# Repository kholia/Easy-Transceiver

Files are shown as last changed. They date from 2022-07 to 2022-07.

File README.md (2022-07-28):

### Easy-Transceiver

The whole design is modular, parametric (cost and others), field repairable,
and super extensible. It is almost trivial to add support for more `FSK digital
modes`.

The `Easy-Transceiver` hardware works with the native `Hybrid FT8 Radio`
Android app, and also with WSJT-X (running on RPi).

The `Easy-Transceiver` system can be built for around 3000 INR (~40 USD) or
less. We are working on reducing the cost to 2300 INR ;)

Author 1: LU2HES - https://github.com/agustinmartino

Author 2: Dhiru Kholia (VU3CER) - https://www.qrz.com/db/VU3CER/

TX chain:

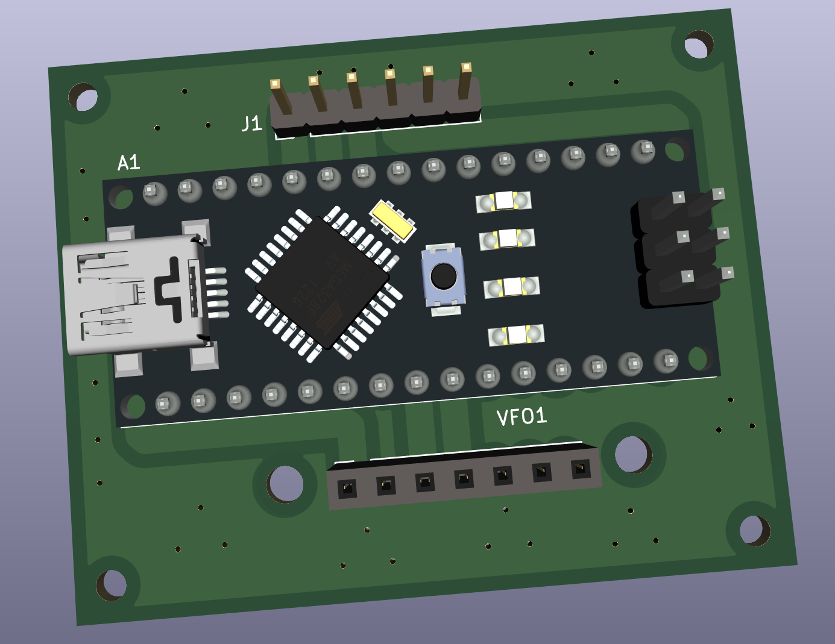
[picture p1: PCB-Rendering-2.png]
PCB-Rendering


RX chain (Easy-uSDX - optionally headless):

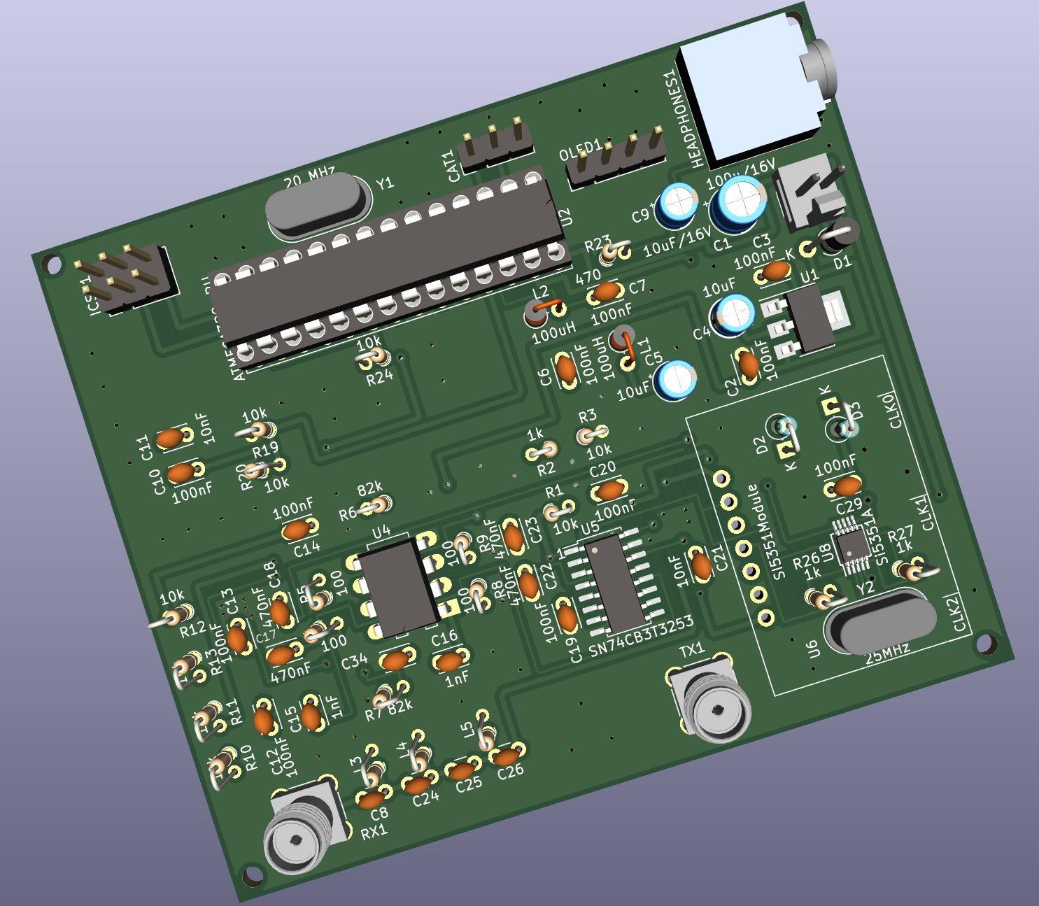
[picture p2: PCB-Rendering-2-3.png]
PCB-Rendering


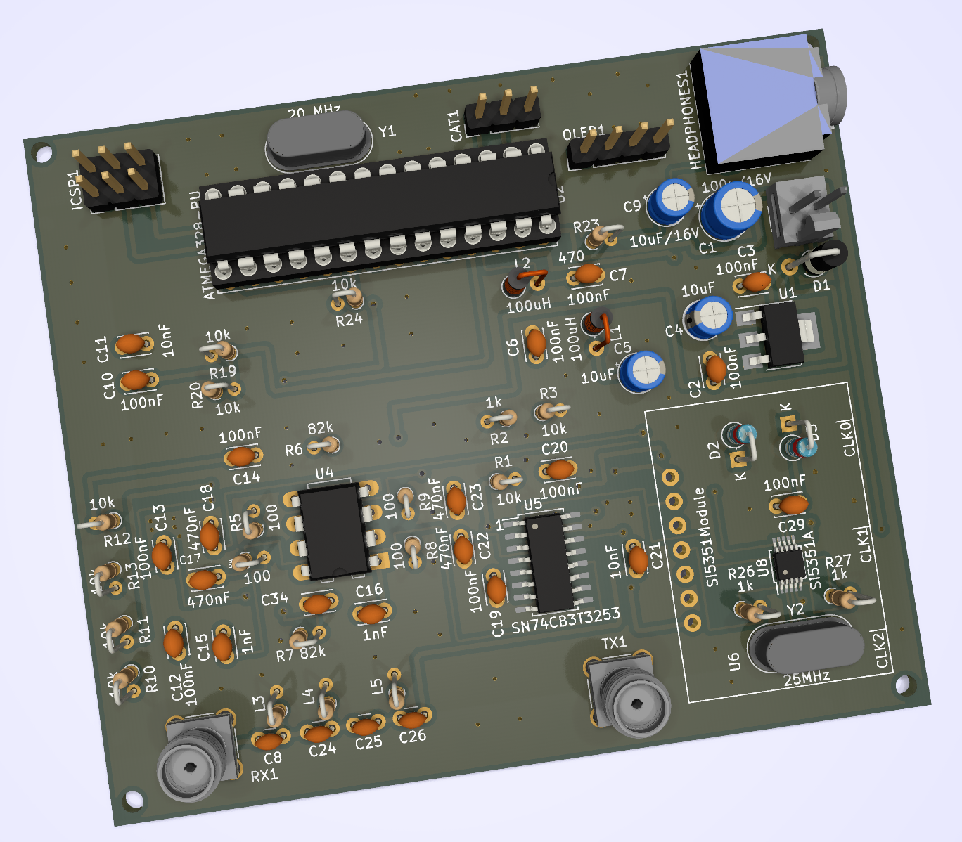
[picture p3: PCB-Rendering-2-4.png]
PCB-Rendering


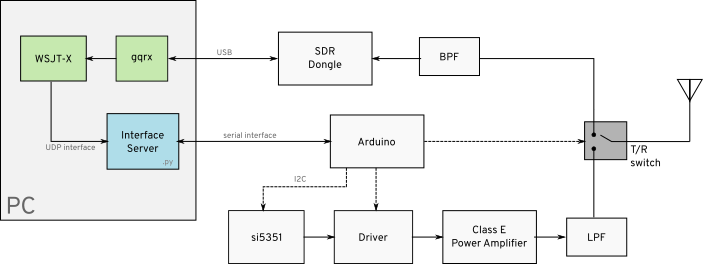
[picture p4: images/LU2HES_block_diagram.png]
Big Picture


QSO(s):

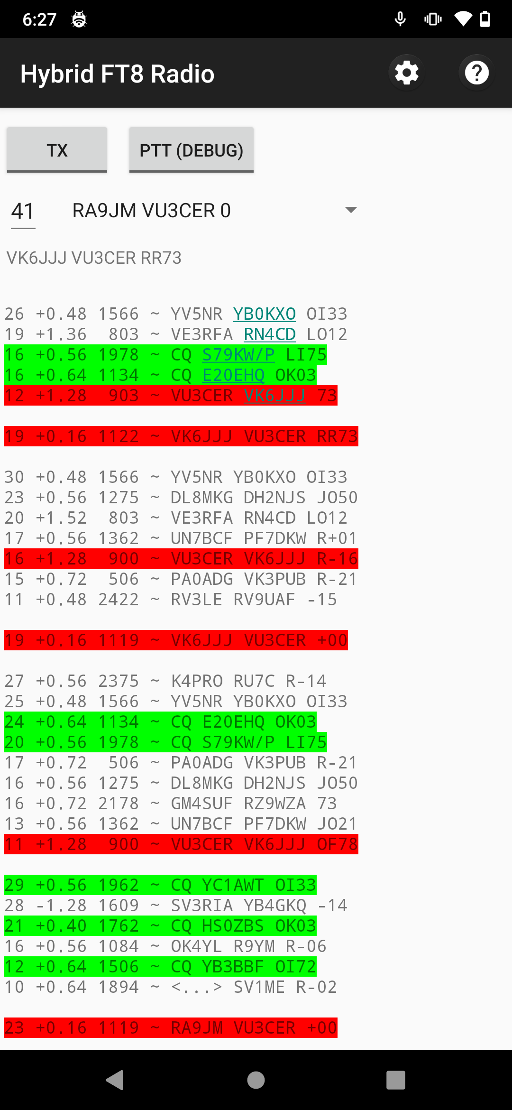
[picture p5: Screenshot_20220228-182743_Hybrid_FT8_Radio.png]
Android QSO

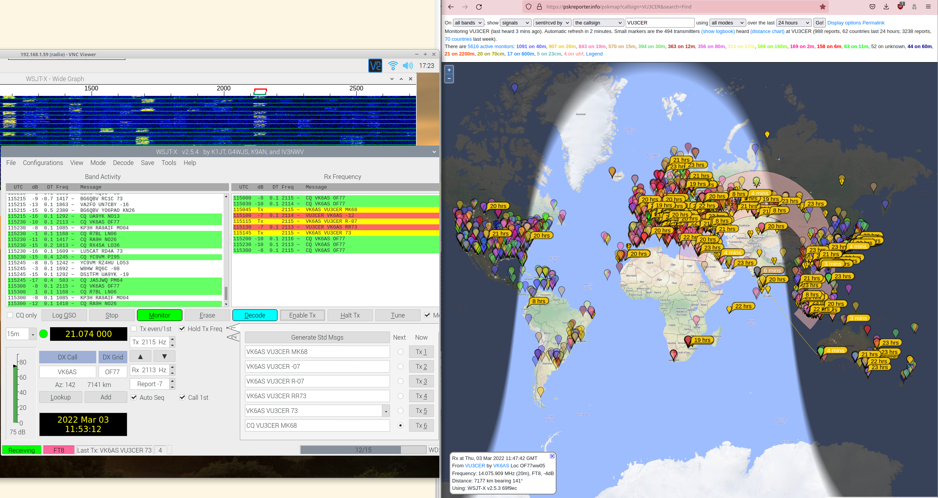
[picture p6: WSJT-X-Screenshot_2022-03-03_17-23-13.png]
WSJT-X on RPi QSO


QSOs over 15000 kms were made using this HW with PA150 (with around 37W ERP).

Argentina QSO

#### Notes

This will need a HF RF PA in most cases to be usable on the air.

UPDATE (January 2022): Check out our [cost-effective, and robust HF PA system](https://github.com/kholia/HF-PA-v5/).

#### Setup

- Use Python 3.10.x for maximum compatibility.

- Setup dependencies.

  `pip install -r requirements.txt`

#### T/R Switch

Check out our [cost-effective, and simple T/R switch design](https://github.com/kholia/Simple-TR-Switch/).

#### BCI Filter

Are you hearing broadcast AM signals in the background of the uSDX receiver? If
yes, a simple `BCI filter` can solve this problem easily enough.

Checkout the [RX BCI Filter](./HPF-BCI-Filter-RX) included in this repository.

#### BOM

- High Quality Female to Female Jumper Wire - 2500mA (Project Point)

- Female and male berg strip

- Arduino Nano v3 board - 450 INR - We will eliminate this requirement soon

- SN74CB3T3253DR (SOIC-16, Semikart) - ~200 INR

- Bunch of 100nF MLCC - 25 INR ('Emerging Technologies' Store -> ET)

- Bunch of 10nF MLCC - 10 INR

- Bunch of 1nF MLCC - 20 INR

- 4 x 470nF MLCC - 10 INR

- 1 x 1N5819 - 2 INR

- 1 x 1N4007 - 2 INR

- 1 x 7805 Linear Regulator - 15 INR

- 2 x 100uH inductor - 12 INR

- Si5351 Module - 470 INR (no delicate soldering required!)

  - Cheaper to get MS5351M from LCSC (in bulk for more experiments) - <= 100 INR

- Bunch of 10k resistors (MFR, ET / Project Point) - 25 INR

- Bunch of 1k resistors - 10 INR

- 1 x 1k 0.5W resistor - 5 INR

- 1 x 470 0.25W resistor - 5 INR

- 2 x 82k 0.25 resistor (MFR) - 5 INR

- 4 x 100 Ohm resistor (MFR) - 5 INR

- 1 x 3.5mm Stereo Socket ('PJ-307', https://www.electroncomponents.com/Stereo-Socket-3.5mm-connector-pcb) - 12 INR

- BCI Filter BOM - 2 x 2.2nF ceramic capacitor, 2 x 820pF (can be resistor shaped!), 3 * 2.2uH inductor axial

- 2 x SMA connectors (https://www.ktron.in/, SMA Straight - Female - Vertical Mount) - 50 INR

- ATmega328P (DIP-28) - 225 INR

- 20 MHz crystal - 10 INR

- LM4562NA - 220 INR (Semikart) OR NE5532AP (130 INR from Semikart, 30 INR locally from https://rarecomponents.com)

  The `NE5532` is widely faked - even https://www.electronicscomp.com/ sells a cheap knockoff!

  TIP: Get `TI make NE5532` from https://rarecomponents.com/.

- Misc: Copper clad board (glass epoxy one), Relimate male connectors + female
  cable, Male berg strip, Female-to-female dupont cables

  Get from https://www.electronicscomp.com/ and https://projectpoint.in/ shops.

- Total: Around 1500 to 1600 INR

#### BOM Sources

- https://robu.in/ (https://www.ktron.in/ has better pricing at times)

- https://www.electronicscomp.com/ (2.2uH Inductor)

- https://projectpoint.in/ (222 MLCC, 820pF MLCC)

- https://www.electroncomponents.com/2.2uh-inductor-inductance-coil (2.2uH Inductor)

#### Tips

Useful commands:

```
pacmd load-module module-null-sink sink_name=Virtual0
pacmd update-sink-proplist Virtual0 device.description=Virtual0
pacmd update-source-proplist Virtual0.monitor device.description=Virtual0
```

Use Gqrx and WSJT-X with a SDR device for initial frequency adjustment /
calibration. This is essential for WSPR functionality. FT8 is more
robust/tolerant of frequency deviations due to a much larger RX window.

#### References + Credits

- https://github.com/WB2CBA for the uSDX PCB

- https://github.com/kgoba/ft8_lib

- https://github.com/etherkit/JTEncode

- https://learn.adafruit.com/adafruit-si5351-clock-generator-breakout/wiring-and-test

- https://github.com/agustinmartino/wsjt_transceiver

- https://github.com/agustinmartino/wsjtx_transceiver_interface

- https://www.qrp-labs.com/synth/ms5351m.html

- https://github.com/kholia/Easy-Digital-Beacons-v1

- https://github.com/kholia/HF-Balcony-Antenna-System (fun!)

- https://github.com/kholia/SMPS-Noise-Filter

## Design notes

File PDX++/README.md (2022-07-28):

#### PDX++

A port of https://github.com/WB2CBA/ADX/ to Raspberry Pi Pico.

Bands covered: 80-meter to 10-meter.

The live FT8 audio can also be decoded on PC / RPi / Android phone.

Note: The PCB part is WIP (work-in-progress) at the moment.

####  Features

- Easy inbuilt and self-sufficient Si5351 calibration

- Native FT8 decoding on the Pico (via AA1GD)

- Native spotting (reporting to PSKReporter.info)

- Inbuilt BCI (broadcast interference) filter

#### BOM Sources

International users can buy from Mouser and DigiKey.

Here are some local BOM sources I use:

- https://inkocean.in/ - CD2003 (Chinese clone which is known to work fine)

- https://www.electronicscomp.com/ (SMD resistors + SMD caps + THT inductors)

  - All SMD caps and resistors are 1206 sized

- https://www.ktron.in/ (SMA connectors)

- https://www.comkey.in/ - Branded SMD stuff

- https://rarecomponents.com/store/1002 - NXP 1N4148

- https://projectpoint.in/ - CDIL 7805, PJ307 Stereo Socket

- https://www.evelta.com/l7805-positive-voltage-regulator-1-5a-5v/ (alternate)

- https://robu.in/product/si5351a-i2c-8-khz-160-mhz-clock-generator-breakout-board-module/

- https://robu.in/product/raspberry-pi-pico/

- https://etstore.in/ - OEN MICRO RELAY 46-05-2C

#### Credits

- https://github.com/WB2CBA/ADX/

- https://www.qrz.com/DB/VU2BGS

- https://github.com/aa1gd/pico_ft8_xcvr (AA1GD)

- https://github.com/lu7did/ADX

#### References

- https://github.com/kholia/pico_ft8_xcvr (firmware)

- https://f5npv.wordpress.com/homebrew-ft8qrp-afp-fsk-trx/

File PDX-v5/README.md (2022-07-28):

#### PDX

A port of https://github.com/WB2CBA/ADX/ to Raspberry Pi Pico.

PDX-v3 is like v2 but is adapted for manufacturing @ JLCPCB.

PDX-v4 is like v3 with minor bugfixes.

PDX-v5 is like v4 with ADC-voltage-limiting circuit.

Bands covered: 80-meter to 15-meter.

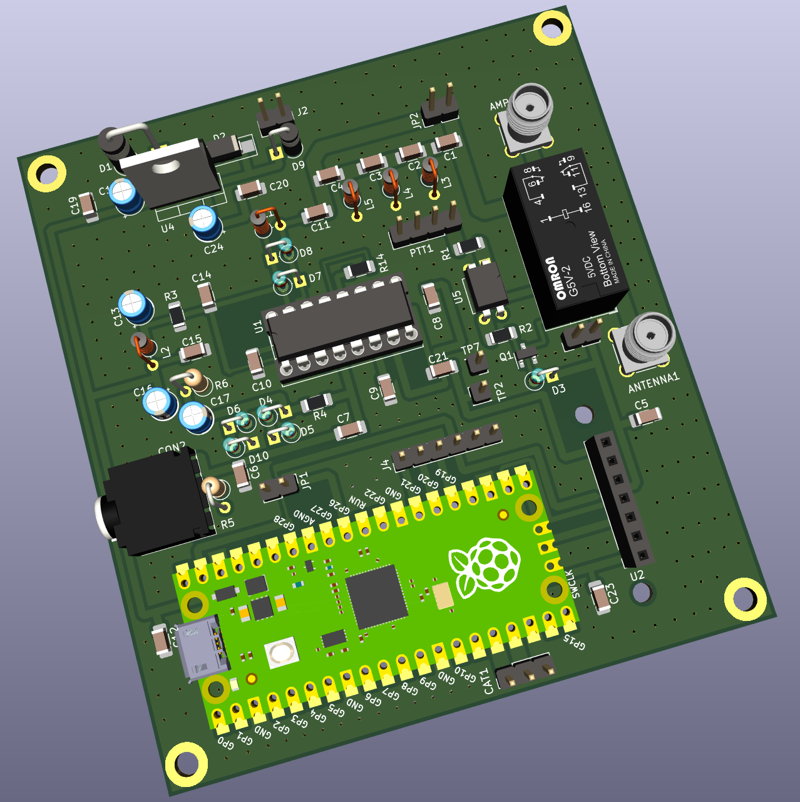
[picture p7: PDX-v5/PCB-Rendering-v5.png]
PCB Rendering


FT8 is natively decoded on the Pico using the code from the following
repository:

https://github.com/kholia/pico_ft8_xcvr

The `PDX RX Block` when combined with the following project becomes a complete
5W (to 10W!) digital FT8 transceiver.

- https://github.com/kholia/HF-PA-v6/tree/master/HF-PA-Combined

  Solid 3W+ on 15m, 6W+ on 20m, 10W+ on 40m band. All @ 13.8v only!

  Set high gate bias (even 4.2v!) for IRF510 for clean linear output.

The live FT8 audio can also be decoded on PC / RPi / Android phone.

#### BOM Sources

International users can buy from Mouser and DigiKey.

Here are some local BOM sources I use:

- https://inkocean.in/ - CD2003 (Chinese clone which is known to work fine)

- https://www.electronicscomp.com/ (SMD resistors + SMD caps + THT inductors)

  - All SMD caps and resistors are 1206 sized

- https://www.ktron.in/ (SMA connectors)

- https://www.comkey.in/ - Branded SMD stuff

- https://rarecomponents.com/store/1002 - NXP 1N4148

- https://projectpoint.in/ - CDIL 7805, PJ307 Stereo Socket

- https://www.evelta.com/l7805-positive-voltage-regulator-1-5a-5v/ (alternate)

- https://robu.in/product/si5351a-i2c-8-khz-160-mhz-clock-generator-breakout-board-module/

- https://robu.in/product/raspberry-pi-pico/

- https://etstore.in/ - OEN MICRO RELAY 46-05-2C

#### Credits

- https://github.com/WB2CBA/ADX/

- https://www.qrz.com/DB/VU2BGS

#### References

- https://f5npv.wordpress.com/homebrew-ft8qrp-afp-fsk-trx/

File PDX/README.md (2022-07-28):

#### PDX

[UPDATE] Check out [PDX-v2](https://github.com/kholia/Easy-Transceiver/tree/master/PDX-v2)
instead ;)

A port of https://github.com/WB2CBA/ADX/ to Raspberry Pi Pico.

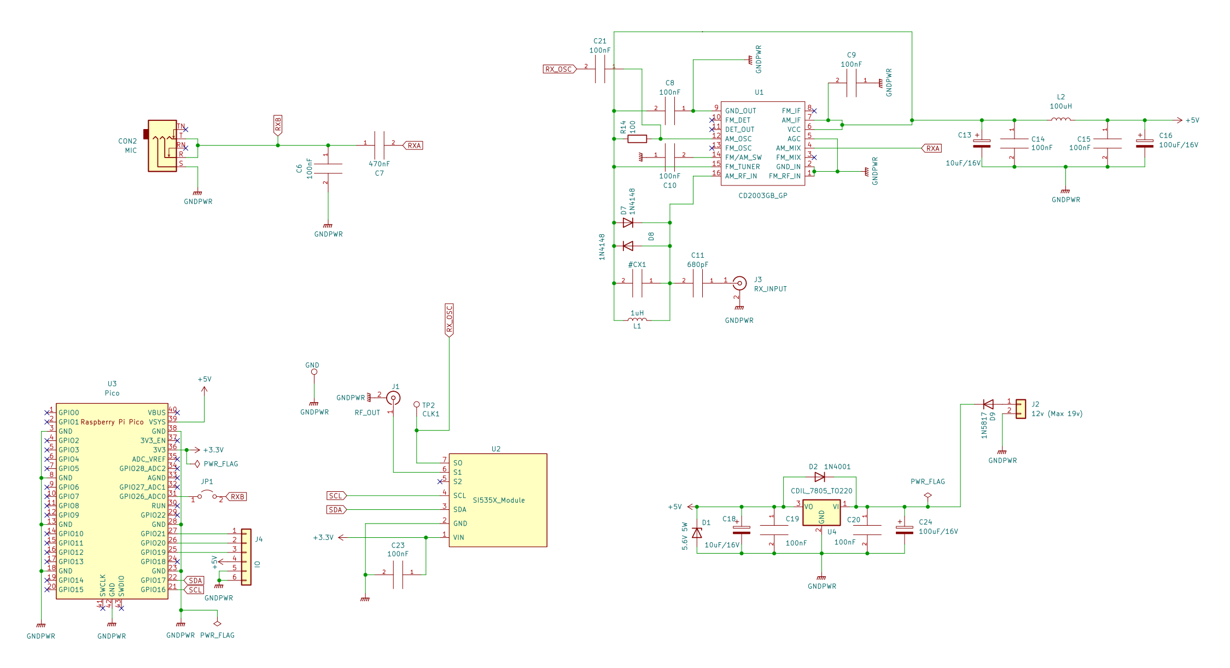
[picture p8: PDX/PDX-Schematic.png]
Schematic


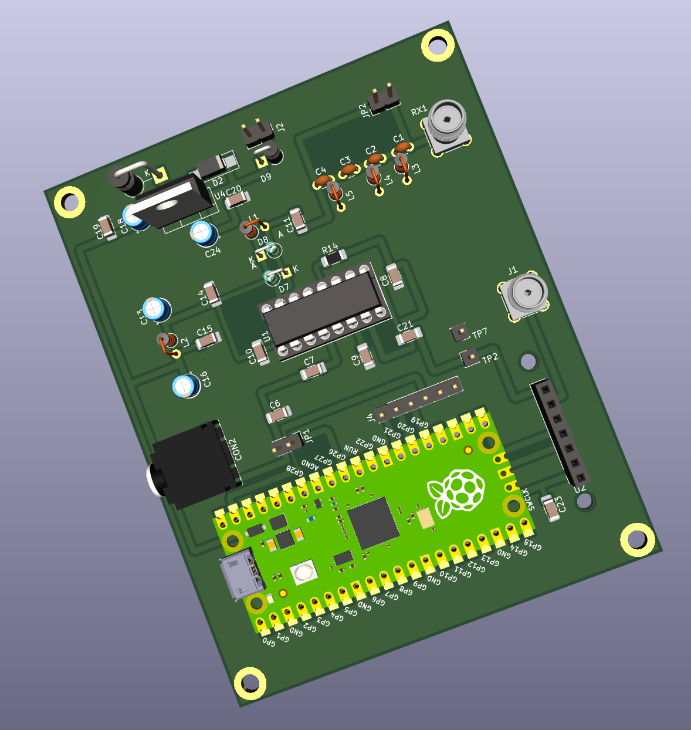
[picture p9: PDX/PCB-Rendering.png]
PCB Rendering


FT8 is natively decoded on the Pico using the code from the following
repository:

https://github.com/kholia/pico_ft8_xcvr

The `PDX RX Block` when combined with the following projects becomes a complete
digital FT8 transceiver.

- https://github.com/kholia/Simple-TR-Switch

- https://github.com/kholia/HF-PA-v6

The live FT8 audio can also be decoded on PC / RPi / Android phone.

#### Notes

PIN39 VSYS (used to power system, can be in range 1.8V-5.5V).

#### BOM Sources

International users can buy from Mouser and DigiKey.

Here are some local BOM sources I use:

- https://inkocean.in/ - CD2003 (Chinese clone which is known to work fine)

- https://www.electronicscomp.com/ (SMD resistors + SMD caps + THT inductors)

- https://www.ktron.in/ (SMA connectors)

- https://www.comkey.in/ - Branded SMD stuff

- https://rarecomponents.com/store/1002 - NXP 1N4148

- https://projectpoint.in/ - CDIL 7805, PJ307 Stereo Socket

- https://www.evelta.com/l7805-positive-voltage-regulator-1-5a-5v/ (alternate)

- https://robu.in/product/si5351a-i2c-8-khz-160-mhz-clock-generator-breakout-board-module/

- https://robu.in/product/raspberry-pi-pico/

#### Credits

- https://github.com/WB2CBA/ADX/

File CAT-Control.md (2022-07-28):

#### CAT control for Easy-uSDX

```
;ID;

;FD;

;FA00014074000;

;UK84;

;UK44;
```

#### CAT control for TX-chain

Check the code in the Android app, or check [this file](./Easy-Transceiver/Easy-Transceiver.ino). It
is pretty simple.

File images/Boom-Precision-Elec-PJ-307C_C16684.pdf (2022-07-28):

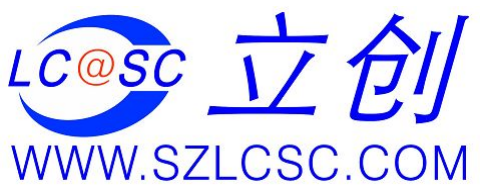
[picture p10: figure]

# 耳机接口

### 主要技术指标

产品 | 耳机接口 音频连接器 5 脚插座
产品型号 | PJ305C / 3.5MM
使用温度范围 | -30~+70℃
额定负荷 | DC 30V 0.5A
绝缘电阻 | >=100MΩ
接触电阻 | =<0.03Ω
耐压 | AC500V(50Hz)/min
颜色 | 黑色
插拔力 | 3~20N
寿命 | 10000 次

### 封装尺寸图

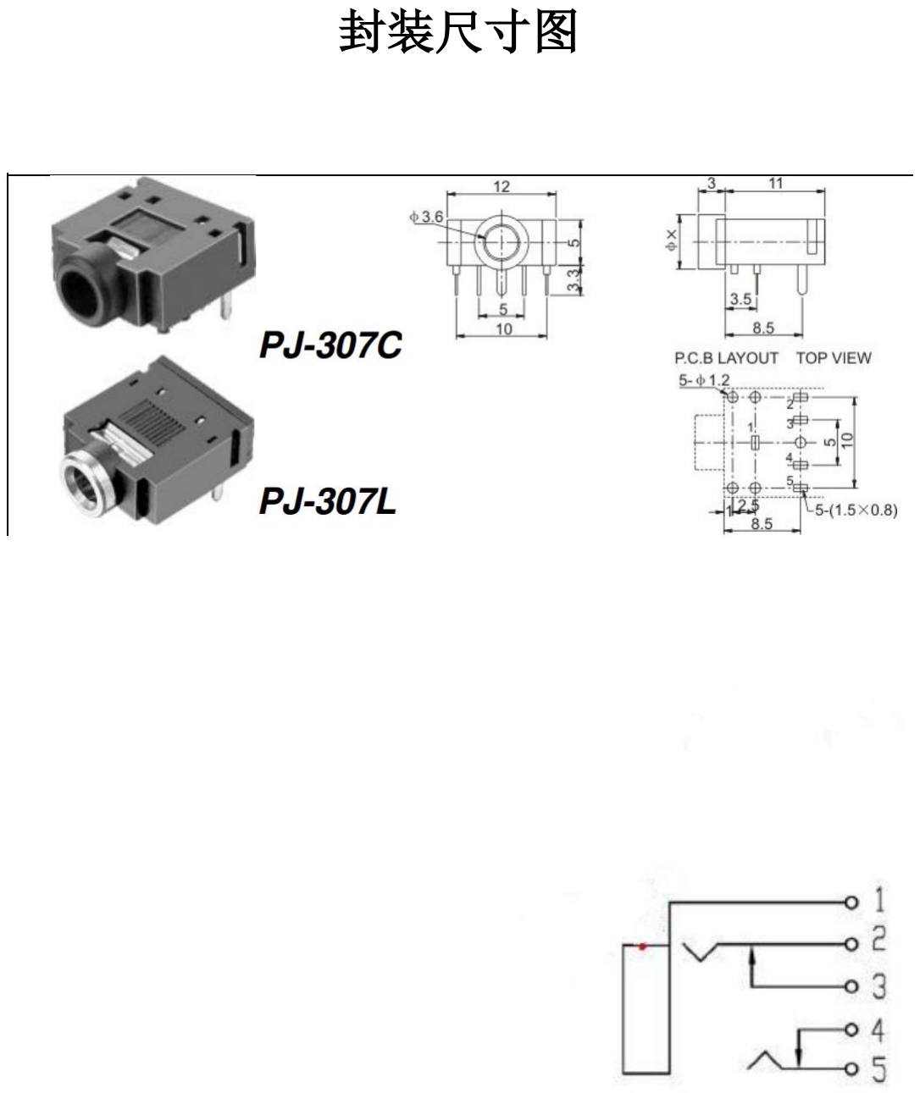
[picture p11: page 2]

### 产品图片

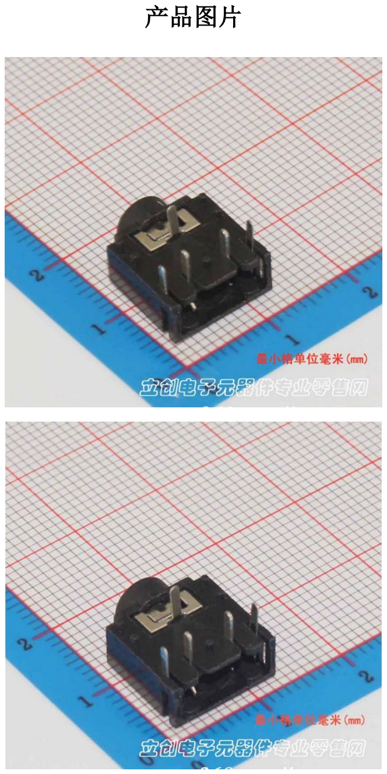
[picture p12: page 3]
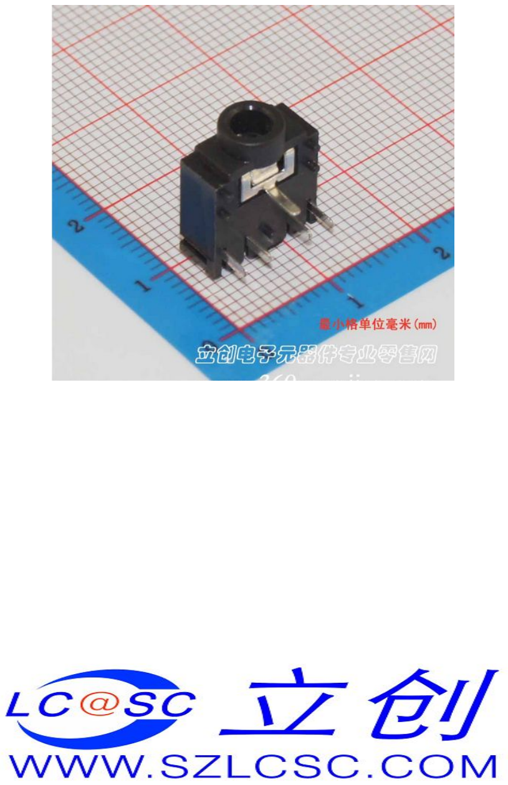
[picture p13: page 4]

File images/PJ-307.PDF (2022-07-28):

-307L

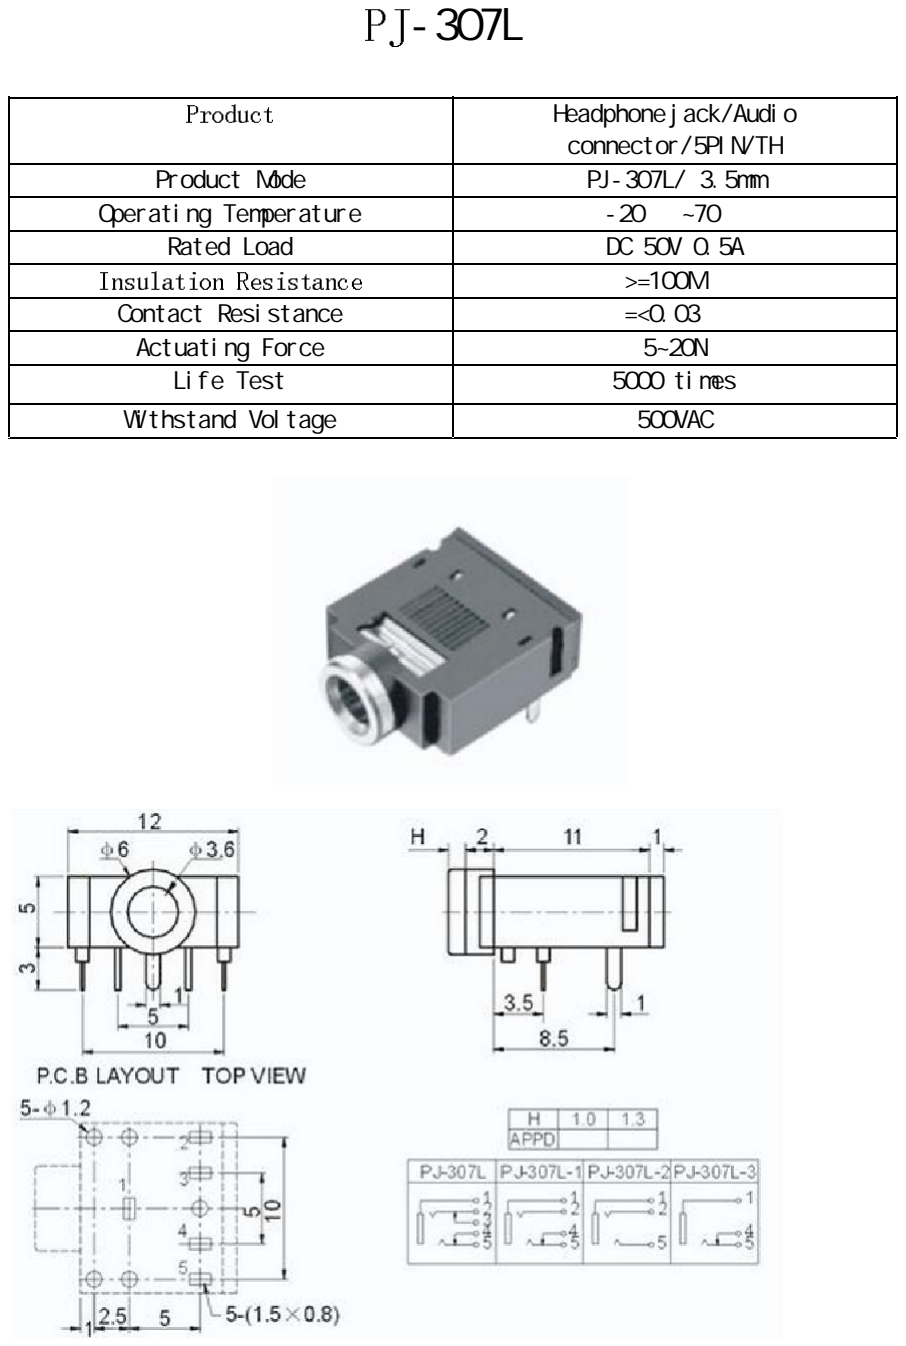
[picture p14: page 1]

Headphone jack/Audio
connector/5PIN/TH
Product Mode | PJ-307L/ 3.5mm
Operating Temperature | -20 ~70
Rated Load | DC 50V 0.5A
| >=100M
Contact Resistance | =<0.03
Actuating Force | 5~20N
Life Test | 5000 times
Withstand Voltage | 500VAC

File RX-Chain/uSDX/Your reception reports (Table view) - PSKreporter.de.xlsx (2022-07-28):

ID | Date | UTC | Age | Callsign | SNR (db) | Mode | Band | QRG (MHz) | Country | DXCC | Locator | QRB (km)
58 | 2022-02-17 | 02:42:59 | 51min | HC3RJ | -3 | FT8 | 20m | 14.0753 | Ecuador | HC | FI06AR | 16728
14 | 2022-02-17 | 03:25:44 | 8min | HC5F | - | FT8 | 20m | 14.0759 | Ecuador | HC | FI07LM | 16594
107 | 2022-02-16 | 22:31:45 | 5h:02m | HC1M | -8 | FT8 | 20m | 14.0753 | Ecuador | HC | FI09SR | 16402
120 | 2022-02-16 | 21:45:59 | 5h:48m | HC1DAZ | 1 | FT8 | 20m | 14.0759 | Ecuador | HC | FI09SV | 16391
66 | 2022-02-17 | 02:31:44 | 1h:02m | LU1VDF | -5 | FT8 | 20m | 14.0758 | Argentina | LU | FE48FW | 15910
79 | 2022-02-17 | 02:11:15 | 1h:23m | LU7KAT | -3 | FT8 | 20m | 14.0749 | Argentina | LU | FG72EP | 15798
104 | 2022-02-16 | 22:42:44 | 4h:51m | HK4VIC | -3 | FT8 | 20m | 14.0754 | Colombia | HK | FJ16XD | 15750
71 | 2022-02-17 | 02:20:15 | 1h:14m | HK4EIC | 6 | FT8 | 20m | 14.0751 | Colombia | HK | FJ26GF | 15694
95 | 2022-02-17 | 00:39:00 | 2h:55m | HK3C | -1 | FT8 | 20m | 14.0752 | Colombia | HK | FJ24WQ | 15686
122 | 2022-02-16 | 21:43:44 | 5h:50m | LU1HB | 1 | FT8 | 20m | 14.0761 | Argentina | LU | FF78LG | 15681
96 | 2022-02-17 | 00:17:29 | 3h:16m | HK3J | 4 | FT8 | 20m | 14.0755 | Colombia | HK | FJ24XR | 15676
102 | 2022-02-16 | 22:52:14 | 4h:42m | HK4EGW | -2 | FT8 | 20m | 14.0754 | Colombia | HK | FJ26LM | 15638
59 | 2022-02-17 | 02:38:29 | 55min | HK1O | -3 | FT8 | 20m | 14.0748 | Colombia | HK | FK21NA | 15291
139 | 2022-02-16 | 21:05:14 | 6h:29m | LU6DU | -3 | FT8 | 20m | 14.0752 | Argentina | LU | FF96LM | 15280
112 | 2022-02-16 | 22:13:29 | 5h:20m | LW6EEU | 4 | FT8 | 20m | 14.0761 | Argentina | LU | FF81XC | 15241
133 | 2022-02-16 | 21:20:59 | 6h:13m | LU6DPP | -1 | FT8 | 20m | 14.0761 | Argentina | LU | FF96VP27 | 15205
121 | 2022-02-16 | 21:45:59 | 5h:48m | LU3ETY | -3 | FT8 | 20m | 14.0754 | Argentina | LU | GF05LM | 15080
137 | 2022-02-16 | 21:14:14 | 6h:20m | LU5CAT | -4 | FT8 | 20m | 14.0763 | Argentina | LU | GF05SL | 15027
138 | 2022-02-16 | 21:09:44 | 6h:24m | LU9DNA | -1 | FT8 | 20m | 14.0758 | Argentina | LU | GF05SL | 15027
3 | 2022-02-17 | 03:32:29 | 1min | LU1DL | 9 | FT8 | 20m | 14.0748 | Argentina | LU | GF05SH | 15024
155 | 2022-02-16 | 19:48:15 | 7h:46m | LU6ETB | 2 | FT8 | 20m | 14.0748 | Argentina | LU | GF05UG59DJ | 15008
152 | 2022-02-16 | 20:01:45 | 7h:32m | LW7EDH | -6 | FT8 | 20m | 14.075 | Argentina | LU | GF11BR | 14904
158 | 2022-02-16 | 19:39:14 | 7h:55m | LU3CM | - | FT8 | 20m | 14.0753 | Argentina | LU | GF12NU47 | 14840
99 | 2022-02-16 | 23:09:59 | 4h:24m | YV5DRN | - | FT8 | 20m | 14.0749 | Venezuela | YV | FK60EG57 | 14739
114 | 2022-02-16 | 22:08:59 | 5h:25m | PJ4BZL | 4 | FT8 | 20m | 14.0748 | Bonaire | PJ4 | FK52UC | 14671
108 | 2022-02-16 | 22:29:29 | 5h:04m | YV5OIE | 4 | FT8 | 20m | 14.0754 | Venezuela | YV | FK60NL | 14660
105 | 2022-02-16 | 22:36:30 | 4h:57m | YV7WGA | 5 | FT8 | 20m | 14.076 | Venezuela | YV | FK80AX | 14368
65 | 2022-02-17 | 02:33:59 | 1h:00m | HI3Y | 5 | FT8 | 20m | 14.0748 | Dominican Republic | HI | FK49PL57AM | 14311
110 | 2022-02-16 | 22:25:00 | 5h:09m | HI3MM | -8 | FT8 | 20m | 14.0758 | Dominican Republic | HI | FK49PL | 14311
170 | 2022-02-16 | 19:09:59 | 8h:24m | PY2TC | -7 | FT8 | 20m | 14.0765 | Brazil | PY | GG59AN | 14176
132 | 2022-02-16 | 21:23:14 | 6h:11m | PP5ZP | -7 | FT8 | 20m | 14.0755 | Brazil | PY | GG53LC08 | 14157
113 | 2022-02-16 | 22:11:14 | 5h:23m | NP4LA | -3 | FT8 | 20m | 14.0755 | Puerto Rico | KP4 | FK68KC | 14143
127 | 2022-02-16 | 21:27:59 | 6h:06m | PP5AB | - | FT8 | 20m | 14.0754 | Brazil | PY | GG53PF | 14123
50 | 2022-02-17 | 02:56:29 | 37min | KP4HF | -8 | FT8 | 20m | 14.0762 | Puerto Rico | KP4 | FK68LM | 14106
61 | 2022-02-17 | 02:38:29 | 55min | KP4CAR | 6 | FT8 | 20m | 14.0757 | Puerto Rico | KP4 | FK68LM | 14106
103 | 2022-02-16 | 22:52:14 | 4h:42m | WP4KHE | - | FT8 | 20m | 14.0755 | Puerto Rico | KP4 | FK68LM | 14106
126 | 2022-02-16 | 21:32:29 | 6h:01m | KP4YRS | -4 | FT8 | 20m | 14.0755 | Puerto Rico | KP4 | FK68LM | 14106
191 | 2022-02-16 | 18:31:44 | 9h:02m | WP4G | -1 | FT8 | 20m | 14.0762 | Puerto Rico | KP4 | FK68WK25 | 14039
712 | 2022-02-16 | 12:15:44 | 15h:18m | KP3H | -5 | FT8 | 20m | 14.0753 | Puerto Rico | KP4 | FK78BE63 | 14037
101 | 2022-02-16 | 22:55:29 | 4h:38m | NP4JF | -9 | FT8 | 20m | 14.0758 | Puerto Rico | KP4 | FK68TX | 14019
40 | 2022-02-17 | 03:07:44 | 26min | KP2BH | -2 | FT8 | 20m | 14.0751 | US Virgin Islands | KP2 | FK77NQ55KV | 13993
53 | 2022-02-17 | 02:51:59 | 42min | KP2B | 3 | FT8 | 20m | 14.0749 | US Virgin Islands | KP2 | FK77OS | 13980
125 | 2022-02-16 | 21:36:59 | 5h:57m | PY2SAO | -4 | FT8 | 20m | 14.0745 | Brazil | PY | GG66PR | 13885
77 | 2022-02-17 | 02:15:59 | 1h:18m | PY2XL | -1 | FT8 | 20m | 14.076 | Brazil | PY | GG66QH | 13882
157 | 2022-02-16 | 19:39:14 | 7h:55m | PY2EBD | 2 | FT8 | 20m | 14.0745 | Brazil | PY | GG67PI | 13876
116 | 2022-02-16 | 21:54:59 | 5h:39m | PY2VA | 3 | FT8 | 20m | 14.0752 | Brazil | PY | GG66RJ21PM | 13873
128 | 2022-02-16 | 21:27:59 | 6h:06m | PT2CSM | 4 | FT8 | 20m | 14.0755 | Brazil | PY | GH64BF | 13869
111 | 2022-02-16 | 22:13:29 | 5h:20m | PY1EME | -3 | FT8 | 20m | 14.0758 | Brazil | PY | GG76QT | 13673
171 | 2022-02-16 | 19:09:59 | 8h:24m | PY4SM | -4 | FT8 | 20m | 14.0751 | Brazil | PY | GH80AA | 13549
32 | 2022-02-17 | 03:16:44 | 17min | KD6WW | -8 | FT8 | 20m | 14.0767 | United States | K | CM98JD13KS | 13533
154 | 2022-02-16 | 19:52:45 | 7h:41m | PY1SX | -7 | FT8 | 20m | 14.0749 | Brazil | PY | GG87MN | 13491
148 | 2022-02-16 | 20:19:59 | 7h:14m | PY4AIF | -3 | FT8 | 20m | 14.075 | Brazil | PY | GH80RM | 13393
11 | 2022-02-17 | 03:27:59 | 6min | AH6U | - | FT8 | 20m | 14.0749 | Hawaii | KH6 | BL10TT99 | 13016
60 | 2022-02-17 | 02:38:29 | 55min | W6OAT | 1 | FT8 | 20m | 14.0748 | United States | K | CN87RS60 | 12476
882 | 2022-02-16 | 06:02:15 | 21h:32m | ZL4YL | -3 | FT8 | 20m | 14.0767 | New Zealand | ZL | RF80LF | 12416
76 | 2022-02-17 | 02:15:59 | 1h:18m | PY7ZZ | 3 | FT8 | 20m | 14.0752 | Brazil | PY | HI21NX88UC | 12282
780 | 2022-02-16 | 11:05:59 | 16h:28m | 3D2MP | - | FT8 | 20m | 14.0758 | Fiji | 3D2 | RH91FV | 12125
943 | 2022-02-16 | 04:14:29 | 23h:19m | ZL1IF | -10 | FT8 | 20m | 14.076 | New Zealand | ZL | RF74DG | 12120
12 | 2022-02-17 | 03:27:59 | 6min | ZL3AAD | 2 | FT8 | 20m | 14.0751 | New Zealand | ZL | RE68LV | 12100
153 | 2022-02-16 | 19:55:00 | 7h:39m | ZL2BX | 4 | FT8 | 20m | 14.0748 | New Zealand | ZL | RE68KR | 12096
679 | 2022-02-16 | 12:56:14 | 14h:38m | VK7LW | -8 | FT8 | 20m | 14.0765 | Australia | VK | QE37QD | 10131
146 | 2022-02-16 | 20:24:15 | 7h:10m | VK7XX | 5 | FT8 | 20m | 14.0752 | Australia | VK | QE38NQ | 10041
746 | 2022-02-16 | 11:41:59 | 15h:52m | VK2PW | 3 | FT8 | 20m | 14.0764 | Australia | VK | QF56NE | 10030
740 | 2022-02-16 | 11:44:14 | 15h:50m | VK2PAA | 1 | FT8 | 20m | 14.0772 | Australia | VK | QF55IW | 10005
140 | 2022-02-16 | 21:02:59 | 6h:31m | VK4KC | -1 | FT8 | 20m | 14.0748 | Australia | VK | QG62LU97 | 9916
607 | 2022-02-16 | 14:12:45 | 13h:21m | VK4NBX | 1 | FT8 | 20m | 14.0766 | Australia | VK | QG63LM | 9889
100 | 2022-02-16 | 23:02:29 | 4h:31m | EA8MU | 8 | FT8 | 20m | 14.0755 | Canary Islands | EA8 | IL18 | 9850
130 | 2022-02-16 | 21:23:14 | 6h:11m | VK3VDX | -5 | FT8 | 20m | 14.0764 | Australia | VK | QF21LP | 9732
143 | 2022-02-16 | 20:31:29 | 7h:02m | VK3ZH | - | FT8 | 20m | 14.0755 | Australia | VK | QF22OE | 9725
612 | 2022-02-16 | 14:10:30 | 13h:23m | VK3PUB | -1 | FT8 | 20m | 14.0752 | Australia | VK | QF22LD | 9707
733 | 2022-02-16 | 11:48:44 | 15h:45m | VK3TX | -10 | FT8 | 20m | 14.0769 | Australia | VK | QF22JC | 9696
151 | 2022-02-16 | 20:01:45 | 7h:32m | VK4WBX | -6 | FT8 | 20m | 14.0748 | Australia | VK | QG63 | 9456
118 | 2022-02-16 | 21:50:29 | 5h:43m | EA8OM | -6 | FT8 | 20m | 14.0749 | Canary Islands | EA8 | IL18LM | 9141
147 | 2022-02-16 | 20:22:00 | 7h:12m | EA8DKV | 12 | FT8 | 20m | 14.0757 | Canary Islands | EA8 | IL18QJ | 9106
160 | 2022-02-16 | 19:36:59 | 7h:57m | EA8CVR | 9 | FT8 | 20m | 14.0757 | Canary Islands | EA8 | IL18TJ51 | 9083
129 | 2022-02-16 | 21:27:59 | 6h:06m | EA8DIB | 1 | FT8 | 20m | 14.0766 | Canary Islands | EA8 | IL18UK | 9074
136 | 2022-02-16 | 21:14:14 | 6h:20m | EA8TN | -4 | FT8 | 20m | 14.0751 | Canary Islands | EA8 | IL18UK | 9074
149 | 2022-02-16 | 20:13:14 | 7h:21m | EA8CZF | - | FT8 | 20m | 14.0759 | Canary Islands | EA8 | IL18UK | 9074
124 | 2022-02-16 | 21:39:14 | 5h:55m | VK5SFA | 8 | FT8 | 20m | 14.0768 | Australia | VK | PF95IC32 | 9058
717 | 2022-02-16 | 12:06:44 | 15h:27m | VK5VAM | -6 | FT8 | 20m | 14.076 | Australia | VK | PF95HD | 9049
109 | 2022-02-16 | 22:27:15 | 5h:07m | EA8AOC | -1 | FT8 | 20m | 14.0759 | Canary Islands | EA8 | IL27FR | 9025
131 | 2022-02-16 | 21:23:14 | 6h:11m | VK5PO | 1 | FT8 | 20m | 14.0759 | Australia | VK | PF95GN15 | 9019
144 | 2022-02-16 | 20:29:14 | 7h:05m | EA8ACW | 4 | FT8 | 20m | 14.0762 | Canary Islands | EA8 | IL28GC | 9006
142 | 2022-02-16 | 20:38:14 | 6h:56m | EA8JB | 3 | FT8 | 20m | 14.0749 | Canary Islands | EA8 | IL28GD | 9004
135 | 2022-02-16 | 21:16:29 | 6h:17m | EA8IE | -2 | FT8 | 20m | 14.0745 | Canary Islands | EA8 | IL28HC | 8998
164 | 2022-02-16 | 19:18:59 | 8h:15m | EC8AXS | 7 | FT8 | 20m | 14.0755 | Canary Islands | EA8 | IL38FW | 8800
165 | 2022-02-16 | 19:18:59 | 8h:15m | CS2F | -8 | FT8 | 20m | 14.0754 | Portugal | CT | IN50 | 8726
173 | 2022-02-16 | 19:07:44 | 8h:26m | CT1BSD | -10 | FT8 | 20m | 14.0767 | Portugal | CT | IM58KQ39 | 8157
561 | 2022-02-16 | 14:56:59 | 12h:37m | RA9CQO | -10 | FT8 | 20m | 14.0767 | Russia-AS | UA9 | RQ56 | 8068
381 | 2022-02-16 | 16:57:59 | 10h:36m | EA1TF | 1 | FT8 | 20m | 14.0762 | Spain | EA | IN53LM | 8058
246 | 2022-02-16 | 17:53:29 | 9h:40m | EA1DSK | 5 | FT8 | 20m | 14.0763 | Spain | EA | IN52RV | 8029
181 | 2022-02-16 | 18:45:14 | 8h:49m | EA7JUJ | -3 | FT8 | 20m | 14.0748 | Spain | EA | IM66VM | 7947
183 | 2022-02-16 | 18:33:59 | 9h:00m | EB7BVL | 3 | FT8 | 20m | 14.0766 | Spain | EA | IM67UH | 7939
255 | 2022-02-16 | 17:51:14 | 9h:43m | EA7KC | -6 | FT8 | 20m | 14.0761 | Spain | EA | IM66WQ44 | 7936
156 | 2022-02-16 | 19:46:00 | 7h:48m | V51MA | 4 | FT8 | 20m | 14.075 | Namibia | V5 | JG87MO | 7687
697 | 2022-02-16 | 12:35:59 | 14h:58m | YC9UBG | 6 | FT8 | 20m | 14.0775 | Indonesia | YB | QI07IL | 7670
258 | 2022-02-16 | 17:51:14 | 9h:43m | EA1EQ | - | FT8 | 20m | 14.0757 | Spain | EA | IN83FJ | 7619
447 | 2022-02-16 | 16:24:44 | 11h:09m | MMØHVU | -8 | FT8 | 20m | 14.0771 | Scotland | GM | IO85DV55 | 7556
220 | 2022-02-16 | 18:06:59 | 9h:27m | 2WØRQC | -1 | FT8 | 20m | 14.0755 | Wales | GW | IO81KM | 7529
453 | 2022-02-16 | 16:22:29 | 11h:11m | G4DFQ | 2 | FT8 | 20m | 14.0769 | England | G | IO82KU | 7524
328 | 2022-02-16 | 17:22:44 | 10h:11m | G4HUK | -8 | FT8 | 20m | 14.0749 | England | G | IO80MW | 7519
525 | 2022-02-16 | 15:28:29 | 12h:05m | EA5J | -7 | FT8 | 20m | 14.0771 | Spain | EA | IM98HF | 7497
472 | 2022-02-16 | 16:04:29 | 11h:29m | ZS4VDL | 7 | FT8 | 20m | 14.0773 | South Africa | ZS | KF29XM | 7493
310 | 2022-02-16 | 17:29:15 | 10h:05m | GJØKYZ | 12 | FT8 | 20m | 14.0762 | Jersey | GJ | IN89WF42 | 7467
671 | 2022-02-16 | 13:07:29 | 14h:26m | EA5GPC | 11 | FT8 | 20m | 14.0769 | Spain | EA | IM98LM | 7464
240 | 2022-02-16 | 17:57:59 | 9h:36m | EA5UI | 3 | FT8 | 20m | 14.0756 | Spain | EA | IM98MC | 7462
159 | 2022-02-16 | 19:36:59 | 7h:57m | EA5RO | -8 | FT8 | 20m | 14.0752 | Spain | EA | IM99LM | 7453
342 | 2022-02-16 | 17:16:00 | 10h:18m | EA5BCO | -5 | FT8 | 20m | 14.0751 | Spain | EA | IM98PG | 7438
309 | 2022-02-16 | 17:31:30 | 10h:02m | EA5IZX | -4 | FT8 | 20m | 14.0753 | Spain | EA | IM98QI | 7430
395 | 2022-02-16 | 16:48:59 | 10h:45m | G1III | 1 | FT8 | 20m | 14.0758 | England | G | IO93DT | 7429
337 | 2022-02-16 | 17:18:15 | 10h:16m | EA5ITW | -2 | FT8 | 20m | 14.0762 | Spain | EA | IM98RN | 7421
452 | 2022-02-16 | 16:22:29 | 11h:11m | GØKPH | -8 | FT8 | 20m | 14.076 | England | G | IO92FH40 | 7418
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

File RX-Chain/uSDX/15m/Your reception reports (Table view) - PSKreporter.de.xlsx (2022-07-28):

ID | Date | UTC | Age | Callsign | SNR (db) | Mode | Band | QRG (MHz) | Country | DXCC | Locator | QRB (km)
50 | 2022-02-19 | 20:02:30 | 6h:44m | LU3QBQ | -6 | FT8 | 15m | 21.075 | Argentina | LU | FF66LM | 15826
53 | 2022-02-19 | 19:28:00 | 7h:19m | LU7KAT | -9 | FT8 | 15m | 21.0752 | Argentina | LU | FG72EP | 15798
55 | 2022-02-19 | 19:25:59 | 7h:21m | LU2EI | -6 | FT8 | 15m | 21.0753 | Argentina | LU | FF94NN30 | 15227
56 | 2022-02-19 | 19:25:59 | 7h:21m | LU1AH | -4 | FT8 | 15m | 21.0744 | Argentina | LU | GF05LM | 15080
59 | 2022-02-19 | 19:01:14 | 7h:46m | LW2DLY | -6 | FT8 | 15m | 21.0758 | Argentina | LU | GF05RN | 15036
58 | 2022-02-19 | 19:05:59 | 7h:41m | LU4DCW | 4 | FT8 | 15m | 21.0759 | Argentina | LU | GF05SL | 15027
51 | 2022-02-19 | 19:45:59 | 7h:01m | LU1AVU | -7 | FT8 | 15m | 21.0752 | Argentina | LU | GF05SK | 15026
52 | 2022-02-19 | 19:30:14 | 7h:17m | LW7EDH | - | FT8 | 15m | 21.0759 | Argentina | LU | GF11BR | 14904
54 | 2022-02-19 | 19:25:59 | 7h:21m | CW1C | -6 | FT8 | 15m | 21.0747 | Uruguay | CX | GF15UC | 14825
49 | 2022-02-19 | 20:46:44 | 6h:00m | PU5JVA | -6 | FT8 | 15m | 21.075 | Brazil | PY | GG43LR | 14351
48 | 2022-02-19 | 21:19:29 | 5h:27m | PU5GER | -5 | FT8 | 15m | 21.0748 | Brazil | PY | GG53LM | 14154
62 | 2022-02-19 | 18:05:14 | 8h:42m | PP5AMP | -2 | FT8 | 15m | 21.0746 | Brazil | PY | GG52TN42 | 14095
64 | 2022-02-19 | 16:54:29 | 9h:52m | PU2OAJ | -3 | FT8 | 15m | 21.0744 | Brazil | PY | GG66KL | 13931
60 | 2022-02-19 | 18:30:14 | 8h:17m | PY2LK | - | FT8 | 15m | 21.0751 | Brazil | PY | GG66QL | 13880
61 | 2022-02-19 | 18:25:14 | 8h:22m | PY2EBD | -9 | FT8 | 15m | 21.0745 | Brazil | PY | GG67PI | 13876
57 | 2022-02-19 | 19:11:15 | 7h:36m | PY7ZZW | -2 | FT8 | 15m | 21.0746 | Brazil | PY | HI21 | 13079
1037 | 2022-02-19 | 03:43:14 | 23h:04m | VK7XX | - | FT8 | - | 0 | Australia | VK | QE38NQ | 10041
573 | 2022-02-19 | 10:22:44 | 16h:24m | VK2PW | -1 | FT8 | 15m | 21.076 | Australia | VK | QF56NE | 10030
1035 | 2022-02-19 | 03:43:14 | 23h:04m | VK2MBK | -5 | FT8 | - | 0 | Australia | VK | QF57SK | 10013
103 | 2022-02-19 | 14:56:30 | 11h:50m | EA8AT | -6 | FT8 | 15m | 21.0755 | Canary Islands | EA8 | IL17AQ | 9254
775 | 2022-02-19 | 08:14:44 | 18h:32m | EA8JK | -1 | FT8 | 15m | 21.0751 | Canary Islands | EA8 | IL18CP | 9207
502 | 2022-02-19 | 11:03:14 | 15h:44m | EA8ACW | 3 | FT8 | 15m | 21.0749 | Canary Islands | EA8 | IL28GC | 9006
80 | 2022-02-19 | 15:15:59 | 11h:31m | CT1DKS | -7 | FT8 | 15m | 21.0755 | Portugal | CT | IM59OS06 | 8107
930 | 2022-02-19 | 06:12:45 | 20h:34m | RK9S | 1 | FT8 | 15m | 21.0748 | Russia-AS | UA9 | IR07 | 8070
581 | 2022-02-19 | 10:18:14 | 16h:29m | EA5JAT | 3 | FT8 | 15m | 21.0749 | Spain | EA | IM99 | 8054
376 | 2022-02-19 | 12:16:14 | 14h:31m | EA1DSK | -7 | FT8 | 15m | 21.0763 | Spain | EA | IN52RV | 8029
638 | 2022-02-19 | 09:46:45 | 17h:00m | EG485FIM | -2 | FT8 | 15m | 21.0749 | Spain | EA | IM66VM | 7947
546 | 2022-02-19 | 10:40:44 | 16h:06m | EA7PY | -4 | FT8 | 15m | 21.0766 | Spain | EA | IM66WK | 7941
776 | 2022-02-19 | 08:14:44 | 18h:32m | EA7OC | 4 | FT8 | 15m | 21.0751 | Spain | EA | IM77NU | 7806
614 | 2022-02-19 | 10:00:14 | 16h:47m | EA4HKF | 2 | FT8 | 15m | 21.075 | Spain | EA | IM78WQ | 7729
174 | 2022-02-19 | 13:39:29 | 13h:07m | M1MIT | 1 | FT8 | 15m | 21.0752 | England | G | JO02 | 7702
366 | 2022-02-19 | 12:20:44 | 14h:26m | EA7DJN | 5 | FT8 | 15m | 21.0763 | Spain | EA | IM88EC | 7694
346 | 2022-02-19 | 12:31:59 | 14h:15m | EC4TR | -9 | FT8 | 15m | 21.0746 | Spain | EA | IN80ER | 7658
308 | 2022-02-19 | 12:49:59 | 13h:57m | EA7L | -2 | FT8 | 15m | 21.075 | Spain | EA | IM86QS | 7626
66 | 2022-02-19 | 16:05:59 | 10h:41m | ZS6HON | 4 | FT8 | 15m | 21.0755 | South Africa | ZS | KG44 | 7620
672 | 2022-02-19 | 09:22:15 | 17h:25m | EA4D | - | FT8 | 15m | 21.0751 | Spain | EA | IN80KN | 7618
492 | 2022-02-19 | 11:09:59 | 15h:37m | MMØCEZ | -5 | FT8 | 15m | 21.0759 | Scotland | GM | IO75XU72 | 7577
92 | 2022-02-19 | 15:05:00 | 11h:42m | EA4CH | -4 | FT8 | 15m | 21.077 | Spain | EA | IN80WB | 7539
723 | 2022-02-19 | 08:55:15 | 17h:52m | GØMRR | 1 | FT8 | 15m | 21.0748 | England | G | IO81LC | 7524
186 | 2022-02-19 | 13:37:14 | 13h:10m | GJØKYZ | 3 | FT8 | 15m | 21.0752 | Jersey | GJ | IN89WF42 | 7467
701 | 2022-02-19 | 09:08:45 | 17h:38m | MØDSR | -5 | FT8 | 15m | 21.0755 | England | G | IO82XX12 | 7451
77 | 2022-02-19 | 15:20:29 | 11h:26m | EA5IAG | -5 | FT8 | 15m | 21.0755 | Spain | EA | IM97PW | 7442
242 | 2022-02-19 | 13:14:44 | 13h:32m | ON4UY | 1 | FT8 | 15m | 21.0751 | Belgium | ON | JO20 | 7420
81 | 2022-02-19 | 15:15:59 | 11h:31m | EA5KY | -2 | FT8 | 15m | 21.0748 | Spain | EA | IM98TK | 7408
190 | 2022-02-19 | 13:34:59 | 13h:12m | MØHYE | -3 | FT8 | 15m | 21.0758 | England | G | IO94HW | 7408
86 | 2022-02-19 | 15:11:45 | 11h:35m | EA5JEG | 4 | FT8 | 15m | 21.0755 | Spain | EA | IM99TJ | 7398
655 | 2022-02-19 | 09:35:44 | 17h:11m | F1TXI | - | FT8 | 15m | 21.0759 | France | F | IN96LM | 7398
629 | 2022-02-19 | 09:53:29 | 16h:53m | EA5HM | 2 | FT8 | 15m | 21.076 | Spain | EA | IM99TL71 | 7397
417 | 2022-02-19 | 11:43:29 | 15h:03m | G3ZQH | - | FT8 | 15m | 21.0744 | England | G | IO92KV05 | 7390
100 | 2022-02-19 | 15:00:45 | 11h:46m | EA5WI | - | FT8 | 15m | 21.0759 | Spain | EA | IM99XX | 7363
607 | 2022-02-19 | 10:04:44 | 16h:42m | EA3HMM | 5 | FT8 | 15m | 21.0751 | Spain | EA | JN00GS | 7307
264 | 2022-02-19 | 13:10:14 | 13h:37m | F5NBQ | 4 | FT8 | 15m | 21.0758 | France | F | JN05DN | 7300
793 | 2022-02-19 | 07:56:59 | 18h:50m | GØKSC | 5 | FT8 | 15m | 21.0752 | England | G | JO01GM97 | 7275
176 | 2022-02-19 | 13:37:14 | 13h:10m | F4BHK | -3 | FT8 | 15m | 21.075 | France | F | JN08LT | 7243
681 | 2022-02-19 | 09:20:00 | 17h:27m | EA3NT | -2 | FT8 | 15m | 21.0766 | Spain | EA | JN01PC09HI | 7242
97 | 2022-02-19 | 15:02:59 | 11h:44m | EA3CB | 4 | FT8 | 15m | 21.0757 | Spain | EA | JN01UF | 7206
534 | 2022-02-19 | 10:49:44 | 15h:57m | EA3VM | -4 | FT8 | 15m | 21.0753 | Spain | EA | JN01UF | 7206
616 | 2022-02-19 | 10:00:14 | 16h:47m | EB3JT | - | FT8 | 15m | 21.0745 | Spain | EA | JN01UI42 | 7206
314 | 2022-02-19 | 12:47:44 | 13h:59m | VK6DW | 2 | FT8 | 15m | 21.0757 | Australia | VK | OF88AA | 7193
1033 | 2022-02-19 | 03:43:14 | 23h:04m | VK6RO | 9 | FT8 | - | 0 | Australia | VK | OF77XX13 | 7190
940 | 2022-02-19 | 06:03:59 | 20h:43m | VK6OZ | -2 | FT8 | 15m | 21.075 | Australia | VK | OF77WW | 7188
875 | 2022-02-19 | 06:56:59 | 19h:50m | EA3BS | 2 | FT8 | 15m | 21.0756 | Spain | EA | JN01XK | 7184
337 | 2022-02-19 | 12:36:29 | 14h:10m | F5MYH | 6 | FT8 | 15m | 21.0746 | France | F | JN07VO41HE | 7181
499 | 2022-02-19 | 11:05:29 | 15h:41m | F5ADE | - | FT8 | 15m | 21.0753 | France | F | JN06VU57 | 7181
345 | 2022-02-19 | 12:31:59 | 14h:15m | F4FQY | 1 | FT8 | 15m | 21.0756 | France | F | JN03WX | 7180
204 | 2022-02-19 | 13:28:14 | 13h:19m | F5BZB | -6 | FT8 | 15m | 21.0764 | France | F | JN03XU92 | 7174
538 | 2022-02-19 | 10:45:14 | 16h:02m | F1BHB | 3 | FT8 | 15m | 21.0759 | France | F | JN09XP32 | 7171
550 | 2022-02-19 | 10:36:14 | 16h:11m | F6HCP | -6 | FT8 | 15m | 21.0754 | France | F | JN09XQ20 | 7171
442 | 2022-02-19 | 11:32:14 | 15h:15m | VK6BMA | -1 | FT8 | 15m | 21.0755 | Australia | VK | OF78VC | 7170
839 | 2022-02-19 | 07:25:29 | 19h:21m | EA3BBA | -4 | FT8 | 15m | 21.0748 | Spain | EA | JN11BK | 7170
356 | 2022-02-19 | 12:27:29 | 14h:19m | F6AOJ | -8 | FT8 | 15m | 21.075 | France | F | JN08XO96 | 7169
136 | 2022-02-19 | 14:08:44 | 12h:38m | IIØOGB | 3 | FT8 | 15m | 21.0748 | Italy | I | JM49 | 7165
579 | 2022-02-19 | 10:20:29 | 16h:26m | 7X3WPL | 9 | FT8 | 15m | 21.0757 | Algeria | 7X | JM13MM | 7156
221 | 2022-02-19 | 13:21:29 | 13h:25m | F8MRQ | -3 | FT8 | 15m | 21.0747 | France | F | JN17CT | 7150
705 | 2022-02-19 | 09:06:30 | 17h:40m | F6DPT | -2 | FT8 | 15m | 21.0744 | France | F | JN18DO65 | 7145
531 | 2022-02-19 | 10:51:59 | 15h:55m | DK1HZ | -8 | FT8 | 15m | 21.0757 | Germany | DL | JN48 | 7118
82 | 2022-02-19 | 15:15:59 | 11h:31m | EA6C | -6 | FT8 | 15m | 21.0754 | Balearic Islands | EA6 | JM19LI | 7112
536 | 2022-02-19 | 10:47:29 | 15h:59m | F4EBT | -6 | FT8 | 15m | 21.0749 | France | F | JN18LM | 7095
237 | 2022-02-19 | 13:16:59 | 13h:30m | F4GTB | -5 | FT8 | 15m | 21.0761 | France | F | JN18NT | 7084
621 | 2022-02-19 | 09:58:00 | 16h:49m | JA8EPO | -1 | FT8 | 15m | 21.0751 | Japan | JA | QN23IU | 7074
427 | 2022-02-19 | 11:38:59 | 15h:08m | ZS6KG | -4 | FT8 | 15m | 21.0746 | South Africa | ZS | KG34HT | 7068
554 | 2022-02-19 | 10:33:59 | 16h:13m | ON3ANY | 3 | FT8 | 15m | 21.0752 | Belgium | ON | JO10TR | 7056
763 | 2022-02-19 | 08:23:44 | 18h:23m | JA8LJL | -7 | FT8 | 15m | 21.0763 | Japan | JA | QN23FV | 7053
675 | 2022-02-19 | 09:22:15 | 17h:25m | ON4CN | -3 | FT8 | 15m | 21.075 | Belgium | ON | JO10VJ85 | 7043
679 | 2022-02-19 | 09:20:00 | 17h:27m | ON7BL | 1 | FT8 | 15m | 21.0747 | Belgium | ON | JO10VJ46 | 7043
402 | 2022-02-19 | 11:52:29 | 14h:54m | ZR6JR | 12 | FT8 | 15m | 21.0751 | South Africa | ZS | KG33WU | 7039
919 | 2022-02-19 | 06:19:29 | 20h:27m | SMØDTK | -10 | FT8 | 15m | 21.0758 | Sweden | SM | JO58 | 7030
270 | 2022-02-19 | 13:07:59 | 13h:39m | ON75AST | -1 | FT8 | 15m | 21.0755 | Belgium | ON | JO20AW | 7028
159 | 2022-02-19 | 13:43:59 | 13h:03m | F4IFO | 3 | FT8 | 15m | 21.0756 | France | F | JN29AG | 7019
330 | 2022-02-19 | 12:38:44 | 14h:08m | PE1OBZ | 1 | FT8 | 15m | 21.0752 | Netherlands | PA | JO21FW | 7007
667 | 2022-02-19 | 09:26:45 | 17h:20m | F1ORJ | 6 | FT8 | 15m | 21.0753 | France | F | JN25BK11 | 7001
320 | 2022-02-19 | 12:43:14 | 14h:04m | ON3XMU | -8 | FT8 | 15m | 21.0752 | Belgium | ON | JO20FK | 6996
456 | 2022-02-19 | 11:27:44 | 15h:19m | PAØLDE | -6 | FT8 | 15m | 21.0745 | Netherlands | PA | JO22JP94 | 6991
700 | 2022-02-19 | 09:11:00 | 17h:36m | PF88ANT | 3 | FT8 | 15m | 21.0767 | Netherlands | PA | JO22KJ | 6983
210 | 2022-02-19 | 13:28:14 | 13h:19m | PA3BOM | 4 | FT8 | 15m | 21.0753 | Netherlands | PA | JO21LM | 6969
682 | 2022-02-19 | 09:20:00 | 17h:27m | ON75ONZ | 6 | FT8 | 15m | 21.0751 | Belgium | ON | JO20LW | 6964
224 | 2022-02-19 | 13:21:29 | 13h:25m | ON7BM | -4 | FT8 | 15m | 21.0754 | Belgium | ON | JO20LM | 6961
741 | 2022-02-19 | 08:39:29 | 18h:07m | UAØFO | -7 | FT8 | 15m | 21.0763 | Russia-AS | UA9 | QN16HW | 6915
773 | 2022-02-19 | 08:16:59 | 18h:30m | RAØFF | 4 | FT8 | 15m | 21.0749 | Russia-AS | UA9 | QN16HW | 6915
201 | 2022-02-19 | 13:30:29 | 13h:16m | PA3CPS | -1 | FT8 | 15m | 21.0751 | Netherlands | PA | JO32BH | 6897
471 | 2022-02-19 | 11:16:44 | 15h:30m | F5DBT | -5 | FT8 | 15m | 21.0749 | France | F | JN23RI55LA | 6892
977 | 2022-02-19 | 05:21:30 | 21h:25m | JH8VLR | 6 | FT8 | 15m | 21.0744 | Japan | JA | QN14EB | 6887
460 | 2022-02-19 | 11:23:29 | 15h:23m | PA4TT | 2 | FT8 | 15m | 21.0752 | Netherlands | PA | JO33FD | 6885
452 | 2022-02-19 | 11:29:59 | 15h:17m | PA3EAP | -8 | FT8 | 15m | 21.0759 | Netherlands | PA | JO32FO54 | 6878
274 | 2022-02-19 | 13:05:44 | 13h:41m | PA7TT | -10 | FT8 | 15m | 21.0748 | Netherlands | PA | JO33HA13 | 6872
213 | 2022-02-19 | 13:25:59 | 13h:21m | PA3EPP | -1 | FT8 | 15m | 21.0754 | Netherlands | PA | JO32JT | 6858
151 | 2022-02-19 | 13:52:59 | 12h:54m | HB3XAI | -8 | FT8 | 15m | 21.0752 | Switzerland | HB | JN36BE68 | 6848
472 | 2022-02-19 | 11:16:44 | 15h:30m | DL1STG | 4 | FT8 | 15m | 21.0754 | Germany | DL | JO31LM | 6831
510 | 2022-02-19 | 11:00:59 | 15h:46m | DK7TX | 2 | FT8 | 15m | 21.0757 | Germany | DL | JO31LM | 6831
170 | 2022-02-19 | 13:41:44 | 13h:05m | DNØUKW | 5 | FT8 | 15m | 21.0754 | Germany | DL | JO31LG | 6828
889 | 2022-02-19 | 06:45:59 | 20h:01m | DFØTWN | -2 | FT8 | 15m | 21.0751 | Germany | DL | JO32OH | 6824
606 | 2022-02-19 | 10:04:44 | 16h:42m | DO7PD | -8 | FT8 | 15m | 21.0746 | Germany | DL | JO31OV | 6819
494 | 2022-02-19 | 11:07:44 | 15h:39m | HB9HIT | -9 | FT8 | 15m | 21.0745 | Switzerland | HB | JN36HN | 6812
433 | 2022-02-19 | 11:38:59 | 15h:08m | OZ5AGJ | 3 | FT8 | 15m | 21.0758 | Denmark | OZ | JO47IA | 6807
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

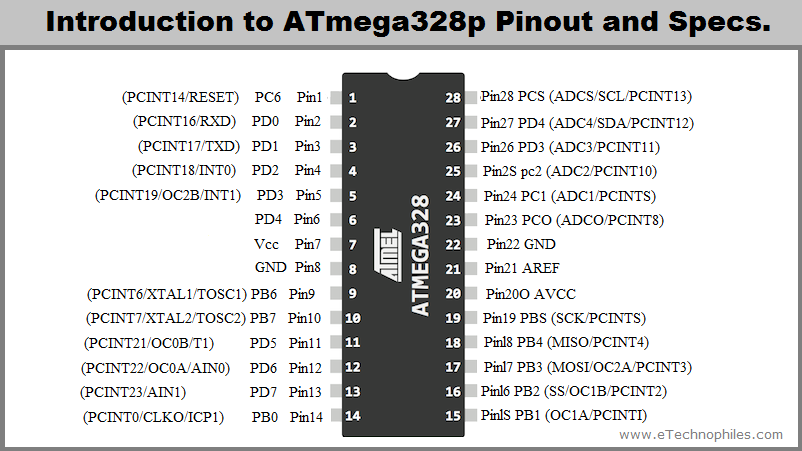
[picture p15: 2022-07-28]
images/ATmega328p-pinout-and-Specs-in-detail.png

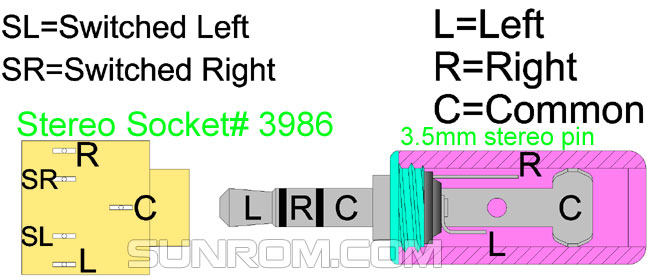
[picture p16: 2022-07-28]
images/stereo-socket-pinout.jpg

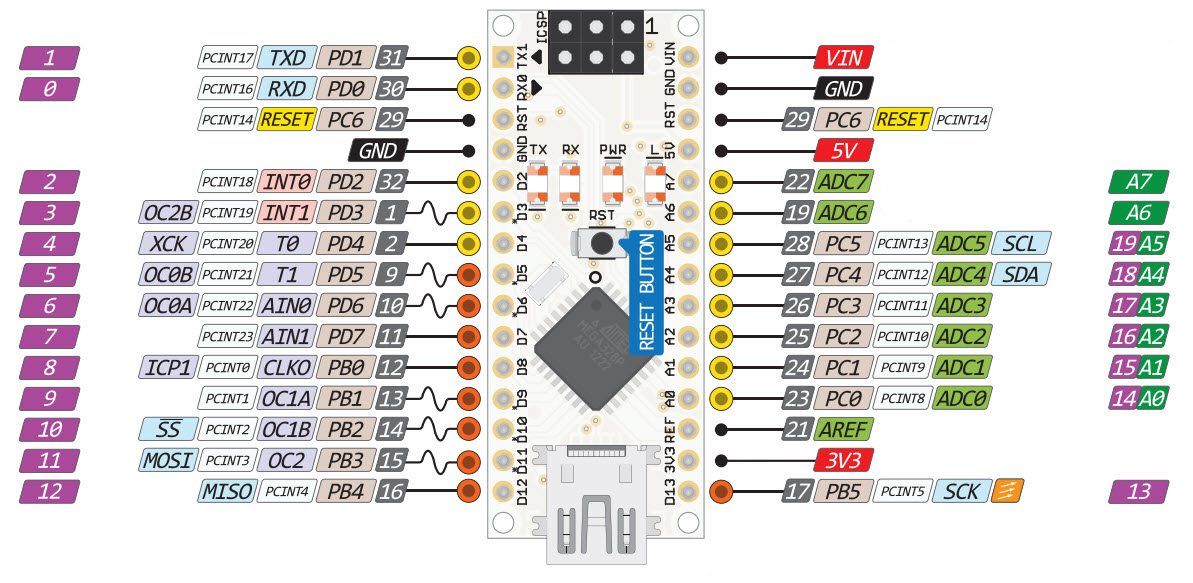
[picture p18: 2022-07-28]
images/Arduino-Nano-Pinout.jpeg

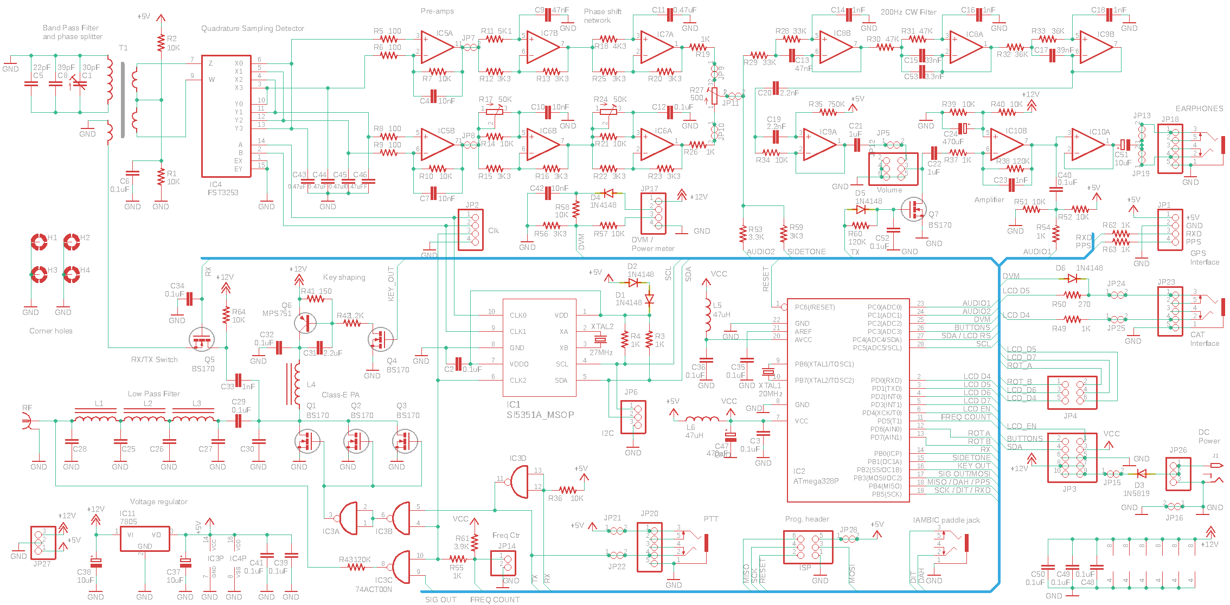
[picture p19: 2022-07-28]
references/QCX+ Schematic.png

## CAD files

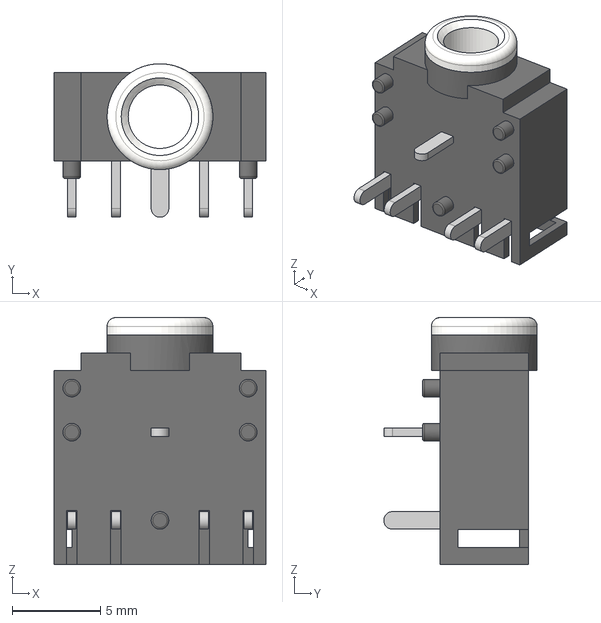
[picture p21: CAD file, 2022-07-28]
BoB-For-2003/models/pj-307.step
12.0 x 8.70 x 14.0 mm

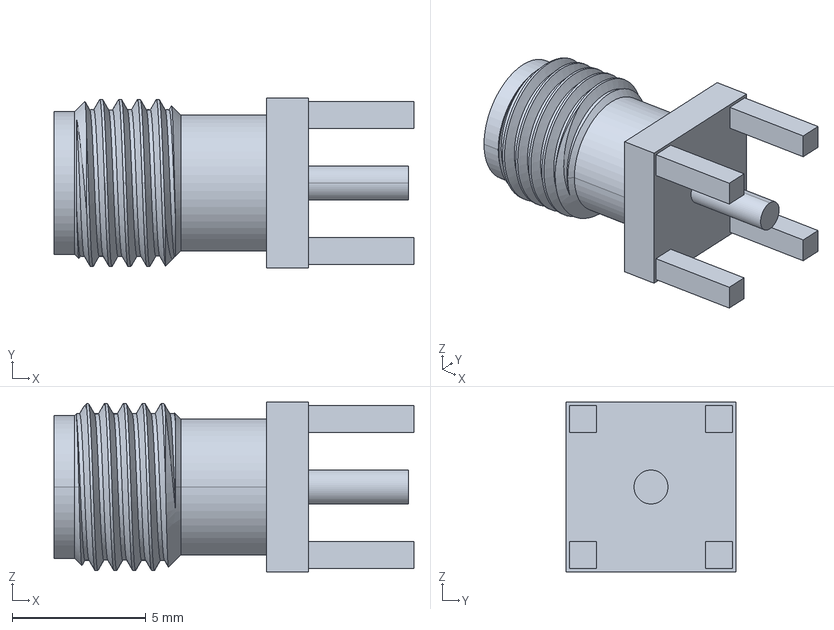
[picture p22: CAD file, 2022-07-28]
PDX++/models/901-144.stp
13.5 x 6.35 x 6.35 mm

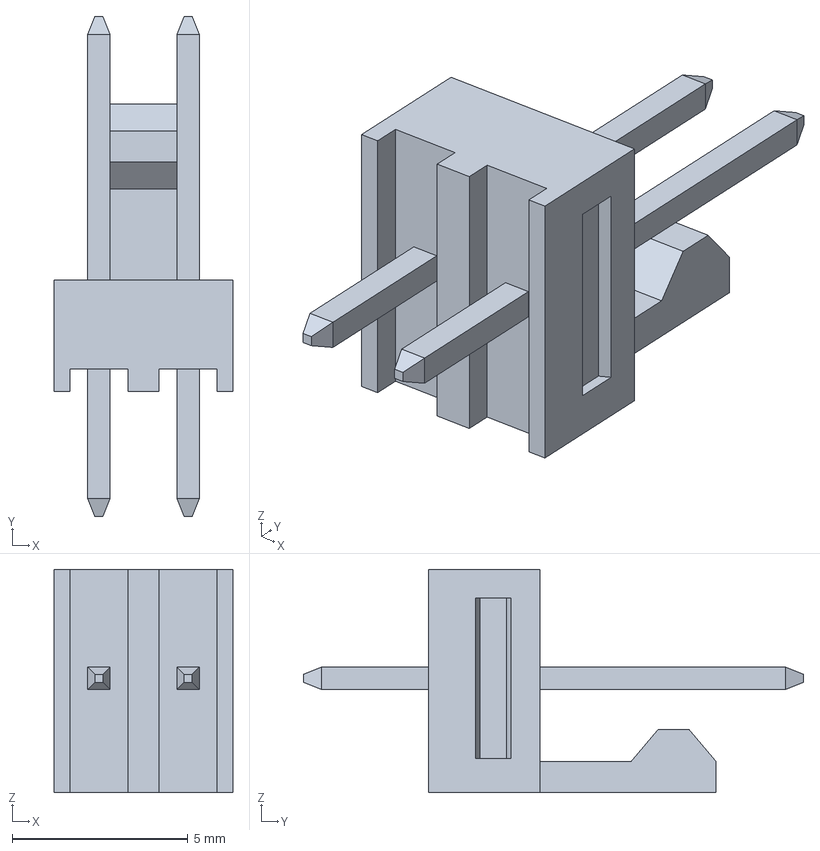
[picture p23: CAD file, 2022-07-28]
Easy-uSDX/models/22-23-2021.stp
5.08 x 14.2 x 6.35 mm

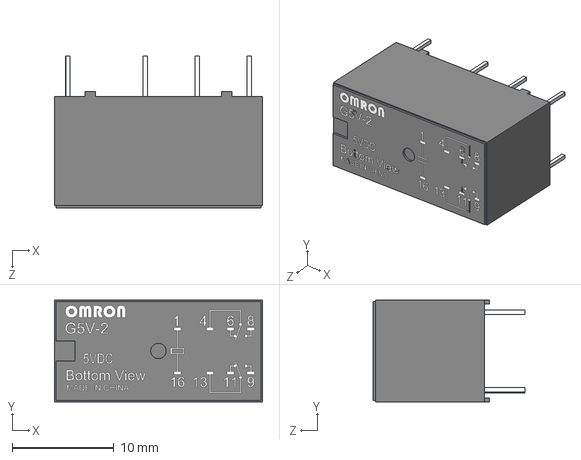
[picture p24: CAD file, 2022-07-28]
PDX++/models/User Library-OMRON G5V-2.STEP
20.4 x 10.0 x 14.9 mm

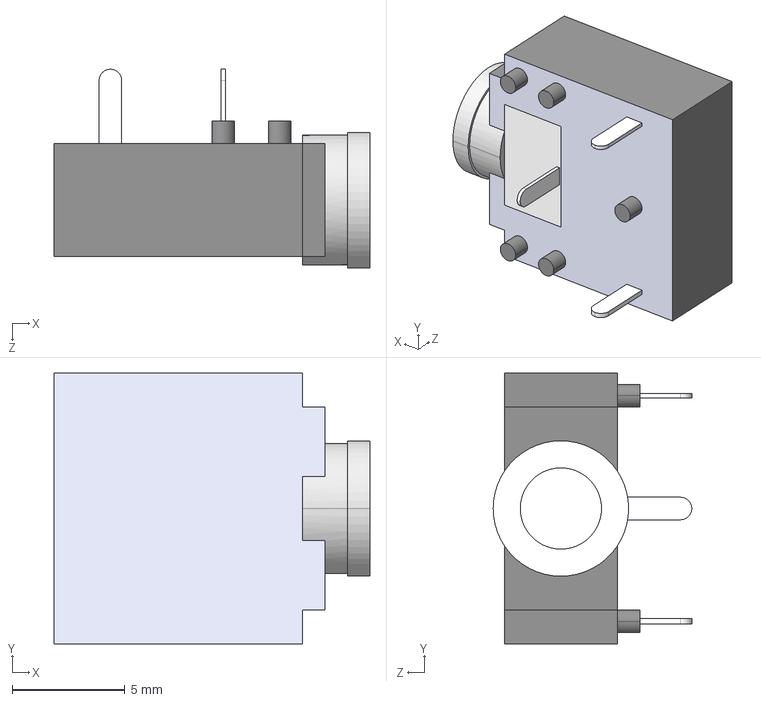
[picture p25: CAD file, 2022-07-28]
Easy-uSDX/models/CUI_DEVICES_SJ1-3523N.step
14.0 x 12.0 x 8.80 mm

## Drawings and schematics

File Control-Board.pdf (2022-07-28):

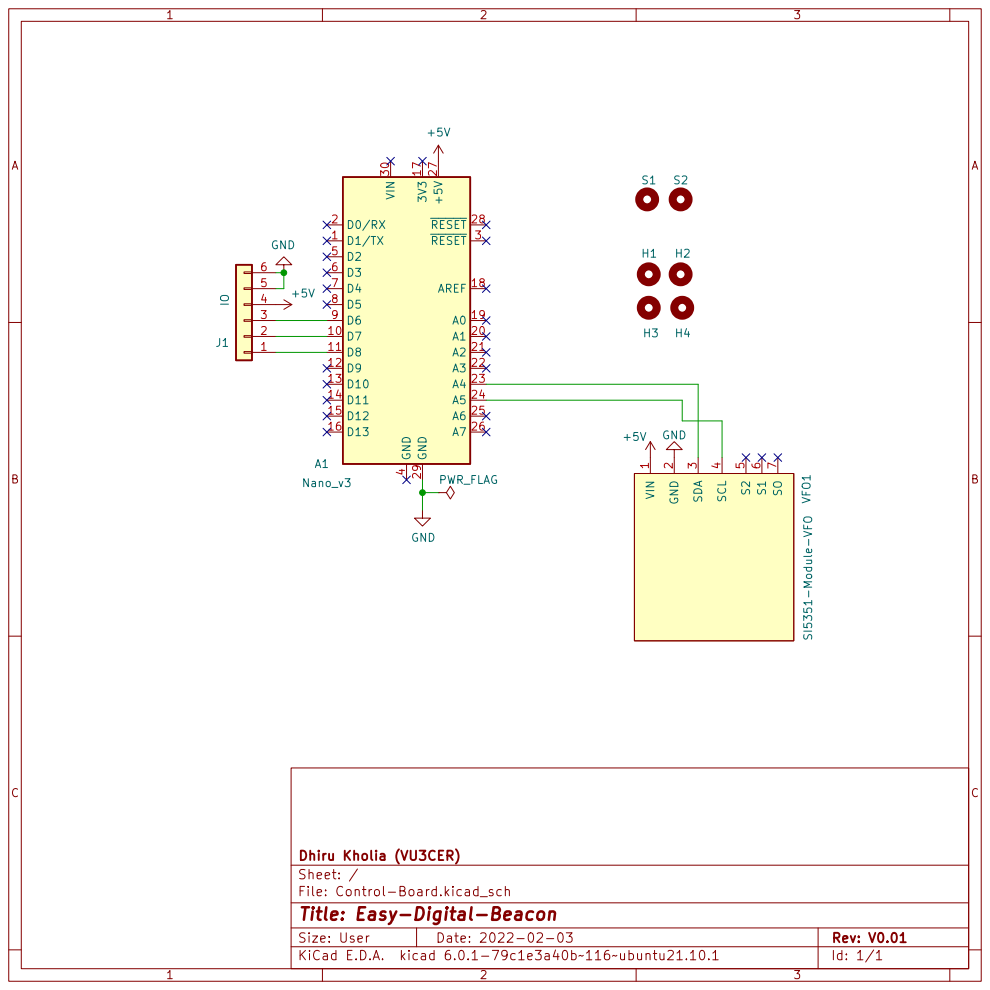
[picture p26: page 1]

File: Control-Board.kicad_sch Sheet: / Dhiru Kholia (VU3CER)

Id: 1/1 Title: Easy-Digital-Beacon

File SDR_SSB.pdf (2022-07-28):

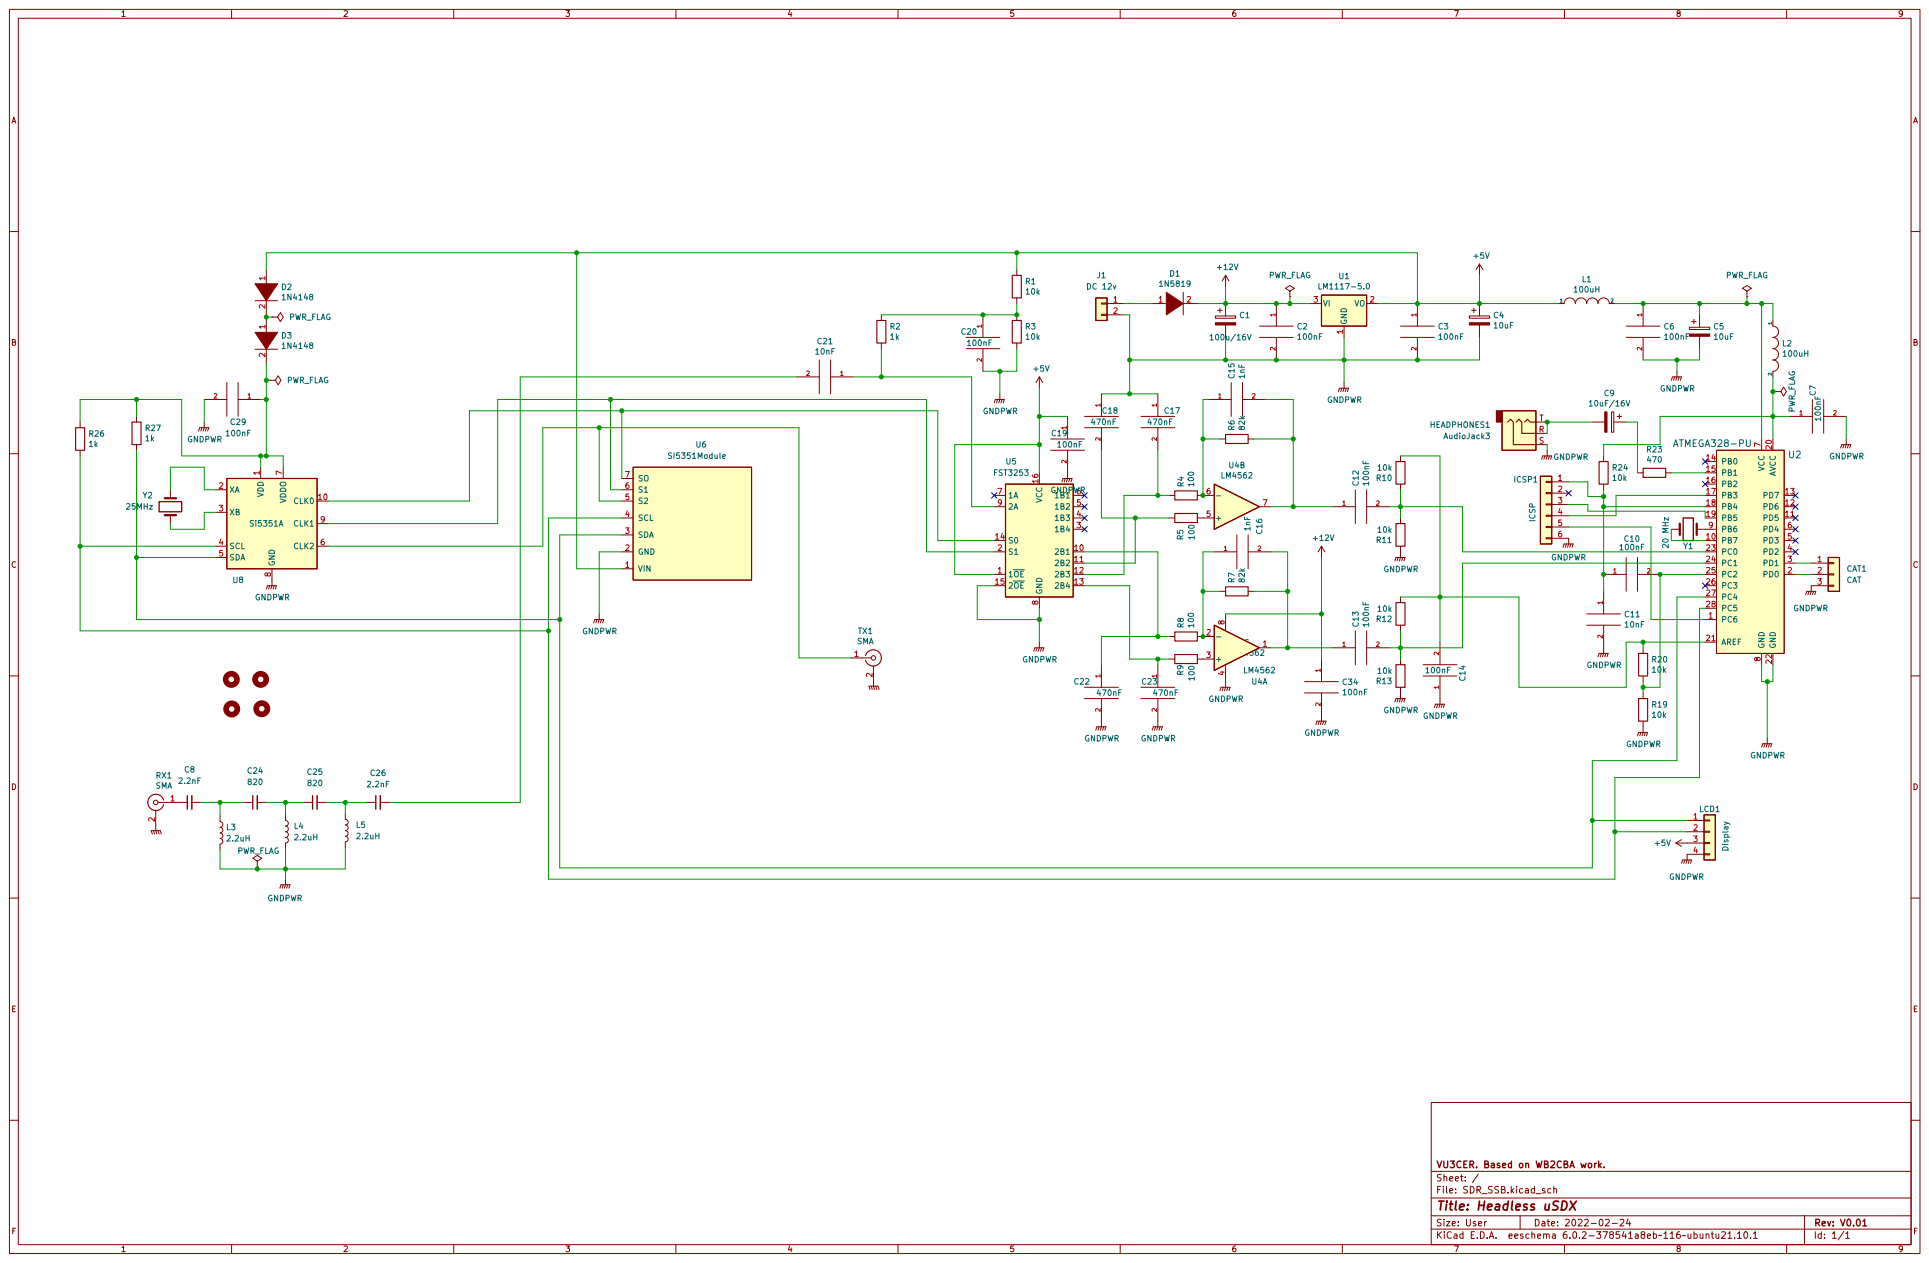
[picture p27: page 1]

1 CLK0 10 XA 2 XB 3 SCL 4 SDA 5 CLK2 6 VDDO

File: SDR_SSB.kicad_sch Sheet: / VU3CER. Based on WB2CBA work.

Id: 1/1 Title: Headless uSDX

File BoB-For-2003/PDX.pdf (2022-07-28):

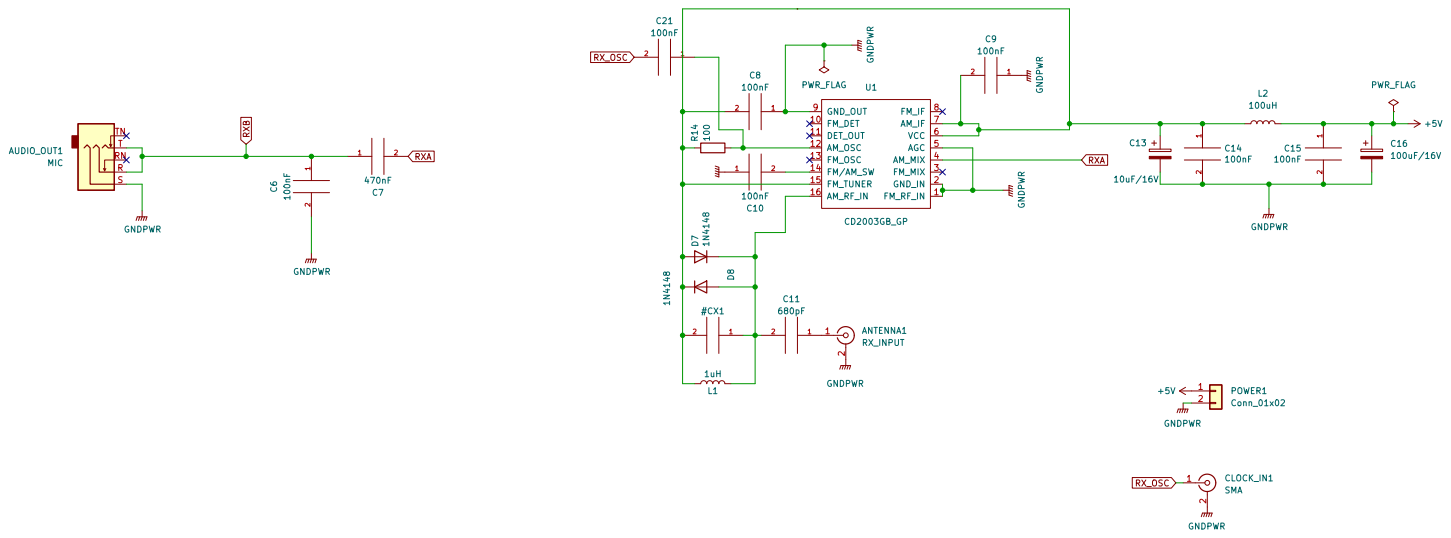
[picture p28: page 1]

Id: 1/1 Title: PDX RX Block - Pi Pico based DIGITAL MODES HF Transceiver

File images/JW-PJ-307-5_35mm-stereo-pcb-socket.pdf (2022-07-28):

# 3.5mm Stereo PCB Socket

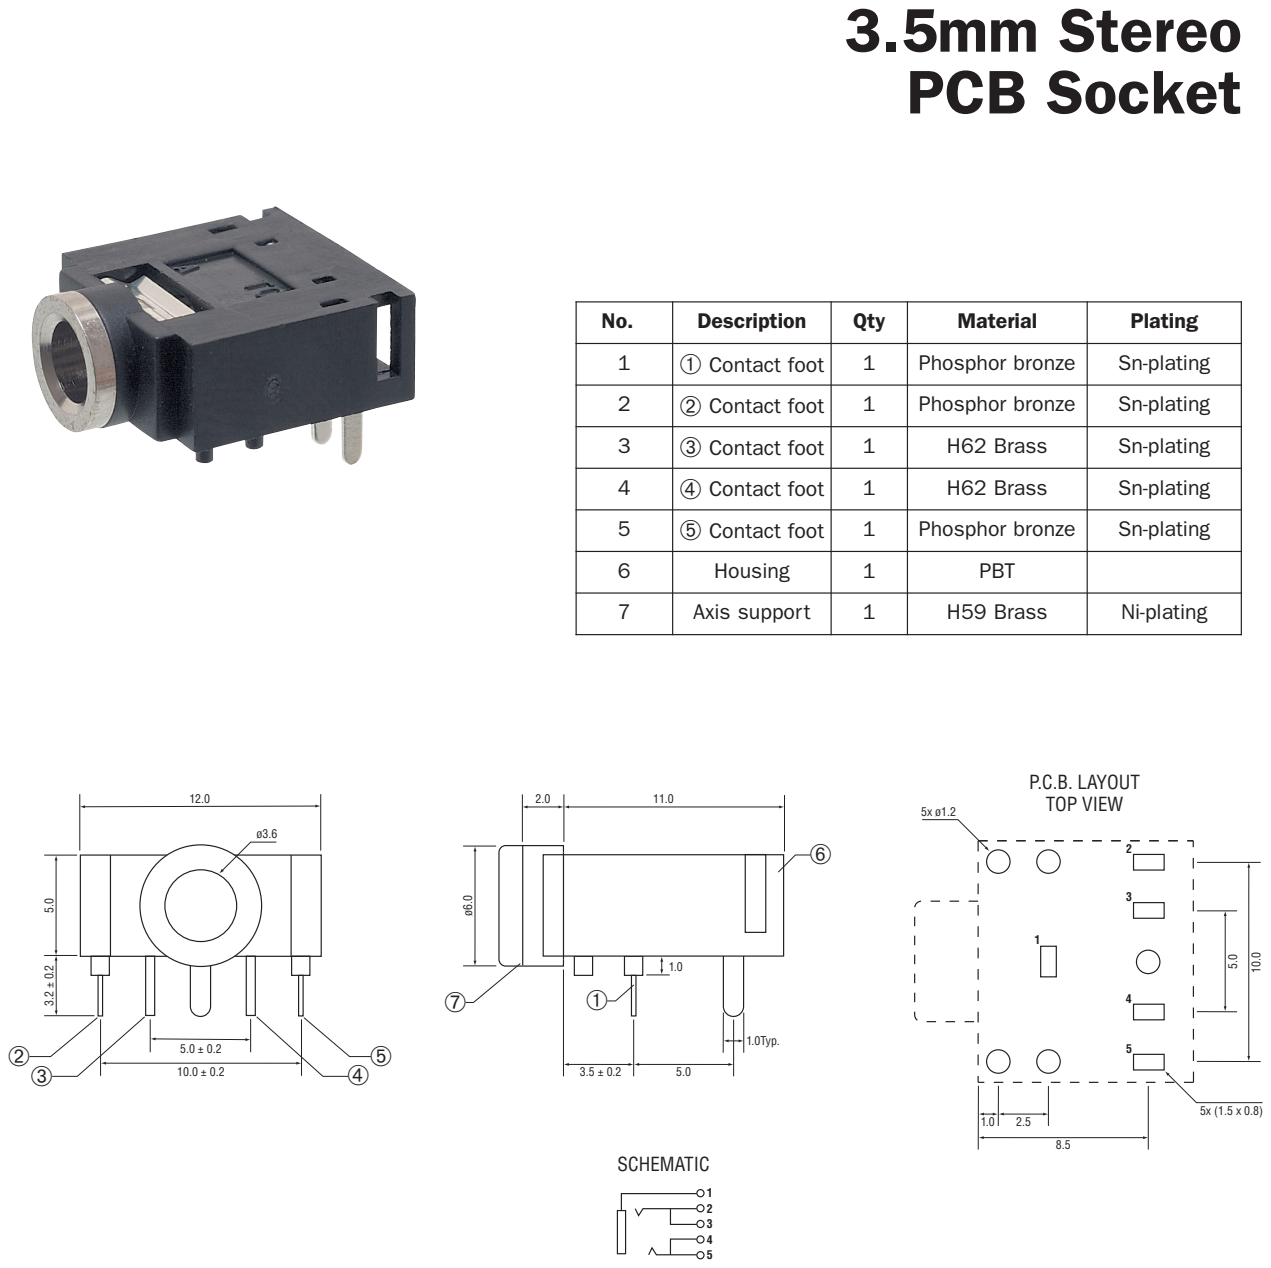
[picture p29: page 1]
1.0Typ.; SCHEMATIC; P.C.B. LAYOUT TOP VIEW

No. | Description | Qty | Material | Plating

1 | ➀ Contact foot | 1 | Phosphor bronze | Sn-plating

2 | ➁ Contact foot | 1 | Phosphor bronze | Sn-plating

3 | ➂ Contact foot | 1 | H62 Brass | Sn-plating

4 | ➃ Contact foot | 1 | H62 Brass | Sn-plating

5 | ➄ Contact foot | 1 | Phosphor bronze | Sn-plating

6 | Housing | 1 | PBT

7 | Axis support | 1 | H59 Brass | Ni-plating

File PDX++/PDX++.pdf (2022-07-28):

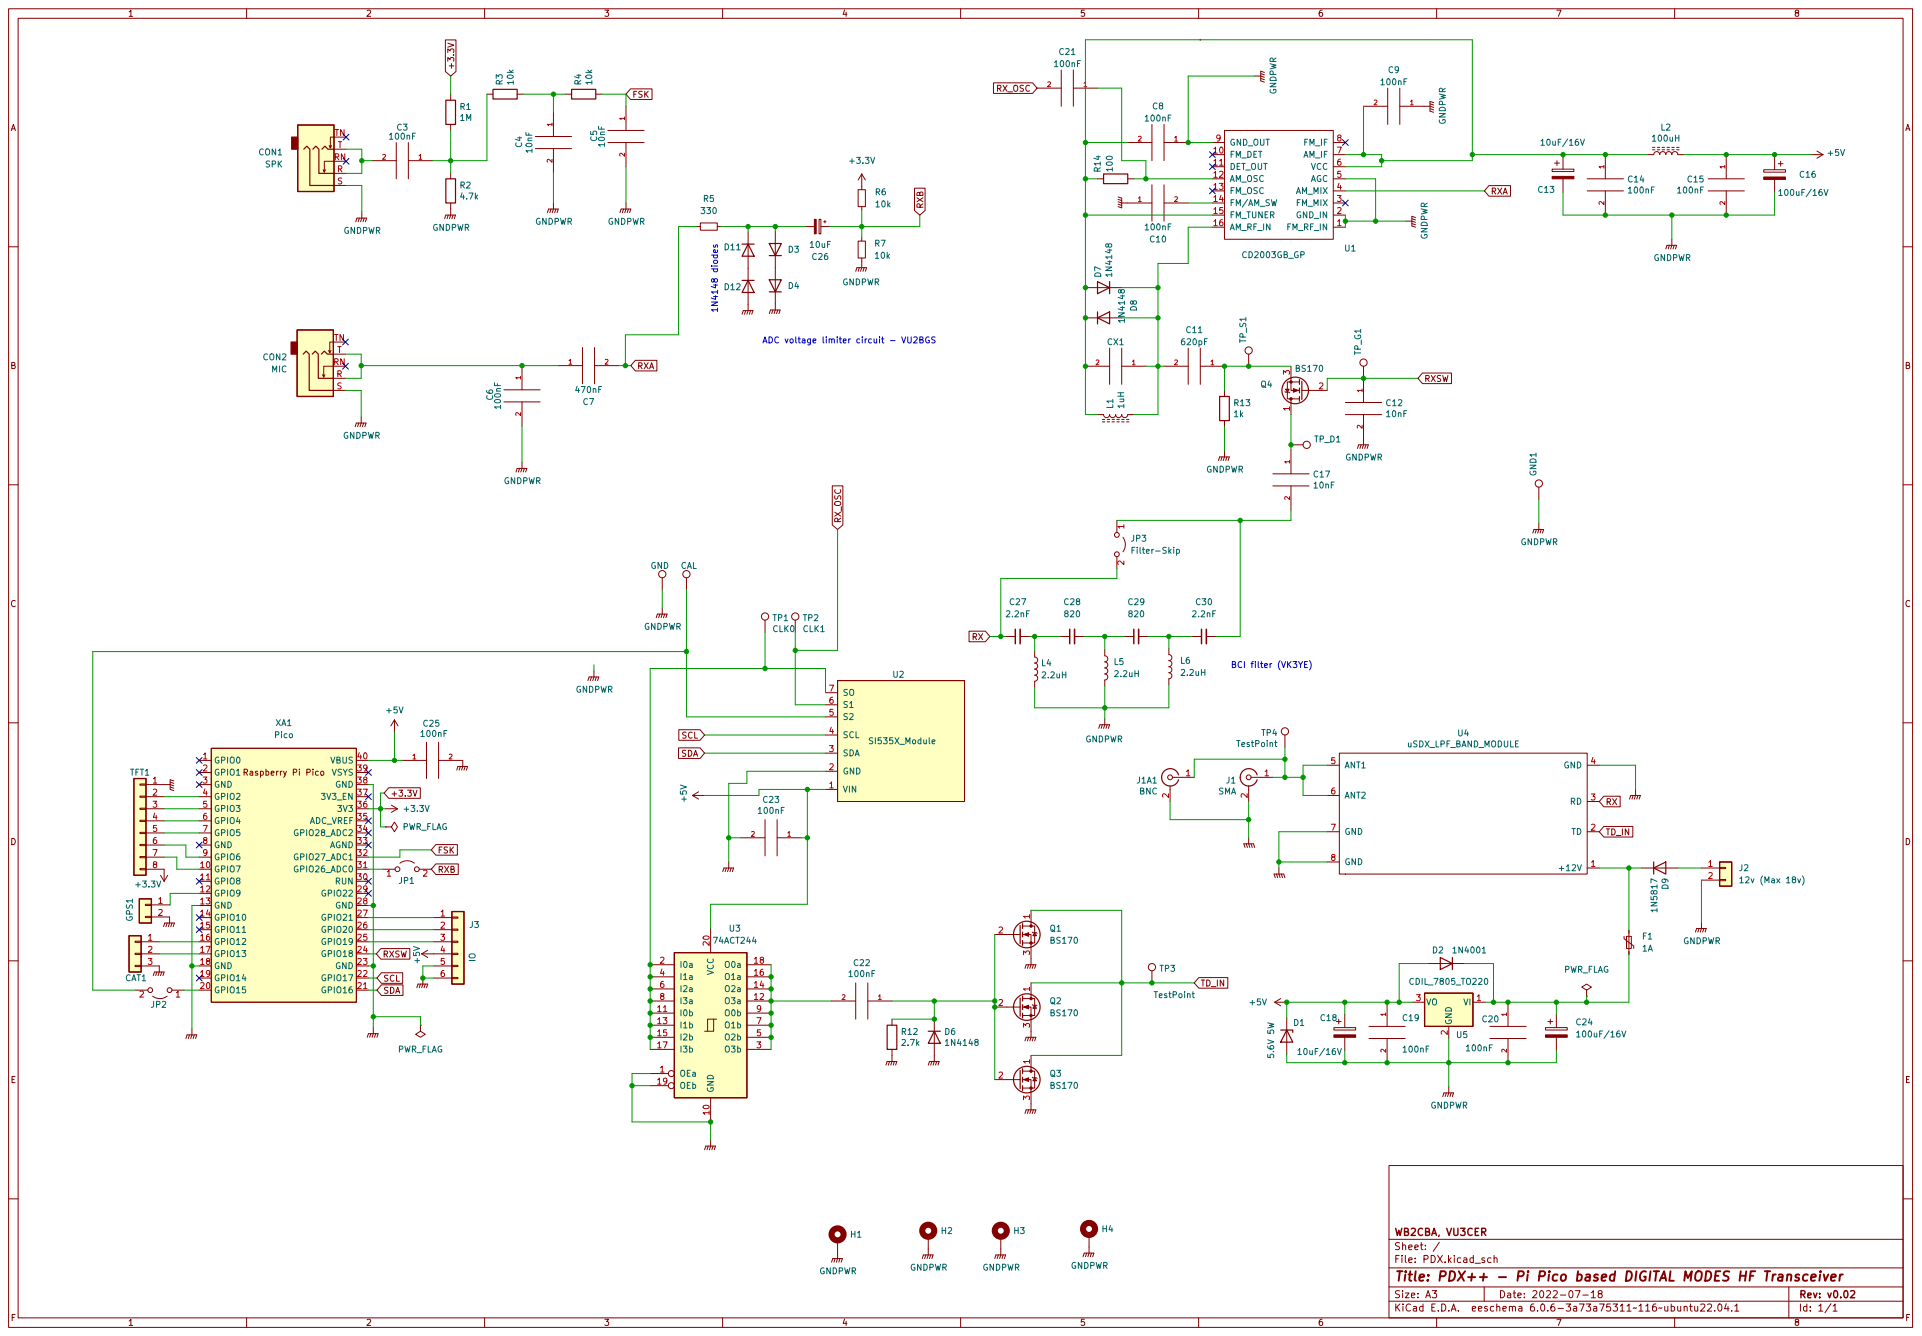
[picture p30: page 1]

ADC voltage limiter circuit - VU2BGS 1N4148 diodes

Id: 1/1 Title: PDX++ - Pi Pico based DIGITAL MODES HF Transceiver

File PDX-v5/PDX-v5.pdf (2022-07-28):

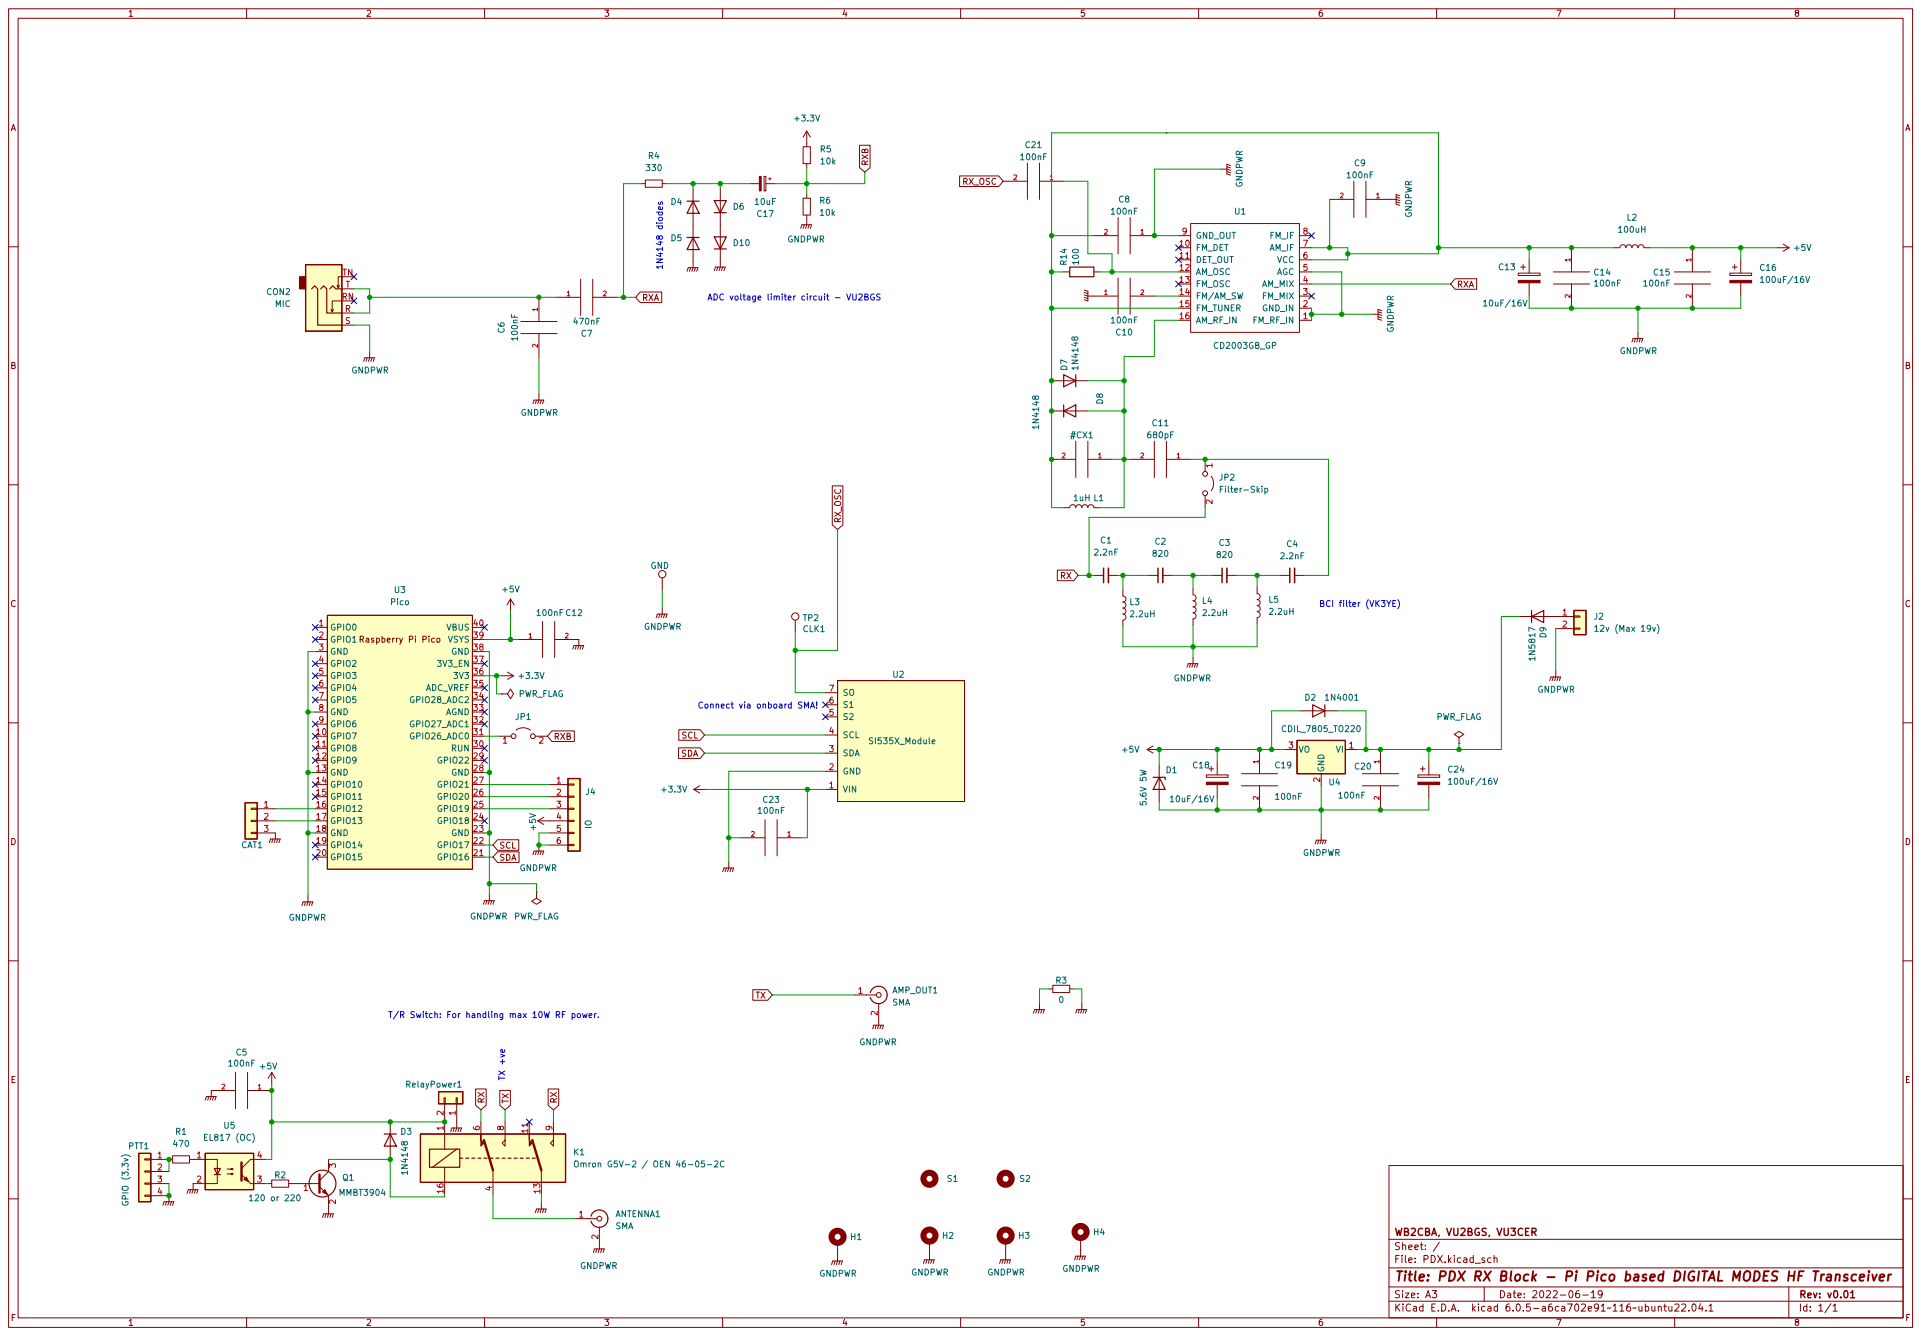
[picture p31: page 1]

ADC voltage limiter circuit - VU2BGS Connect via onboard SMA! 1N4148 diodes

2 VO 3 U4 CDIL_7805_TO220 GNDPWR GNDPWR RX RXB

T/R Switch: For handling max 10W RF power.

Id: 1/1 Title: PDX RX Block - Pi Pico based DIGITAL MODES HF Transceiver

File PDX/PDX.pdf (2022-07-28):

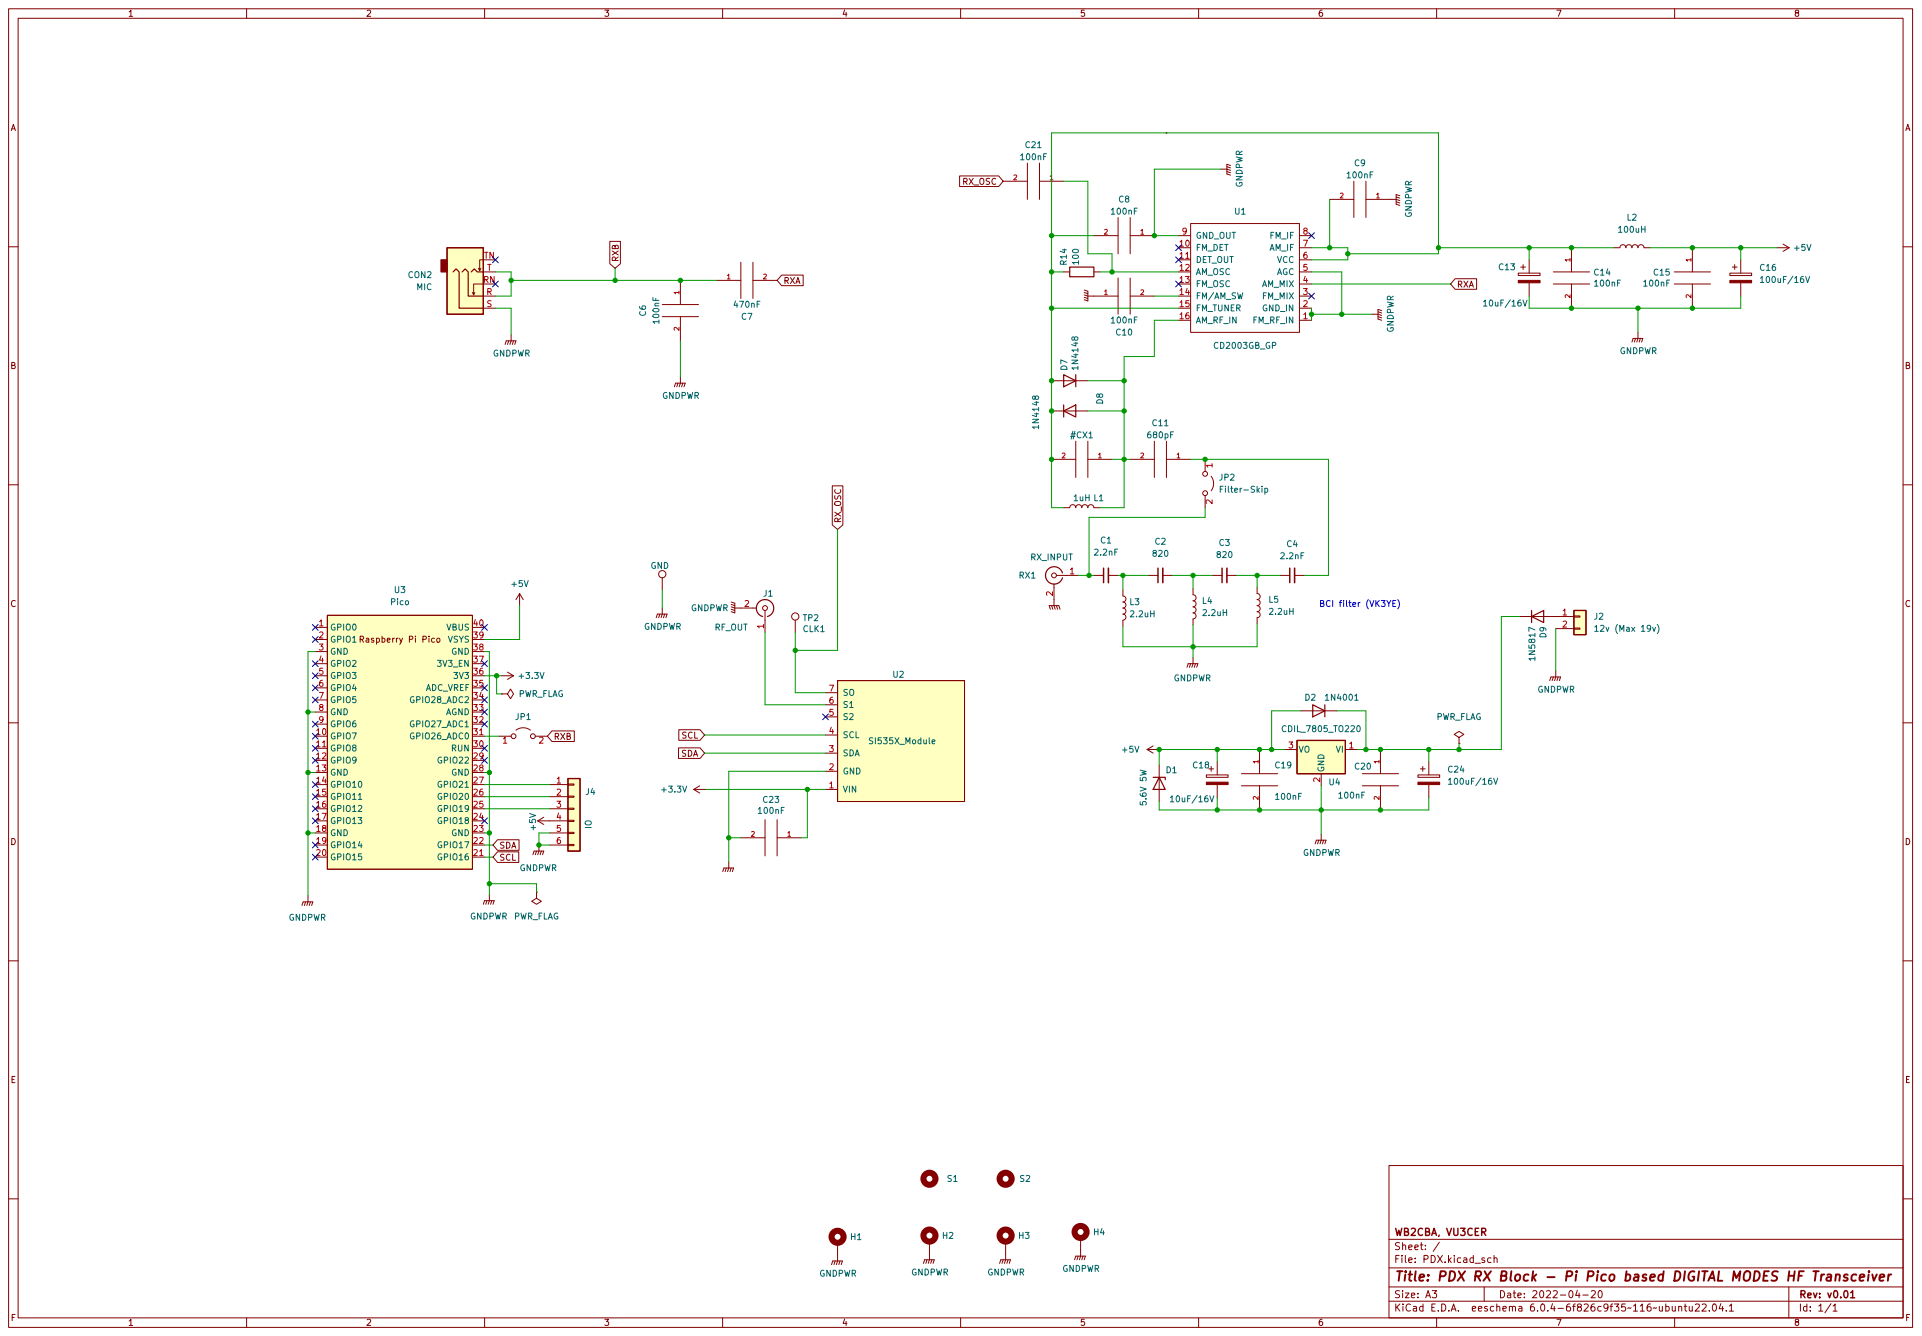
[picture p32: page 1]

Id: 1/1 Title: PDX RX Block - Pi Pico based DIGITAL MODES HF Transceiver

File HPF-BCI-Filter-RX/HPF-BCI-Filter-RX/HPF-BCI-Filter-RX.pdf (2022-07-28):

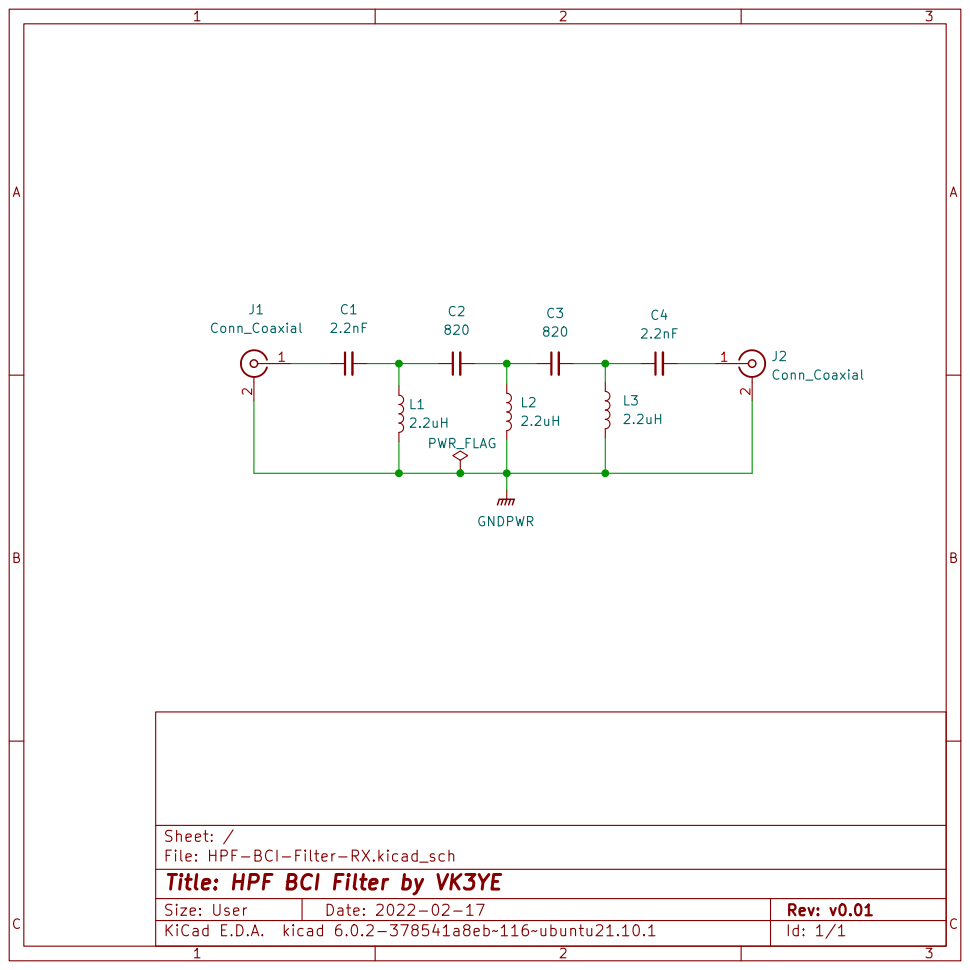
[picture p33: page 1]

Id: 1/1 Title: HPF BCI Filter by VK3YE

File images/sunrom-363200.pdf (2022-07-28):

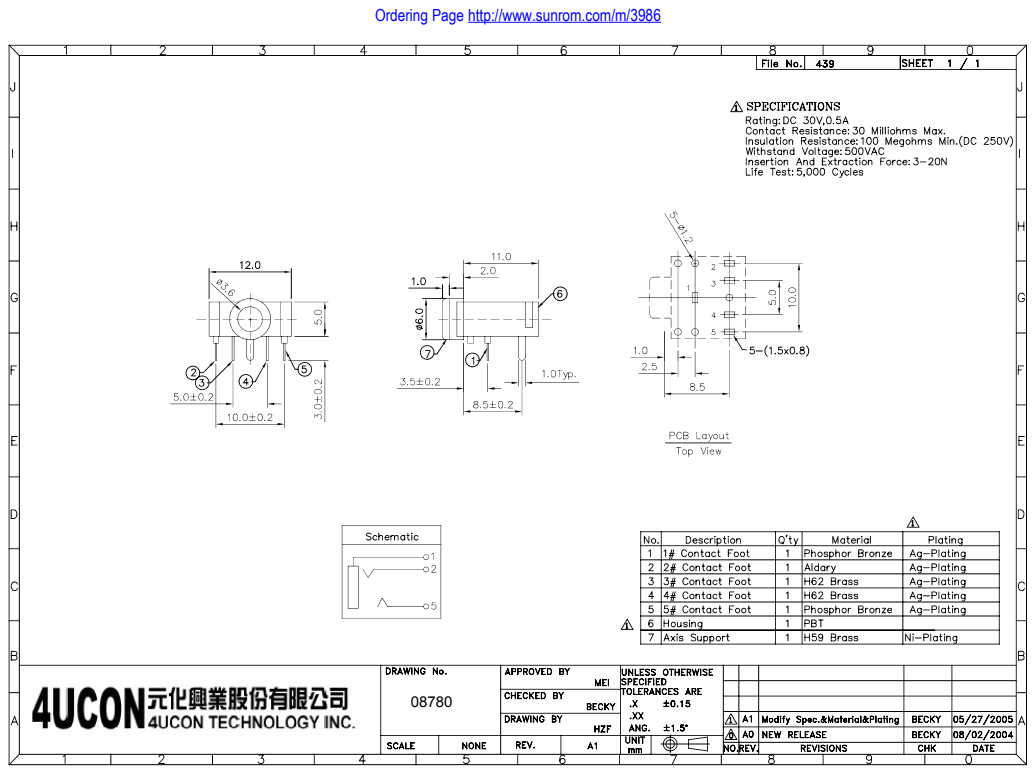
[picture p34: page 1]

Ordering Page http://www.sunrom.com/m/3986

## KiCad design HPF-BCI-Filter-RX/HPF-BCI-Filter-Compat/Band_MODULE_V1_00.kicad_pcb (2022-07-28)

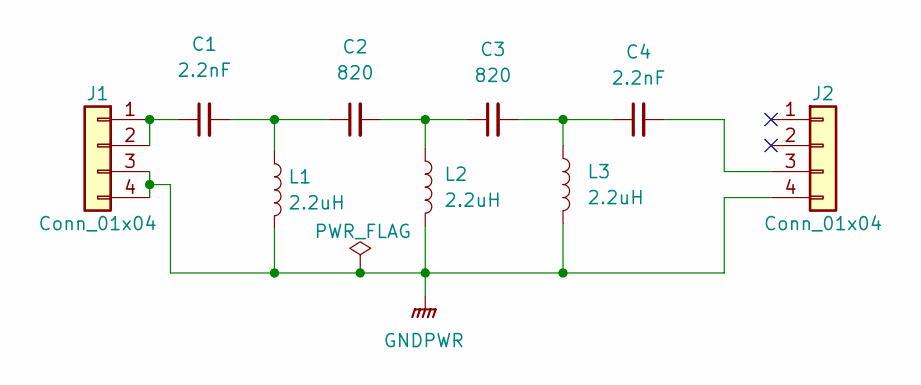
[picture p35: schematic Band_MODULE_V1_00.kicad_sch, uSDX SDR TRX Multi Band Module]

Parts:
C1, C4: 2.2nF; C_Disc_D3.0mm_W1.6mm_P2.50mm
C2, C3: 820; C_Disc_D3.0mm_W1.6mm_P2.50mm
J1, J2: Conn_01x04; PinHeader_1x4_P2.54mm_Drill1.02mm; MPN 0022232041; Digi-Key_PN WM4202-ND
L1, L2, L3: 2.2uH; R_Axial_DIN0204_L3.6mm_D1.6mm_P1.90mm_Vertical

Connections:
GNDPWR: J1.3, J1.4, J2.4, L1.2, L2.2, L3.2
unnamed: C1.1, J1.1, J1.2
unnamed: C1.2, C2.1, L1.1
unnamed: C2.2, C3.1, L2.1
unnamed: C3.2, C4.1, L3.1
unnamed: C4.2, J2.3

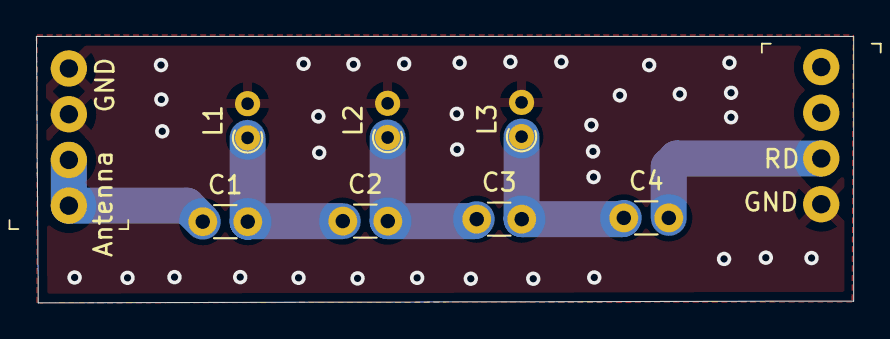
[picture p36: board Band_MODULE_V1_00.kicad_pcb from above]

Board: 2 copper layers, 45.4 x 14.8 mm, 9 parts (0 on the bottom side), 6 nets.

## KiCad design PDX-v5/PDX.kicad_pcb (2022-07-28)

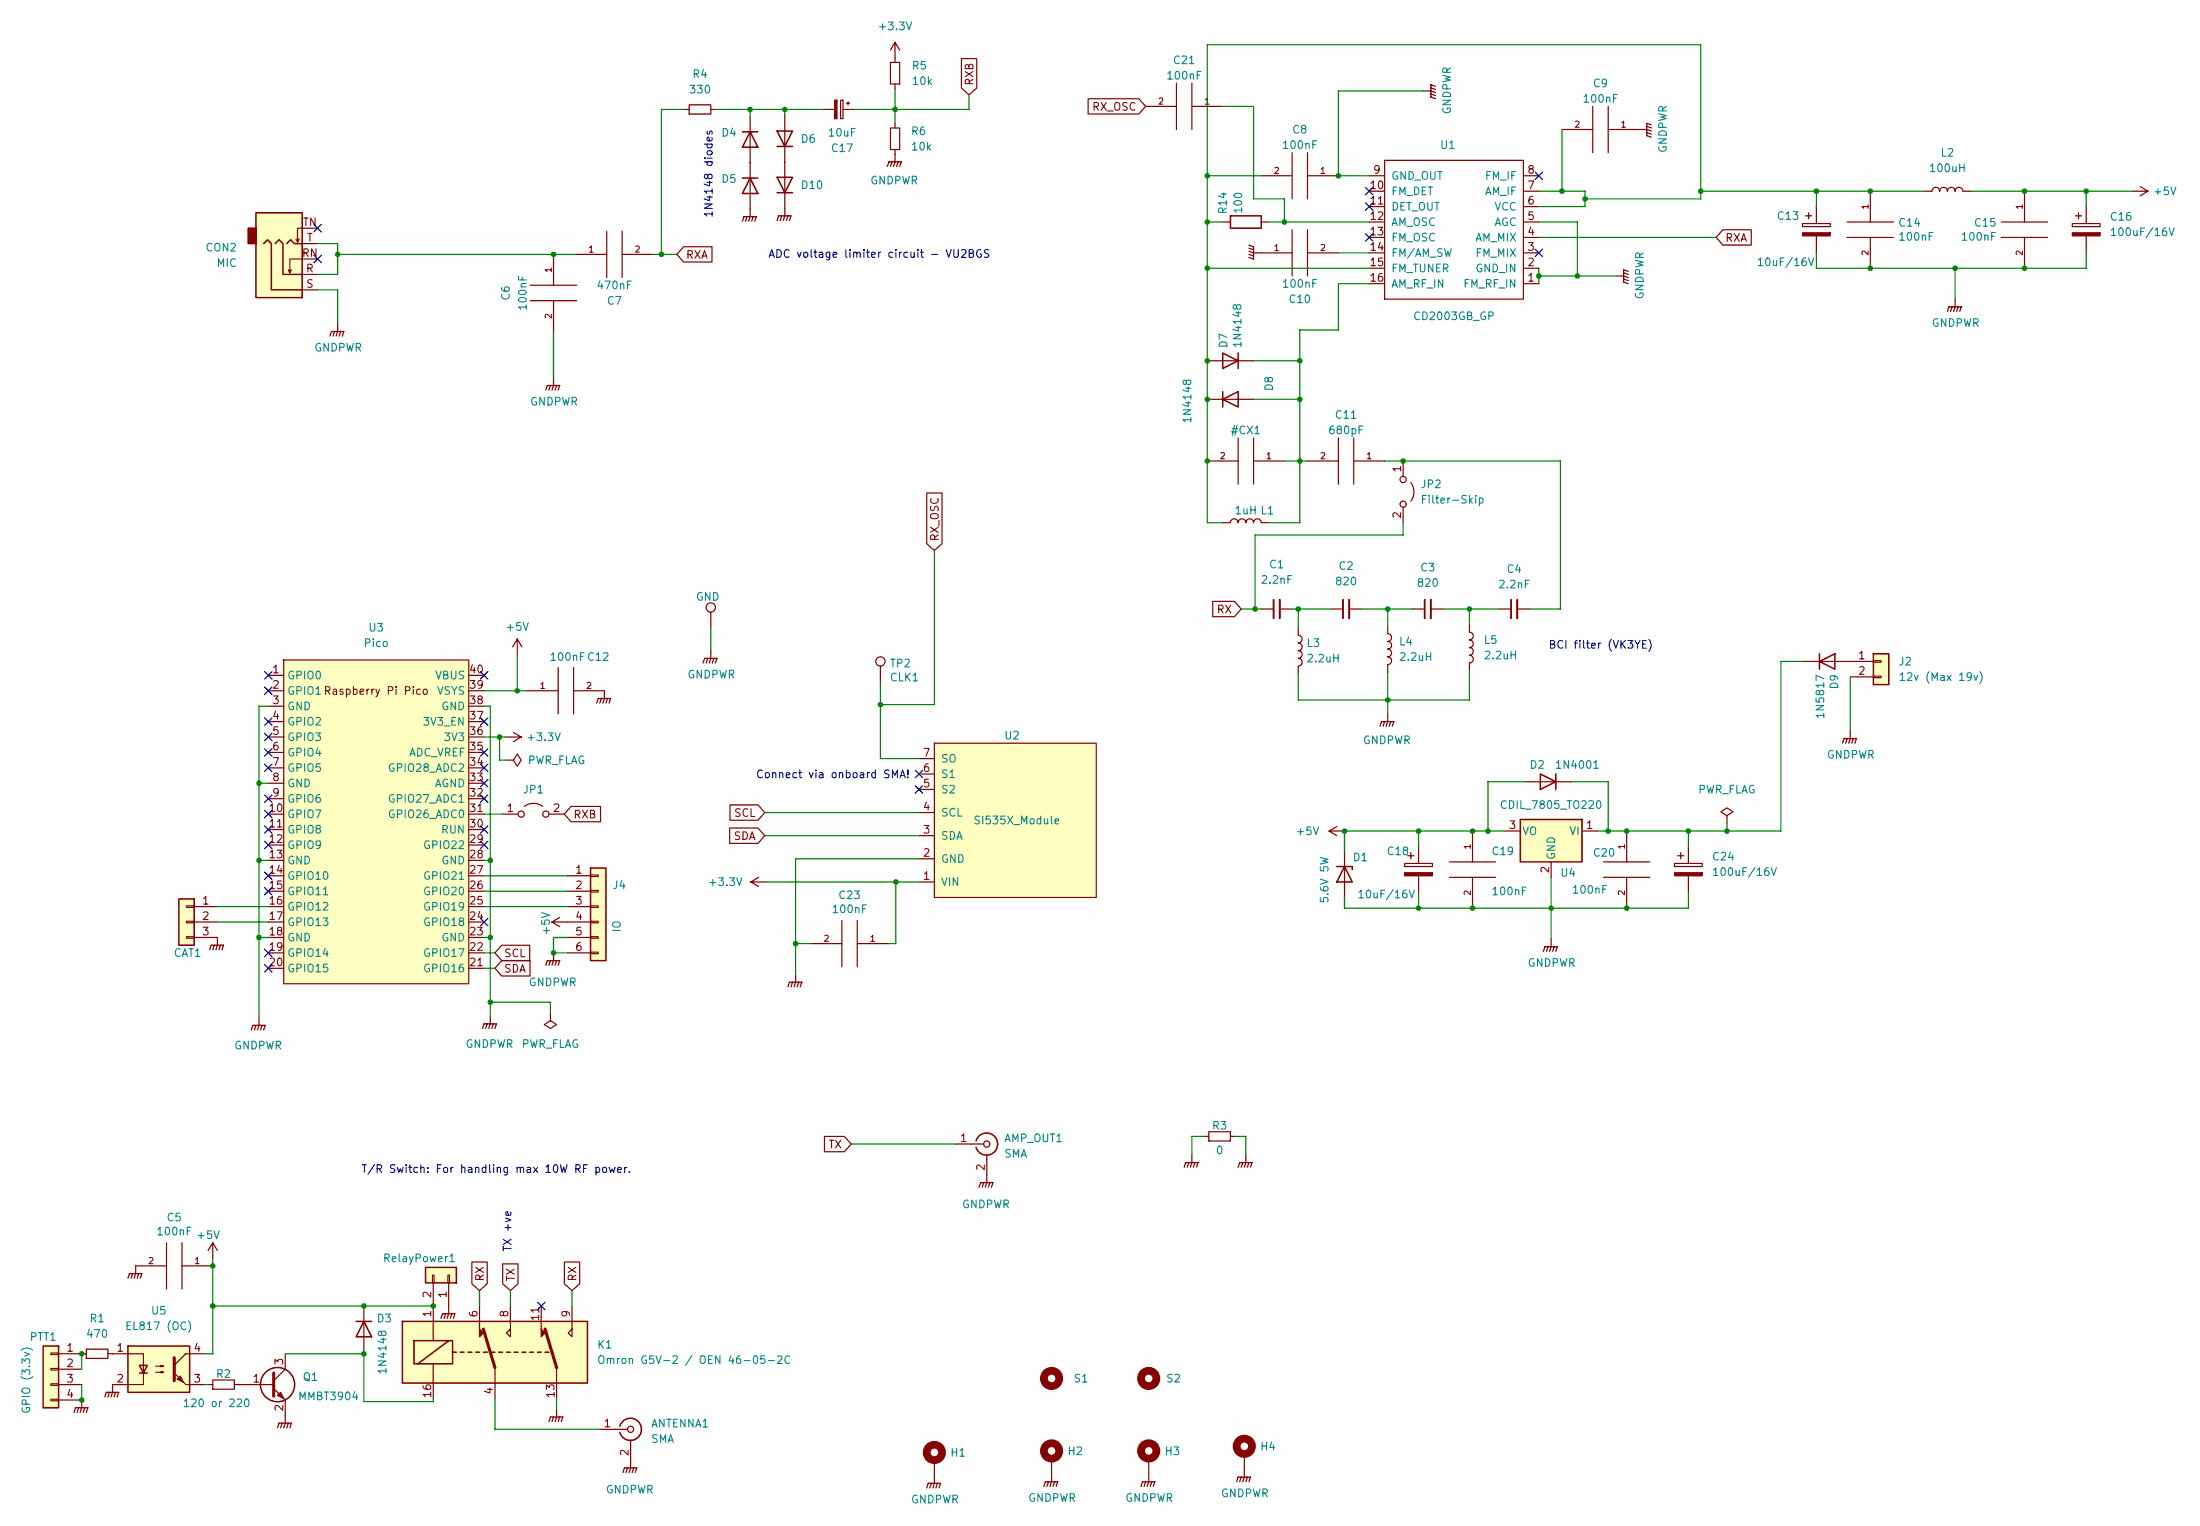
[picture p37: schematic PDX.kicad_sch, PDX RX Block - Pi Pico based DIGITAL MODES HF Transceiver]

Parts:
AMP_OUT1: SMA; SMA_Amphenol_901-144_Vertical
ANTENNA1: SMA; SMA_Amphenol_901-144_Vertical
C1, C4: 2.2nF; C_1206_3216Metric_Pad1.33x1.80mm_HandSolder
C2, C3: 820; C_1206_3216Metric_Pad1.33x1.80mm_HandSolder
C5, C6, C8, C9, C10, C12, C14, C15, C19, C20, C21, C23: 100nF; C_1206_3216Metric_Pad1.33x1.80mm_HandSolder
C7: 470nF; C_1206_3216Metric_Pad1.33x1.80mm_HandSolder
C11: 680pF; C_1206_3216Metric_Pad1.33x1.80mm_HandSolder
C13, C18: 10uF/16V; CP_Radial_D4.0mm_P2.00mm
C16, C24: 100uF/16V; CP_Radial_D4.0mm_P2.00mm
C17: 10uF; CP_Radial_D4.0mm_P2.00mm
CAT1: CAT; PinHeader_1x03_P2.54mm_Vertical
CON2: MIC; PJ-307
D1: 5.6V 5W; D_DO-15_P5.08mm_Vertical_KathodeUp
D2: 1N4001; D_SMA_Handsoldering
D3, D4, D5, D6, D7, D8, D10: 1N4148; D_DO-35_SOD27_P2.54mm_Vertical_KathodeUp
D9: 1N5817; D_A-405_P2.54mm_Vertical_KathodeUp
H1, H2, H3, H4: MountingHole_Pad; MountingHole_3.2mm_M3_ISO7380_Pad
J2: 12v (Max 19v); PinHeader_1x02_P2.54mm_Vertical
J4: IO; PinHeader_1x06_P2.54mm_Vertical
JP1: Jumper_2_Open; PinHeader_1x02_P2.54mm_Vertical
JP2: Filter-Skip; PinHeader_1x02_P2.54mm_Vertical
K1: Omron G5V-2 / OEN 46-05-2C; Relay_DPDT_Omron_G5V-2
L1: 1uH; L_Axial_L5.3mm_D2.2mm_P2.54mm_Vertical_Vishay_IM-1
L2: 100uH; L_Axial_L5.3mm_D2.2mm_P2.54mm_Vertical_Vishay_IM-1
L3, L4, L5: 2.2uH; L_Axial_L5.3mm_D2.2mm_P2.54mm_Vertical_Vishay_IM-1
PTT1: GPIO (3.3v); PinHeader_1x04_P2.54mm_Vertical
Q1: MMBT3904; SOT-23
R1: 470; R_1206_3216Metric_Pad1.30x1.75mm_HandSolder
R2: 120 or 220; R_1206_3216Metric_Pad1.30x1.75mm_HandSolder
R3: 0; R_1206_3216Metric_Pad1.30x1.75mm_HandSolder
R4: 330; R_1206_3216Metric_Pad1.30x1.75mm_HandSolder
R5, R6: 10k; R_Axial_DIN0207_L6.3mm_D2.5mm_P2.54mm_Vertical
R14: 100; R_1206_3216Metric_Pad1.30x1.75mm_HandSolder
RELAY_POWER1: RelayPower1; PinHeader_1x02_P2.54mm_Vertical
S1, S2: MountingHole; MountingHole_2.7mm_M2.5
TP2: CLK1; PinHeader_1x01_P2.54mm_Vertical
TP7: GND; PinHeader_1x01_P2.54mm_Vertical
U1: CD2003GB_GP; DIP-16_W7.62mm_Socket
U2: SI535X_Module; PinSocket_1x07_P2.54mm_Vertical
U3: Pico; RPi_Pico_SMD_TH
U4: CDIL_7805_TO220; TO-220-3_Vertical
U5: EL817 (OC); DIP-4_W7.62mm

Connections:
+3V3: C23.1, R5.2, U2.1 (VIN), U3.36 (3V3)
+5V: C5.1, C12.1, C15.1, C16.1, C18.1, C19.1, D1.1 (K), D2.2 (A), D3.1 (K), J4.4, K1.1, L2.2, RELAY_POWER1.2, U3.39 (VSYS), U4.3 (VO), U5.4
GNDPWR: AMP_OUT1.2 (Ext), ANTENNA1.2 (Ext), C5.2, C6.2, C8.1, C9.1, C10.1, C12.2, C13.2, C14.2, C15.2, C16.2, C18.2, C19.2, C20.2, C23.2, C24.2, CAT1.3, CON2.S, D1.2 (A), D5.2 (A), D10.1 (K), H1.1, H2.1, H3.1, H4.1, J2.2, J4.5, J4.6, K1.13, L3.2, L4.2, L5.2, PTT1.3, PTT1.4, Q1.2 (E), R3.1, R3.2, R6.1, RELAY_POWER1.1, TP7.1, U1.1 (FM_RF_IN), U1.2 (GND_IN), U1.5 (AGC), U1.9 (GND_OUT), U2.2 (GND), U3.3 (GND), U3.8 (GND), U3.13 (GND), U3.18 (GND), U3.23 (GND), U3.28 (GND), U3.38 (GND), U4.2 (GND), U5.2
unnamed: ANTENNA1.1 (In), K1.4
unnamed: C1.2, C2.1, L3.1
unnamed: C2.2, C3.1, L4.1
unnamed: C3.2, C4.1, L5.1
unnamed: C6.1, C7.1, CON2.R, CON2.T
unnamed: C10.2, U1.14 (FM/AM_SW)
unnamed: C4.2, C11.1, JP2.1 (A)
unnamed: C17.2, D4.1 (K), D6.2 (A), R4.2
unnamed: C20.1, C24.1, D2.1 (K), D9.1 (K), U4.1 (VI)
unnamed: C21.1, R14.1, U1.12 (AM_OSC)
unnamed: CAT1.1, U3.16 (GPIO12)
unnamed: CAT1.2, U3.17 (GPIO13)
unnamed: D3.2 (A), K1.16, Q1.3 (C)
unnamed: D4.2 (A), D5.1 (K)
unnamed: D9.2 (A), J2.1
unnamed: D6.1 (K), D10.2 (A)
unnamed: J4.1, U3.27 (GPIO21)
unnamed: J4.2, U3.26 (GPIO20)
unnamed: J4.3, U3.25 (GPIO19)
unnamed: JP1.1 (A), U3.31 (GPIO26_ADC0)
unnamed: PTT1.1, PTT1.2, R1.1
unnamed: Q1.1 (B), R2.2
unnamed: R1.2, U5.1
unnamed: R2.1, U5.3
RX: C1.1, JP2.2 (B), K1.6, K1.9
RXA: C7.2, R4.1, U1.4 (AM_MIX)
RXB: C17.1, JP1.2 (B), R5.1, R6.2
RX_OSC: C21.2, TP2.1, U2.7 (SO)
SCL: U2.4 (SCL), U3.22 (GPIO17)
SDA: U2.3 (SDA), U3.21 (GPIO16)
TX: AMP_OUT1.1 (In), K1.8

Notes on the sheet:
Connect via onboard SMA!
BCI filter (VK3YE)
1N4148 diodes
T/R Switch: For handling max 10W RF power.
ADC voltage limiter circuit - VU2BGS
TX +ve

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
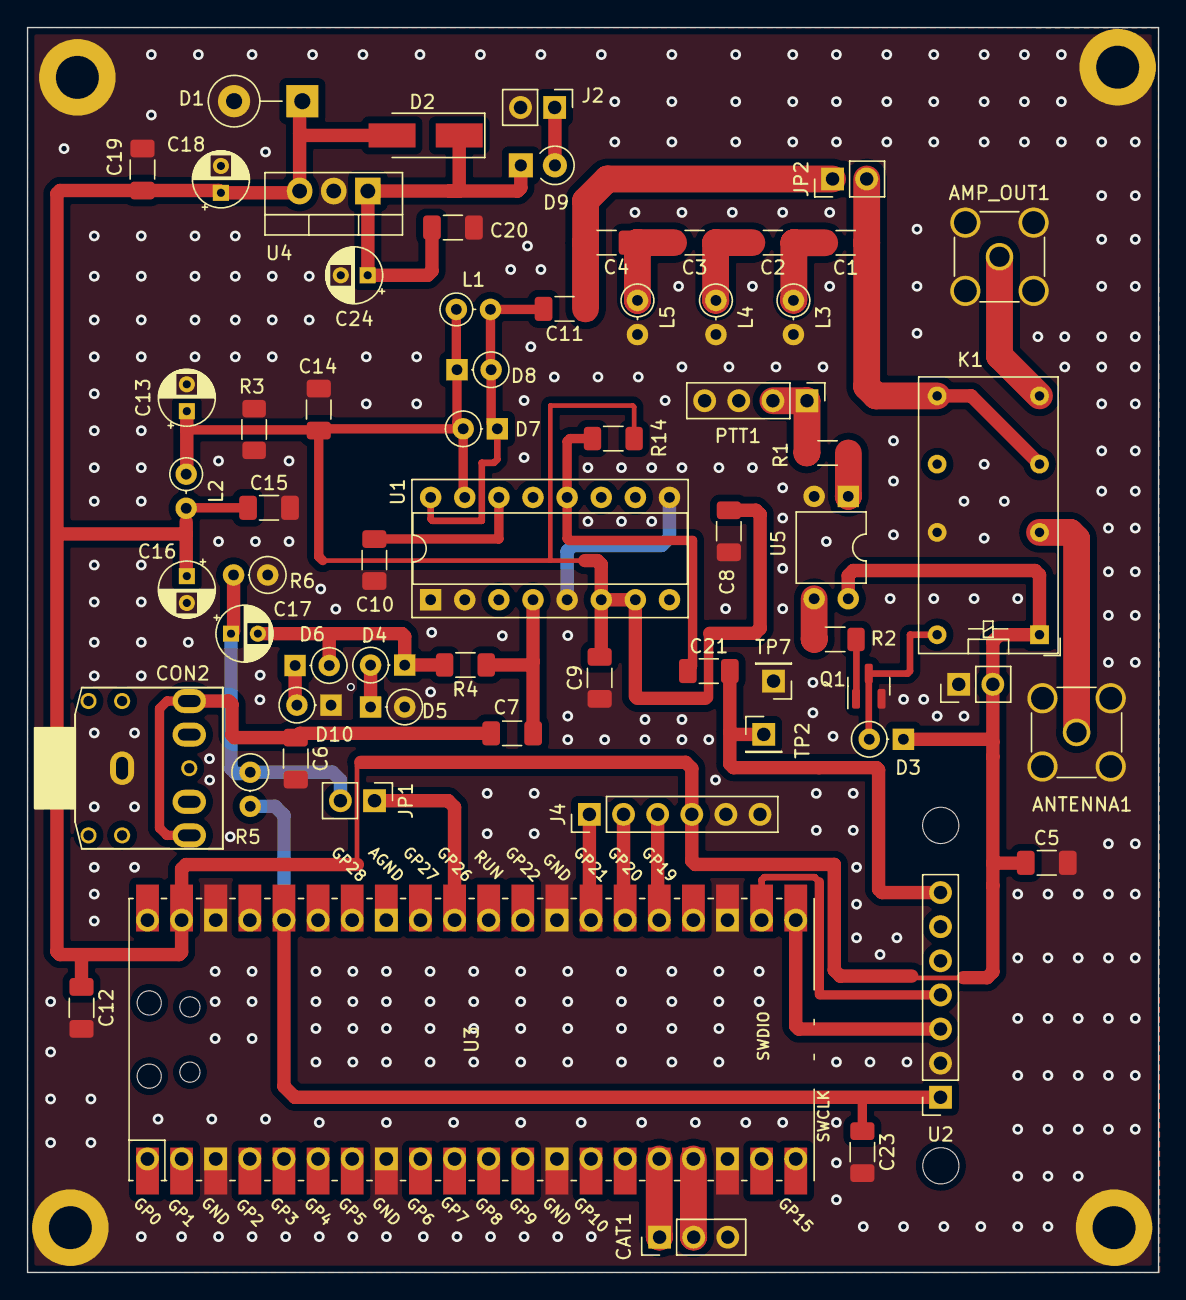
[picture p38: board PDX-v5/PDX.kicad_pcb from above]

Board: 2 copper layers, 84.2 x 92.7 mm, 70 parts (0 on the bottom side), 36 nets.

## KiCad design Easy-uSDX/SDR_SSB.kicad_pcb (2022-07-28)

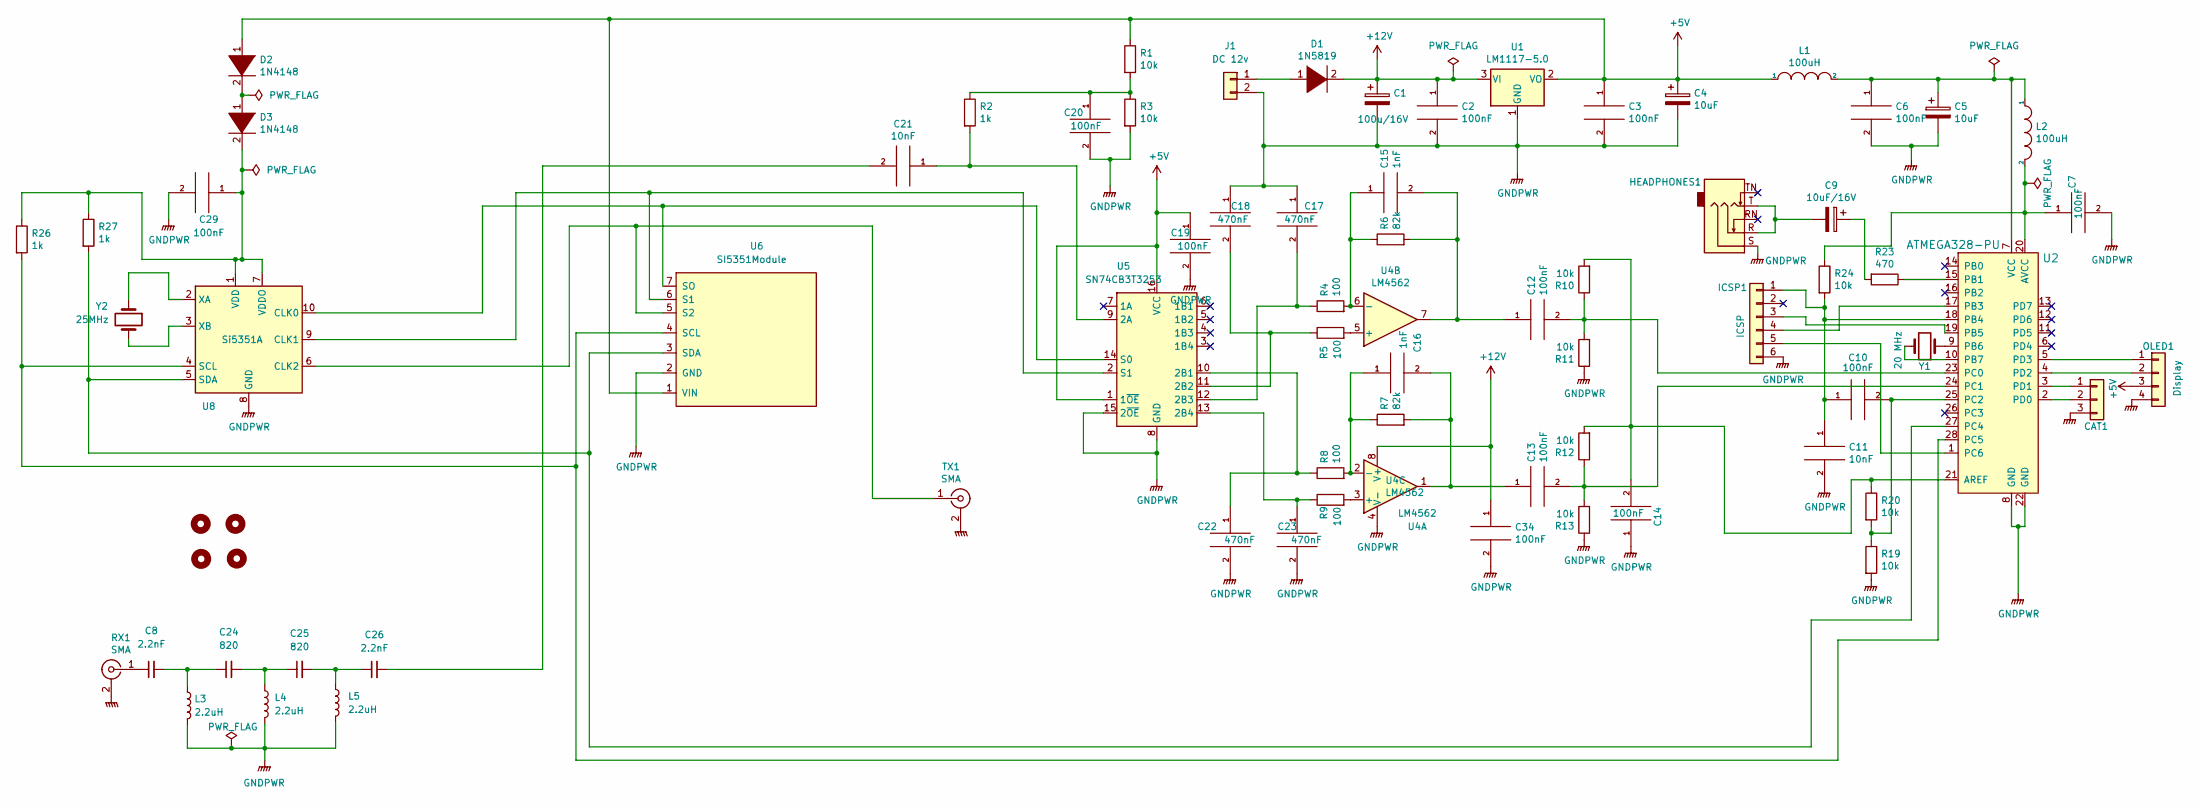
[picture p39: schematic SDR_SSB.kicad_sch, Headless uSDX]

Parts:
C1: 100u/16V; CP_Radial_D5.0mm_P2.50mm
C2, C3, C6, C7, C10, C12, C13, C14, C19, C20, C29, C34: 100nF; C_Disc_D3.0mm_W2.0mm_P2.50mm
C4, C5: 10uF; CP_Radial_D4.0mm_P2.00mm
C8, C26: 2.2nF; C_Disc_D3.0mm_W1.6mm_P2.50mm
C9: 10uF/16V; CP_Radial_D4.0mm_P2.00mm
C11, C21: 10nF; C_Disc_D3.0mm_W2.0mm_P2.50mm
C15, C16: 1nF; C_Disc_D3.0mm_W2.0mm_P2.50mm
C17, C18, C22, C23: 470nF; C_Disc_D3.0mm_W2.0mm_P2.50mm
C24, C25: 820; C_Disc_D3.0mm_W1.6mm_P2.50mm
CAT1: CAT; PinHeader_1x03_P2.54mm_Vertical
D1: 1N5819; D_A-405_P2.54mm_Vertical_AnodeUp
D2, D3: 1N4148; D_DO-35_SOD27_P2.54mm_Vertical_KathodeUp
H1, H2, H3, H4: MountingHole; MountingHole_2.2mm_M2
HEADPHONES1: AudioJack3_SwitchTR; PJ-307
ICSP1: ICSP; PinHeader_2x03_P2.54mm_Vertical
J1: DC 12v; PinHeader_1x02_P2.54mm_Vertical
L1, L2: 100uH; L_Axial_L5.3mm_D2.2mm_P2.54mm_Vertical_Vishay_IM-1
L3, L4, L5: 2.2uH; R_Axial_DIN0204_L3.6mm_D1.6mm_P1.90mm_Vertical
OLED1: Display; PinHeader_1x04_P2.54mm_Vertical
R1, R3, R10, R11, R12, R13, R19, R20, R24: 10k; R_Axial_DIN0204_L3.6mm_D1.6mm_P1.90mm_Vertical
R2, R26, R27: 1k; R_Axial_DIN0204_L3.6mm_D1.6mm_P1.90mm_Vertical
R4, R5, R8, R9: 100; R_Axial_DIN0204_L3.6mm_D1.6mm_P1.90mm_Vertical
R6, R7: 82k; R_Axial_DIN0204_L3.6mm_D1.6mm_P1.90mm_Vertical
R23: 470; R_Axial_DIN0204_L3.6mm_D1.6mm_P1.90mm_Vertical
RX1: SMA; SMA_Amphenol_901-144_Vertical
TX1: SMA; SMA_Amphenol_901-144_Vertical
U1: LM1117-5.0; SOT-223-3_TabPin2
U2: ATMEGA328-PU; DIP-28_W7.62mm_Socket_LongPads; MPN ATMEGA328-PU; Digi-Key_PN ATMEGA328-PU-ND
U4: LM4562; DIP-8_W7.62mm_LongPads
U5: SN74CB3T3253; SOIC-16_4.55x10.3mm_P1.27mm
U6: SI5351Module; SI5351 Module
U8: Si5351A; MSOP-10_3x3mm_P0.5mm
Y1: 20 MHz; Crystal_HC49-U_Vertical
Y2: 25MHz; Crystal_HC49-U_Vertical

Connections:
+5V: C3.1, C4.1, C19.1, D2.1 (K), L1.1, OLED1.3, R1.1, U1.2 (VO), U5.1 (1~OE), U5.16 (VCC), U6.1 (VIN)
+12V: C1.1, C2.1, C34.1, D1.2 (A), U1.3 (VI), U4.8 (V+)
GNDPWR: C1.2, C2.2, C3.2, C4.2, C5.2, C6.2, C7.2, C11.2, C14.1, C17.1, C18.1, C19.2, C20.2, C22.2, C23.2, C29.2, C34.2, CAT1.3, HEADPHONES1.S, ICSP1.6, J1.2, L3.2, L4.2, L5.2, OLED1.4, R3.2, R11.1, R13.1, R19.2, RX1.2 (Ext), TX1.2 (Ext), U1.1 (GND), U2.8 (GND), U2.22 (GND), U4.4 (V-), U5.8 (GND), U5.15 (2~OE), U6.2 (GND), U8.8 (GND)
unnamed: C5.1, C6.1, L1.2, L2.1, U2.7 (VCC)
unnamed: C7.1, L2.2, R24.1, U2.20 (AVCC)
unnamed: C8.1, RX1.1 (In)
unnamed: C9.1, R23.2
unnamed: C9.2, HEADPHONES1.R, HEADPHONES1.T
unnamed: C10.1, C11.1, ICSP1.1, R24.2, U2.18 (PB4)
unnamed: C10.2, R19.1, R20.2, U2.25 (PC2)
unnamed: C12.1, C15.2, R6.2, U4.7
unnamed: C12.2, R10.1, R11.2, U2.23 (PC0)
unnamed: C13.1, C16.2, R7.2, U4.1
unnamed: C13.2, R12.1, R13.2, U2.24 (PC1)
unnamed: C14.2, R10.2, R12.2, R20.1, U2.21 (AREF)
unnamed: C15.1, R4.2, R6.1, U4.6 (-)
unnamed: C16.1, R7.1, R8.2, U4.2 (-)
unnamed: C17.2, R4.1, U5.12 (2B3)
unnamed: C18.2, R5.1, U5.11 (2B2)
unnamed: C20.1, R1.2, R2.1, R3.1
unnamed: C21.1, R2.2, U5.9 (2A)
unnamed: C21.2, C26.2
unnamed: C22.1, R8.1, U5.10 (2B1)
unnamed: C23.1, R9.1, U5.13 (2B4)
unnamed: C8.2, C24.1, L3.1
unnamed: C24.2, C25.1, L4.1
unnamed: C25.2, C26.1, L5.1
unnamed: C29.1, D3.2 (A), R26.1, R27.1, U8.1 (VDD), U8.7 (VDDO)
unnamed: CAT1.1, U2.3 (PD1)
unnamed: CAT1.2, U2.2 (PD0)
unnamed: D1.1 (K), J1.1
unnamed: D2.2 (A), D3.1 (K)
unnamed: ICSP1.3, U2.19 (PB5)
unnamed: ICSP1.4, U2.17 (PB3)
unnamed: ICSP1.5, U2.1 (PC6)
unnamed: OLED1.1, U2.5 (PD3)
unnamed: OLED1.2, U2.4 (PD2)
unnamed: R5.2, U4.5 (+)
unnamed: R9.2, U4.3 (+)
unnamed: R23.1, U2.15 (PB1)
unnamed: R26.2, U2.28 (PC5), U6.4 (SCL), U8.4 (SCL)
unnamed: R27.2, U2.27 (PC4), U6.3 (SDA), U8.5 (SDA)
unnamed: TX1.1 (In), U6.5 (S2), U8.6 (CLK2)
unnamed: U2.9 (PB6), Y1.1
unnamed: U2.10 (PB7), Y1.2
unnamed: U5.2 (S1), U6.6 (S1), U8.9 (CLK1)
unnamed: U5.14 (S0), U6.7 (SO), U8.10 (CLK0)
unnamed: U8.2 (XA), Y2.1
unnamed: U8.3 (XB), Y2.2

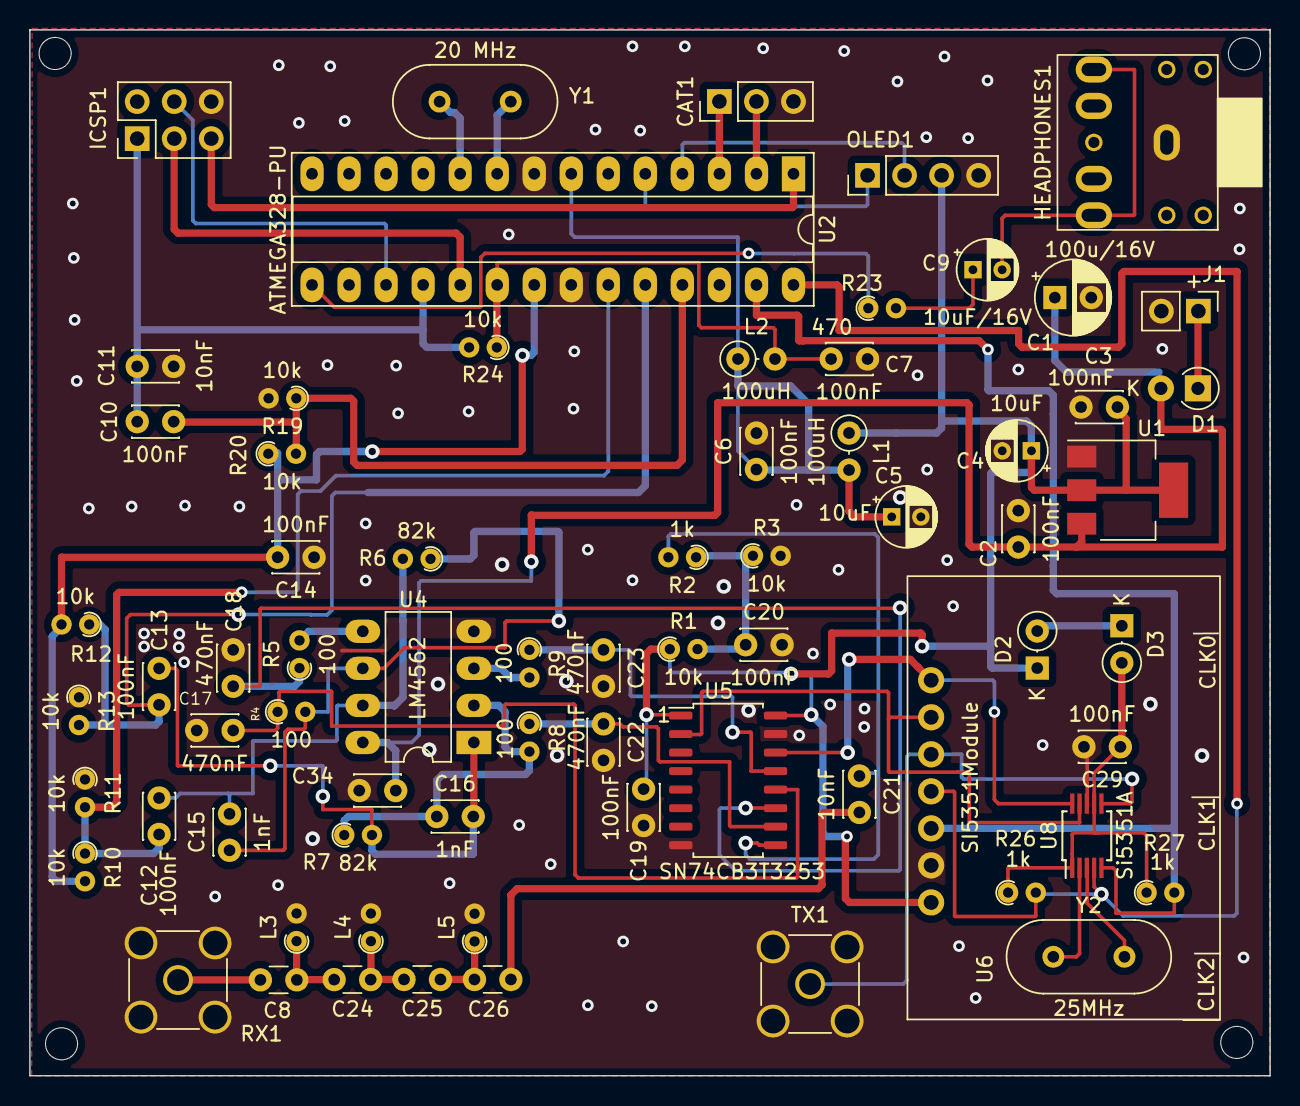
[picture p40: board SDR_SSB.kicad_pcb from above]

Board: 2 copper layers, 85.1 x 71.7 mm, 74 parts (0 on the bottom side), 49 nets.

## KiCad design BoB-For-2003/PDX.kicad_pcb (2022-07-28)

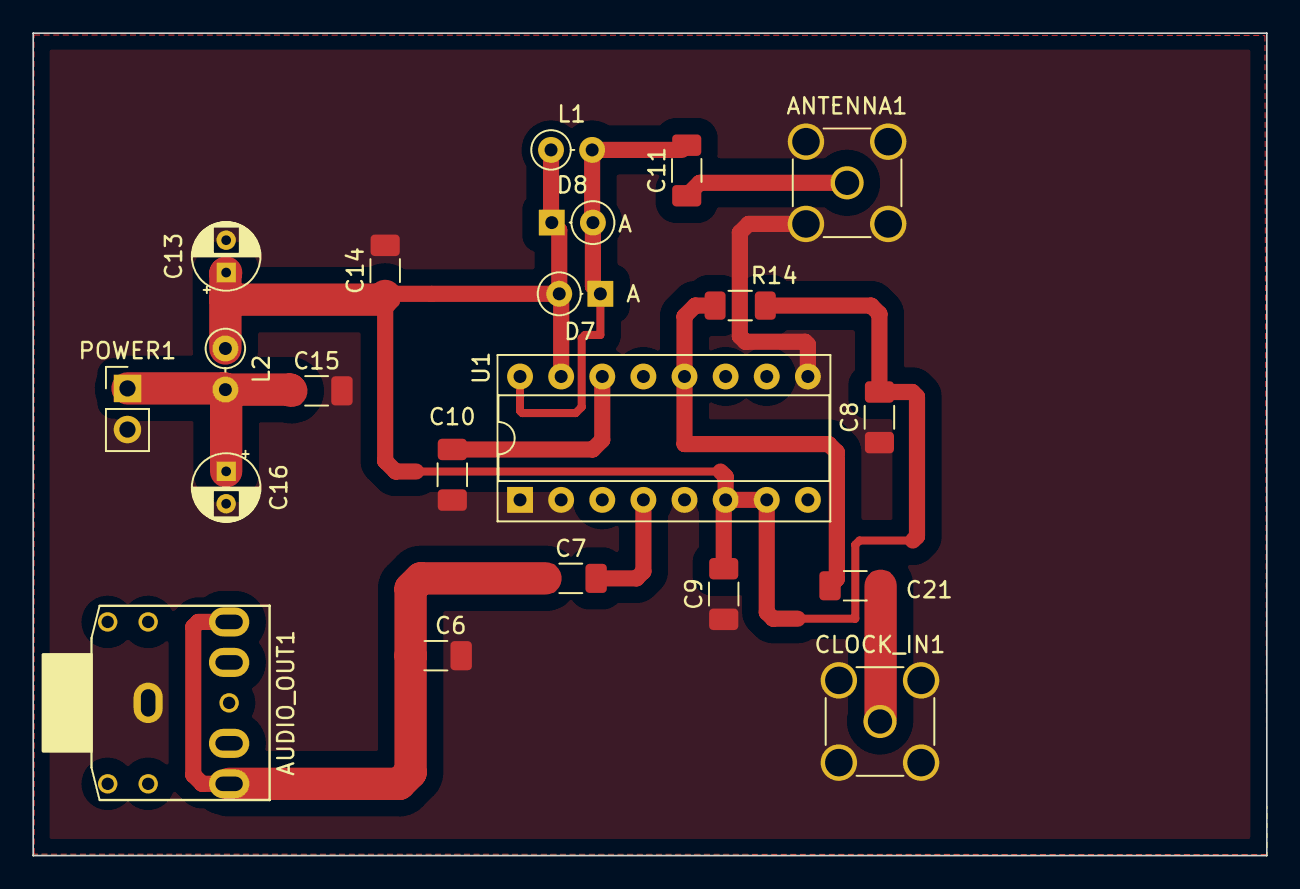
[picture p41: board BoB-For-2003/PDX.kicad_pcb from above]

Board: 2 copper layers, 76.2 x 50.8 mm, 21 parts (0 on the bottom side), 10 nets.

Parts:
ANTENNA1: RX_INPUT; SMA_Amphenol_901-144_Vertical
AUDIO_OUT1: MIC; PJ-307
C6, C8, C9, C10, C14, C15, C21: 100nF; C_1206_3216Metric_Pad1.33x1.80mm_HandSolder
C7: 470nF; C_1206_3216Metric_Pad1.33x1.80mm_HandSolder
C11: 680pF; C_1206_3216Metric_Pad1.33x1.80mm_HandSolder
C13: 10uF/16V; CP_Radial_D4.0mm_P2.00mm
C16: 100uF/16V; CP_Radial_D4.0mm_P2.00mm
CLOCK_IN1: Conn_Coaxial; SMA_Amphenol_901-144_Vertical
D7, D8: 1N4148; D_DO-35_SOD27_P2.54mm_Vertical_KathodeUp
L1: 1uH; L_Axial_L5.3mm_D2.2mm_P2.54mm_Vertical_Vishay_IM-1
L2: 100uH; L_Axial_L5.3mm_D2.2mm_P2.54mm_Vertical_Vishay_IM-1
POWER1: Conn_01x02; PinHeader_1x02_P2.54mm_Vertical
R14: 100; R_1206_3216Metric_Pad1.30x1.75mm_HandSolder
U1: CD2003GB_GP; DIP-16_W7.62mm_Socket

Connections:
+5V: C15.1, C16.1, L2.2, POWER1.1
GNDPWR: ANTENNA1.2 (Ext), AUDIO_OUT1.S, C6.2, C8.1, C9.1, C10.1, C13.2, C14.2, C15.2, C16.2, CLOCK_IN1.2 (Ext), POWER1.2, U1.1 (FM_RF_IN), U1.2 (GND_IN), U1.5 (AGC), U1.9 (GND_OUT)
unnamed: C10.2, U1.14 (FM/AM_SW)
unnamed: ANTENNA1.1 (In), C11.1
unnamed: C11.2, D7.1 (K), D8.2 (A), L1.2, U1.16 (AM_RF_IN)
unnamed: C8.2, C9.2, C13.1, C14.1, D7.2 (A), D8.1 (K), L1.1, L2.1, R14.2, U1.6 (VCC), U1.7 (AM_IF), U1.15 (FM_TUNER)
unnamed: C21.1, R14.1, U1.12 (AM_OSC)
RXA: C7.2, U1.4 (AM_MIX)
RXB: AUDIO_OUT1.R, AUDIO_OUT1.T, C6.1, C7.1
RX_OSC: C21.2, CLOCK_IN1.1 (In)

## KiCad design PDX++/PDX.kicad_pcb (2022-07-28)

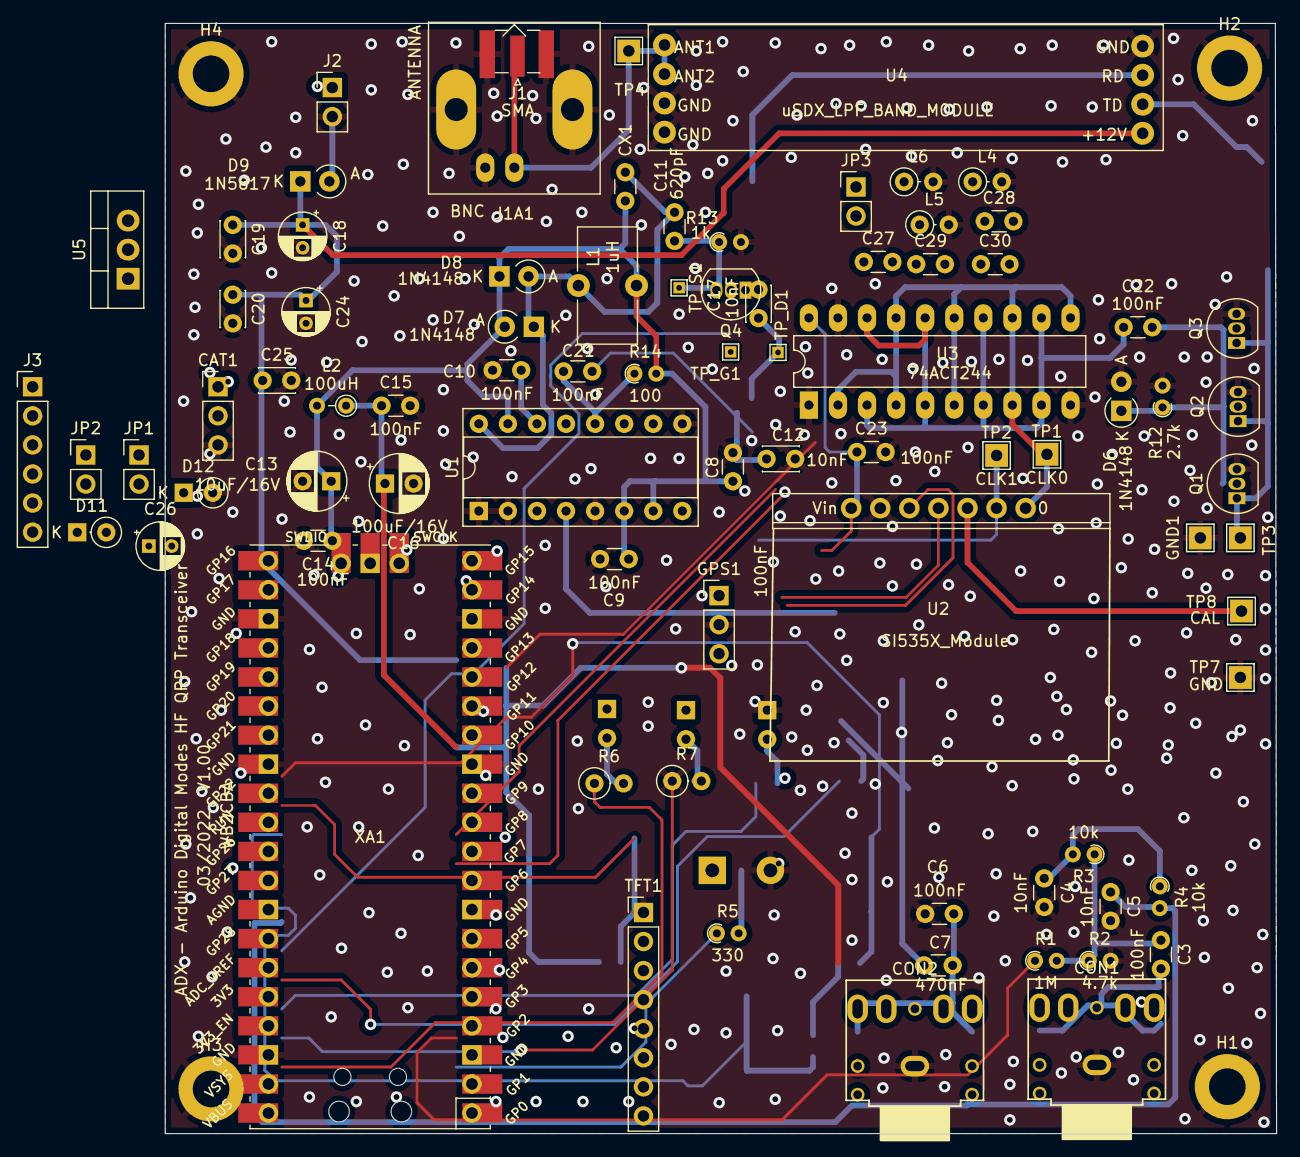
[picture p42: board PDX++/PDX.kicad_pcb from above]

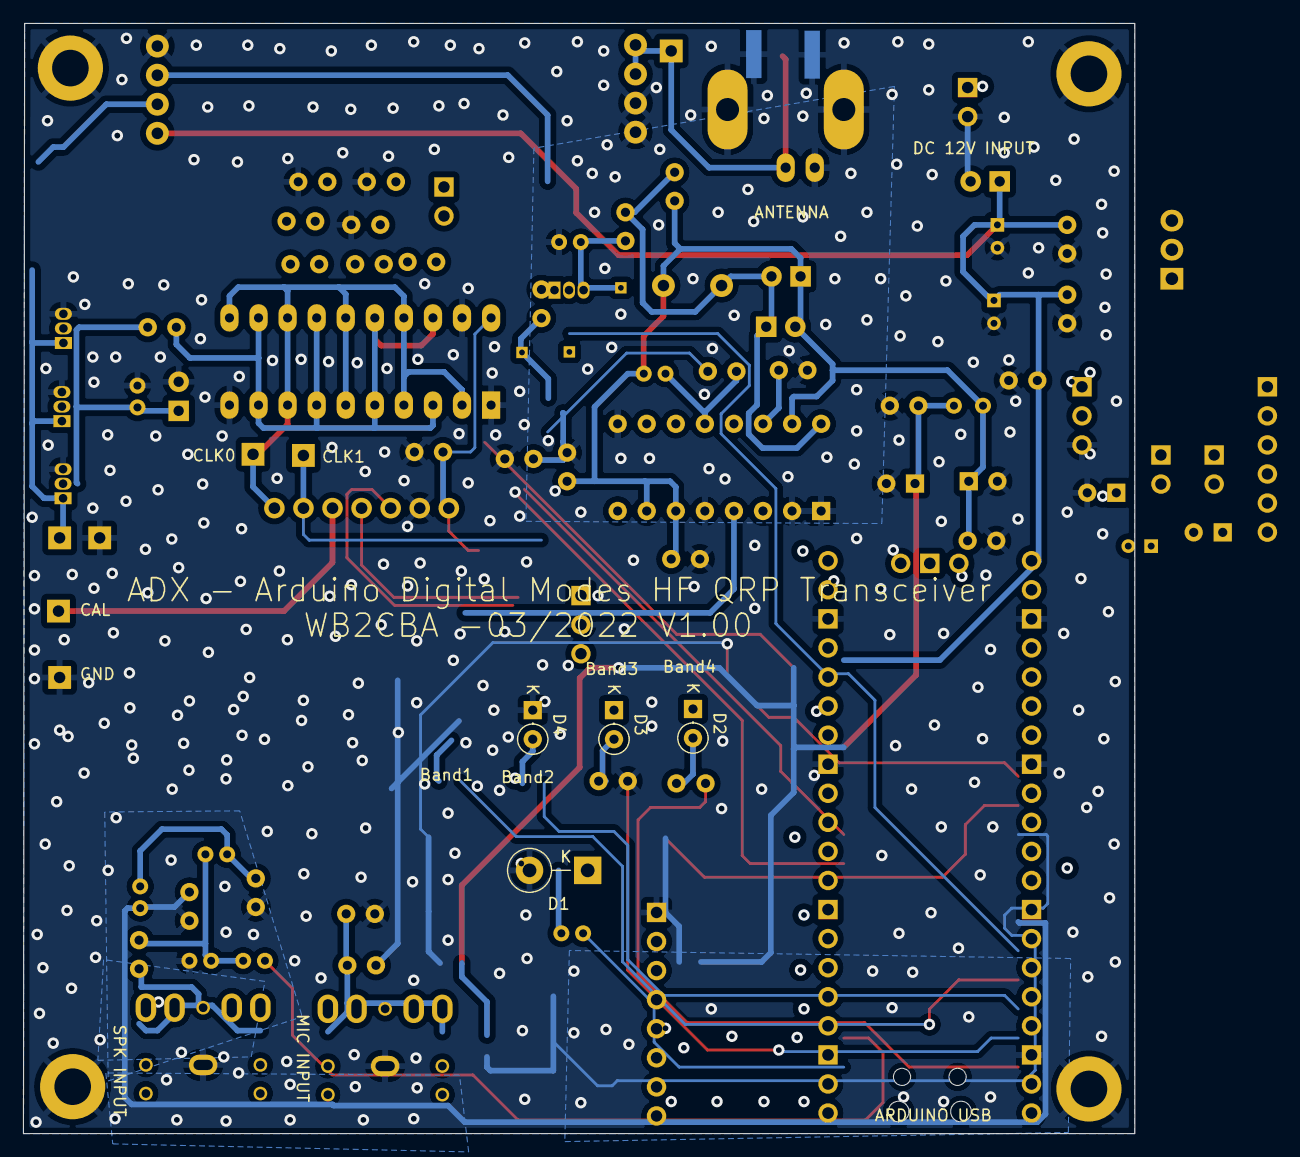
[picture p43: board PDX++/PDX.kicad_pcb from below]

Board: 2 copper layers, 97.1 x 97.0 mm, 90 parts (4 on the bottom side), 50 nets.

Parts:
C3, C6, C8, C9, C10, C14, C15, C21, C22, C23: 100nF; C_Disc_D3.0mm_W1.6mm_P2.50mm
C4, C5: 10nF; C_Disc_D3.0mm_W1.6mm_P2.50mm
C7: 470nF; C_Disc_D3.0mm_W1.6mm_P2.50mm
C11: 620pF; C_Disc_D3.0mm_W1.6mm_P2.50mm
C12, C17: 10nF; C_Disc_D3.0mm_W2.0mm_P2.50mm
C13: 10uF/16V; CP_Radial_D5.0mm_P2.50mm
C16: 100uF/16V; CP_Radial_D5.0mm_P2.50mm
C18: 10uF/16V; CP_Radial_D4.0mm_P2.00mm
C19, C20, C25: 100nF; C_Disc_D3.0mm_W2.0mm_P2.50mm
C24: 100uF/16V; CP_Radial_D4.0mm_P2.00mm
C26: 10uF; CP_Radial_D4.0mm_P2.00mm
C27, C30: 2.2nF; C_Disc_D3.0mm_W1.6mm_P2.50mm
C28, C29: 820; C_Disc_D3.0mm_W1.6mm_P2.50mm
CAT1: CAT; PinHeader_1x03_P2.54mm_Vertical
CON1: SPK; PJ-307
CON2: MIC; PJ-307
CX1: C_Disc_D3.0mm_W1.6mm_P2.50mm
D1: 5.6V 5W; D_DO-15_P5.08mm_Vertical_KathodeUp
D2: 1N4001; D_DO-35_SOD27_P2.54mm_Vertical_KathodeUp
D3, D4, D11, D12: 1N4148; D_DO-35_SOD27_P2.54mm_Vertical_KathodeUp
D6: 1N4148; D_A-405_P2.54mm_Vertical_AnodeUp
D7, D8: 1N4148; D_A-405_P2.54mm_Vertical_KathodeUp
D9: 1N5817; D_A-405_P2.54mm_Vertical_KathodeUp
GND1: TestPoint_THTPad_2.0x2.0mm_Drill1.0mm
GPS1: Conn_01x02; PinHeader_1x03_P2.54mm_Vertical
H1, H2, H3, H4: MountingHole_Pad; MountingHole_3.2mm_M3_ISO7380_Pad
J1: SMA; SMA_Samtec_SMA-J-P-X-ST-EM1_EdgeMount
J1A1: BNC; BNC_Amphenol_B6252HB-NPP3G-50_Horizontal
J2: 12v (Max 18v); PinHeader_1x02_P2.54mm_Vertical
J3: IO; PinHeader_1x06_P2.54mm_Vertical
JP1, JP2: Jumper_2_Open; PinHeader_1x02_P2.54mm_Vertical
JP3: Filter-Skip; PinHeader_1x02_P2.54mm_Vertical
L1: 1uH; L_Toroid_Vertical_L10.0mm_W5.0mm_P5.08mm
L2: 100uH; R_Axial_DIN0204_L3.6mm_D1.6mm_P2.54mm_Vertical
L4, L5, L6: 2.2uH; L_Axial_L5.3mm_D2.2mm_P2.54mm_Vertical_Vishay_IM-1
Q1, Q2, Q3, Q4: BS170; TO-92_Inline
R1: 1M; R_Axial_DIN0204_L3.6mm_D1.6mm_P1.90mm_Vertical
R2: 4.7k; R_Axial_DIN0204_L3.6mm_D1.6mm_P1.90mm_Vertical
R3, R4: 10k; R_Axial_DIN0204_L3.6mm_D1.6mm_P1.90mm_Vertical
R5: 330; R_Axial_DIN0204_L3.6mm_D1.6mm_P1.90mm_Vertical
R6, R7: 10k; R_Axial_DIN0207_L6.3mm_D2.5mm_P2.54mm_Vertical
R12: 2.7k; R_Axial_DIN0204_L3.6mm_D1.6mm_P1.90mm_Vertical
R13: 1k; R_Axial_DIN0204_L3.6mm_D1.6mm_P1.90mm_Vertical
R14: 100; R_Axial_DIN0204_L3.6mm_D1.6mm_P1.90mm_Vertical
TFT1: Conn_01x08; PinHeader_1x08_P2.54mm_Vertical
TP1: CLK0; TestPoint_THTPad_2.0x2.0mm_Drill1.0mm
TP2: CLK1; TestPoint_THTPad_2.0x2.0mm_Drill1.0mm
TP3, TP4: TestPoint; TestPoint_THTPad_2.0x2.0mm_Drill1.0mm
TP7: GND; TestPoint_THTPad_2.0x2.0mm_Drill1.0mm
TP8: CAL; TestPoint_THTPad_2.0x2.0mm_Drill1.0mm
TP_D1: TestPoint_THTPad_1.0x1.0mm_Drill0.5mm
TP_G1: TestPoint_THTPad_1.0x1.0mm_Drill0.5mm
TP_S1: TestPoint_THTPad_1.0x1.0mm_Drill0.5mm
U1: CD2003GB_GP; DIP-16_W7.62mm_Socket
U2: SI535X_Module; SI5351 Module_Vertical
U3: 74ACT244; DIP-20_W7.62mm_LongPads
U4: uSDX_LPF_BAND_MODULE; uSDX_LPF_Band_Module
U5: CDIL_7805_TO220; TO-220-3_Vertical
XA1: Pico; RPi_Pico_SMD_TH

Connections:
+3.3V: R1.1, R6.2, TFT1.8, XA1.36 (3V3)
+5V: C15.1, C16.1, C18.1, C19.1, C23.1, C25.1, D1.1 (K), D2.2 (A), J3.4, L2.1, U2.1 (VIN), U3.20 (VCC), U5.3 (VO), XA1.40 (VBUS)
FSK: C5.1, R4.2, XA1.32 (GPIO27_ADC1)
GNDPWR: C4.2, C5.2, C6.2, C8.1, C9.1, C10.1, C12.2, C13.2, C14.2, C15.2, C16.2, C18.2, C19.2, C20.2, C23.2, C24.2, C25.2, CAT1.3, CON1.S, CON2.S, D1.2 (A), D4.1 (K), D6.2 (A), D12.2 (A), GND1.1, GPS1.2, H1.1, H2.1, H3.1, H4.1, J1.2 (Ext), J1A1.2 (Ext), J2.2, J3.5, J3.6, L4.2, L5.2, L6.2, Q1.3 (S), Q2.3 (S), Q3.3 (S), R2.2, R7.1, R12.2, R13.2, TFT1.1, TP7.1, U1.1 (FM_RF_IN), U1.2 (GND_IN), U1.5 (AGC), U1.9 (GND_OUT), U2.2 (GND), U3.1 (OEa), U3.10 (GND), U3.19 (OEb), U4.4 (GND), U4.7 (GND), U4.8 (GND), U5.2 (GND), XA1.13 (GND), XA1.18 (GND), XA1.23 (GND), XA1.28 (GND), XA1.38 (GND)
unnamed: C3.1, R1.2, R2.1, R3.1
unnamed: C3.2, CON1.R, CON1.T
unnamed: C4.1, R3.2, R4.1
unnamed: C6.1, C7.1, CON2.R, CON2.T
unnamed: C10.2, U1.14 (FM/AM_SW)
unnamed: C11.1, Q4.3 (S), R13.1, TP_S1.1
unnamed: C11.2, CX1.1, D7.1 (K), D8.2 (A), L1.1, U1.16 (AM_RF_IN)
unnamed: C8.2, C9.2, C13.1, C14.1, CX1.2, D7.2 (A), D8.1 (K), L1.2, L2.2, R14.2, U1.6 (VCC), U1.7 (AM_IF), U1.15 (FM_TUNER)
unnamed: C17.1, Q4.1 (D), TP_D1.1
unnamed: C17.2, C30.2, JP3.1 (A)
unnamed: C20.1, C24.1, D2.1 (K), D9.1 (K), U4.1 (+12V), U5.1 (VI)
unnamed: C21.1, R14.1, U1.12 (AM_OSC)
unnamed: C22.1, D6.1 (K), Q1.2 (G), Q2.2 (G), Q3.2 (G), R12.1
unnamed: C22.2, U3.3 (O3b), U3.5 (O2b), U3.7 (O1b), U3.9 (O0b), U3.12 (O3a), U3.14 (O2a), U3.16 (O1a), U3.18 (O0a)
unnamed: C26.2, D3.2 (A), D11.1 (K), R5.2
unnamed: C27.2, C28.1, L4.1
unnamed: C28.2, C29.1, L5.1
unnamed: C29.2, C30.1, L6.1
unnamed: CAT1.1, XA1.16 (GPIO12)
unnamed: CAT1.2, XA1.17 (GPIO13)
unnamed: D3.1 (K), D4.2 (A)
unnamed: D9.2 (A), J2.1
unnamed: D11.2 (A), D12.1 (K)
unnamed: J1.1 (In), J1A1.1 (In), TP4.1, U4.5 (ANT1), U4.6 (ANT2)
unnamed: J3.1, XA1.27 (GPIO21)
unnamed: J3.2, XA1.26 (GPIO20)
unnamed: J3.3, XA1.25 (GPIO19)
unnamed: JP1.1 (A), XA1.31 (GPIO26_ADC0)
unnamed: JP2.1 (A), XA1.20 (GPIO15)
unnamed: JP2.2 (B), TP8.1, U2.5 (S2)
unnamed: TFT1.2, XA1.4 (GPIO2)
unnamed: TFT1.3, XA1.5 (GPIO3)
unnamed: TFT1.4, XA1.6 (GPIO4)
unnamed: TFT1.5, XA1.7 (GPIO5)
unnamed: TFT1.6, XA1.9 (GPIO6)
unnamed: TFT1.7, XA1.10 (GPIO7)
unnamed: TP1.1, U2.7 (SO), U3.2 (I0a), U3.4 (I1a), U3.6 (I2a), U3.8 (I3a), U3.11 (I0b), U3.13 (I1b), U3.15 (I2b), U3.17 (I3b)
unnamed: GPS1.1, XA1.11 (GPIO8)
RX: C27.1, JP3.2 (B), U4.3 (RD)
RXA: C7.2, R5.1, U1.4 (AM_MIX)
RXB: C26.1, JP1.2 (B), R6.1, R7.2
RXSW: C12.1, Q4.2 (G), TP_G1.1, XA1.24 (GPIO18)
RX_OSC: C21.2, TP2.1, U2.6 (S1)
SCL: U2.4 (SCL), XA1.22 (GPIO17)
SDA: U2.3 (SDA), XA1.21 (GPIO16)
TD_IN: Q1.1 (D), Q2.1 (D), Q3.1 (D), TP3.1, U4.2 (TD)

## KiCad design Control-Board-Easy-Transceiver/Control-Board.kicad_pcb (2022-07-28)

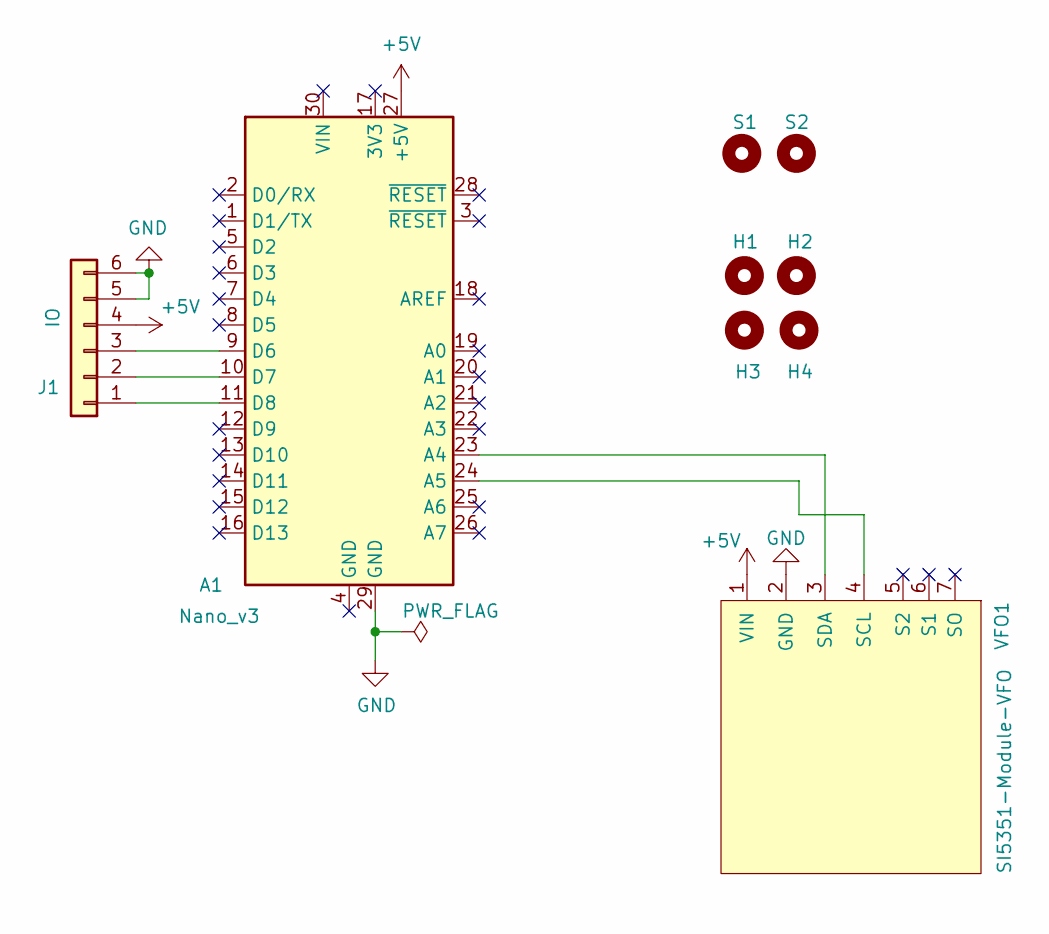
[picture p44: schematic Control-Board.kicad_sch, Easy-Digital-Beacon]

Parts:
A1: Nano_v3; Arduino_Nano
H1, H2, H3, H4: MountingHole; MountingHole_2.2mm_M2
J1: IO; PinHeader_1x06_P2.54mm_Vertical
S1, S2: MountingHole; MountingHole_2.7mm_M2.5
VFO1: SI5351-Module-VFO; PinSocket_1x07_P2.54mm_Vertical

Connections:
+5V: A1.27 (+5V), J1.4, VFO1.1 (VIN)
GND: A1.29 (GND), J1.5, J1.6, VFO1.2 (GND)
unnamed: A1.9 (D6), J1.3
unnamed: A1.10 (D7), J1.2
unnamed: A1.11 (D8), J1.1
unnamed: A1.23 (A4), VFO1.3 (SDA)
unnamed: A1.24 (A5), VFO1.4 (SCL)

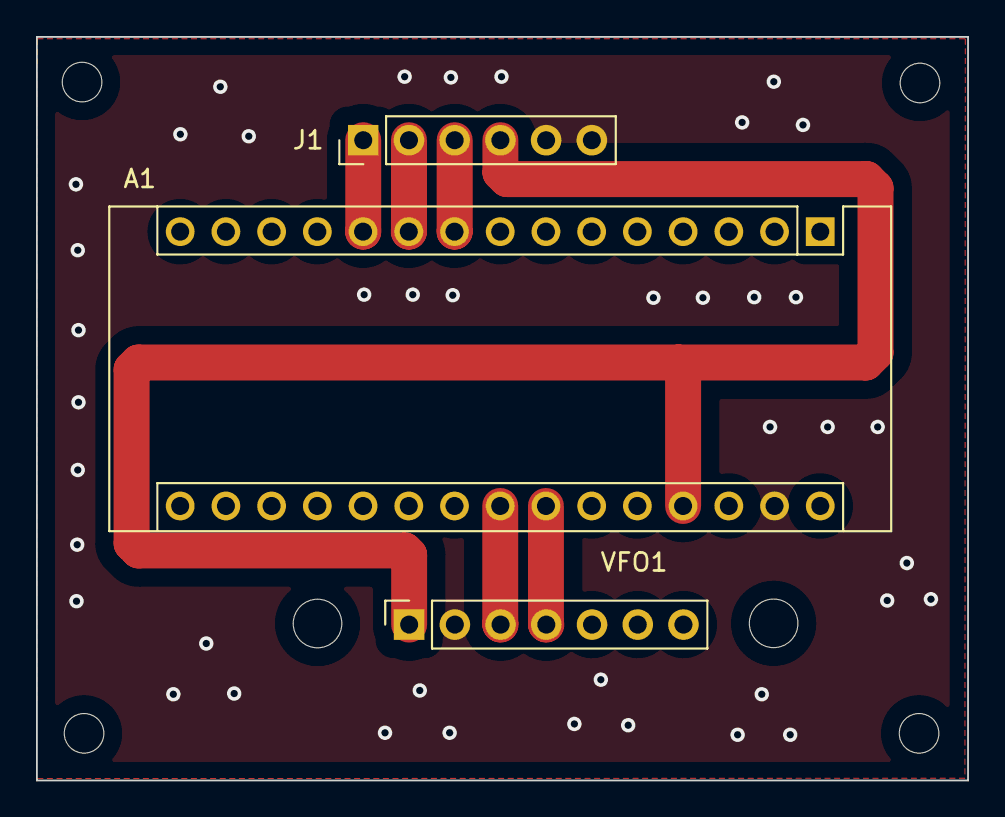
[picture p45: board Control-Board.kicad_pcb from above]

Board: 2 copper layers, 51.7 x 41.3 mm, 9 parts (0 on the bottom side), 7 nets.

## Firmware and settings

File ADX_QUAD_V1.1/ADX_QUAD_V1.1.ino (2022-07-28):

//*********************************************************************************************************
//********************* ADX - ARDUINO based DIGITAL MODES 4 BAND HF TRANSCEIVER ***************************
//********************************* Write up start: 02/01/2022 ********************************************
// FW VERSION: ADX_QUAD_V1.1 - Version release date: 04/11/2022
// Barb(Barbaros ASUROGLU) - WB2CBA - 2022
//*********************************************************************************************************
// Required Libraries
// ----------------------------------------------------------------------------------------------------------------------
// Etherkit Si5351 (Needs to be installed via Library Manager to arduino ide) - SI5351 Library by Jason Mildrum (NT7S) - https://github.com/etherkit/Si5351Arduino
// Arduino "Wire.h" I2C library(built-into arduino ide)
// Arduino "EEPROM.h" EEPROM Library(built-into arduino ide)
//*************************************[ LICENCE and CREDITS ]*********************************************
//  FSK TX Signal Generation code by: Burkhard Kainka(DK7JD) - http://elektronik-labor.de/HF/SDRtxFSK2.html
//  SI5351 Library by Jason Mildrum (NT7S) - https://github.com/etherkit/Si5351Arduino

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
//*****************[ SI5351 VFO CALIBRATION PROCEDURE ]****************************************
// For SI5351 VFO Calibration Procedure follow these steps:
// 1 - Connect CAL test point and GND test point on ADX PCB to a Frequency meter or Scope that can measure 1 Mhz up to 1Hz accurately.
// 2 - Press SW2 / --->(CAL) pushbutton and hold.
// 4-  Power up with 12V or with 5V by using arduino USB socket while still pressing SW2 / --->(CAL) pushbutton.
// 5 - FT8 and WSPR LEDs will flash 3 times and stay lit. Now Release SW2 / --->(CAL). Now Calibration mode is active.
// 6 - Using SW1(<---) and SW2(--->) pushbuttons change the Calibration frequency.
// 7 - Try to read 1 Mhz = 1000000 Hz exact on  Frequency counter or Oscilloscope.
//     The waveform is Square wave so freqency calculation can be performed esaily.
// 7 - If you read as accurate as possible 1000000 Hz then calibration is done.
// 8 - Power off ADX.

//*******************************[ LIBRARIES ]*************************************************
#include <si5351.h>
#include "Wire.h"
#include <EEPROM.h>
//*******************************[ VARIABLE DECLERATIONS ]*************************************
uint32_t val;
int temp;
uint32_t val_EE;
int addr = 0;
int mode;
unsigned long freq;
unsigned long freq1;
int32_t cal_factor;
int TX_State = 0;

unsigned long Cal_freq = 1000000UL; // Calibration Frequency: 1 Mhz = 1000000 Hz
unsigned long F_FT8;
unsigned long F_FT4;
unsigned long F_JS8;
unsigned long F_WSPR;
int Band_slot;
int Band = 0;
int UP_State;
int DOWN_State;
int TXSW_State;
int Bdly = 250;
// **********************************[ DEFINE's ]***********************************************
#define UP 2    // UP Switch
#define DOWN 3  // DOWN Switch
#define TXSW 4  // TX Switch

#define TX 13 //TX LED
#define WSPR  9 //WSPR LED
#define JS8  10 //JS8 LED
#define FT4  11 //FT4 LED
#define FT8 12 //FT8 LED

#define RX  8 // RX SWITCH
#define SI5351_REF 		25000000UL  //change this to the frequency of the crystal on your si5351’s PCB, usually 25 or 27 MHz

//**********************************[ BAND SELECT ]************************************************
// ADX can support up to 4 bands on board. Those 4 bands needs to be assigned to Band1 ... Band4 from supported 6 bands.
// To change bands press SW1 and SW2 simultaneously. Band LED will flash 3 times briefly and stay lit for the stored band. also TX LED will be lit to indicate
// that Band select mode is active. Now change band bank by pressing SW1(<---) or SW2(--->). When desired band bank is selected press TX button briefly to exit band select mode.
// Now the new selected band bank will flash 3 times and then stored mode LED will be lit.
// TX won't activate when changing bands so don't worry on pressing TX button when changing bands in band mode.

// Assign your prefered bands to B1,B2,B3 and B4
// Supported Bands are: 80m, 40m, 30m, 20m,17m, 15m

int Band1 = 40; // Band 1 // These are my default bands. Feel free to swap with yours
int Band2 = 30; // Band 2
int Band3 = 20; // Band 3
int Band4 = 17; // Band 4

Si5351 si5351;

//*************************************[ SETUP FUNCTION ]**************************************
void setup()
{
  pinMode(UP, INPUT);
  pinMode(DOWN, INPUT);
  pinMode(TXSW, INPUT);

  pinMode(TX, OUTPUT);
  pinMode(WSPR, OUTPUT);
  pinMode(JS8, OUTPUT);
  pinMode(FT4, OUTPUT);
  pinMode(FT8, OUTPUT);
  pinMode(RX, OUTPUT);

  pinMode(7, INPUT); //PD7 = AN1 = HiZ, PD6 = AN0 = 0

  INIT();

  //------------------------------- SET SI5351 VFO -----------------------------------
  // The crystal load value needs to match in order to have an accurate calibration
  si5351.init(SI5351_CRYSTAL_LOAD_8PF, 0, 0);
  si5351.set_correction(cal_factor, SI5351_PLL_INPUT_XO);
  si5351.set_pll(SI5351_PLL_FIXED, SI5351_PLLA);
  si5351.drive_strength(SI5351_CLK0, SI5351_DRIVE_8MA);// SET For Max Power
  si5351.drive_strength(SI5351_CLK1, SI5351_DRIVE_2MA); // Set for reduced power for RX

  if ( digitalRead(DOWN) == LOW ) {
    Calibration();
  }


  TCCR1A = 0x00;
  TCCR1B = 0x01; // Timer1 Timer 16 MHz
  TCCR1B = 0x81; // Timer1 Input Capture Noise Canceller
  ACSR |= (1 << ACIC); // Analog Comparator Capture Input

  pinMode(7, INPUT); //PD7 = AN1 = HiZ, PD6 = AN0 = 0
  digitalWrite(RX, LOW);

  Mode_assign();

}

//**************************[ END OF SETUP FUNCTION ]************************

//***************************[ Main LOOP Function ]**************************
void loop()
{

  UP_State = digitalRead(UP);
  DOWN_State = digitalRead(DOWN);


  if ((UP_State == LOW) && (DOWN_State == LOW) && (TX_State == 0)) {
    delay(100);
    UP_State = digitalRead(UP);
    DOWN_State = digitalRead(DOWN);
    if ((UP_State == LOW) && (DOWN_State == LOW) && (TX_State == 0)) {

      Band_Select();

    }
  }



  if ((UP_State == LOW) && (DOWN_State == HIGH) && (TX_State == 0)) {
    delay(50);

    UP_State = digitalRead(UP);
    if ((UP_State == LOW) && (DOWN_State == HIGH) && (TX_State == 0)) {
      mode = mode - 1;

      if (mode < 1) {
        mode = 4;
      }



      addr = 40;
      EEPROM.put(addr, mode);
      Mode_assign();

    }
  }

  DOWN_State = digitalRead(DOWN);

  if ((UP_State == HIGH) && (DOWN_State == LOW) && (TX_State == 0)) {
    delay(50);

    DOWN_State = digitalRead(DOWN);
    if ((UP_State == HIGH) && (DOWN_State == LOW) && (TX_State == 0)) {
      mode = mode + 1;

      if (mode > 4) {
        mode = 1;
      }



      addr = 40;
      EEPROM.put(addr, mode);
      Mode_assign();

    }
  }

  TXSW_State = digitalRead(TXSW);

  if ((TXSW_State == LOW) && (TX_State == 0)) {
    delay(50);

    TXSW_State = digitalRead(TXSW);
    if ((TXSW_State == LOW) && (TX_State == 0)) {

      Mode_assign();

      ManualTX();

    }

  }

  unsigned int d1, d2;
  int FSK = 10;
  int FSKtx = 0;
  while (FSK > 0) {
    TCNT1 = 0;
    while (ACSR & (1 << ACO)) {
      if (TCNT1 > 65000) {
        break;
      }
    }  while ((ACSR & (1 << ACO)) == 0) {
      if (TCNT1 > 65000) {
        break;
      }
    }
    TCNT1 = 0;
    while (ACSR & (1 << ACO)) {
      if (TCNT1 > 65000) {
        break;
      }
    }
    d1 = ICR1;
    while ((ACSR & (1 << ACO)) == 0) {
      if (TCNT1 > 65000) {
        break;
      }
    }
    while (ACSR & (1 << ACO)) {
      if (TCNT1 > 65000) {
        break;
      }
    }
    d2 = ICR1;
    if (TCNT1 < 65000) {
      unsigned long codefreq = 1600000000 / (d2 - d1);
      if (codefreq < 350000) {
        if (FSKtx == 0) {
          TX_State = 1;
          digitalWrite(TX, HIGH);
          digitalWrite(RX, LOW);

          si5351.output_enable(SI5351_CLK1, 0);   //RX off
          si5351.output_enable(SI5351_CLK0, 1);   // TX on
        }
        si5351.set_freq((freq * 100 + codefreq), SI5351_CLK0);

        FSKtx = 1;
      }
    }
    else {
      FSK--;
    }
  }
  digitalWrite(TX, 0);

  si5351.output_enable(SI5351_CLK0, 0);   //TX off
  si5351.set_freq(freq * 100ULL, SI5351_CLK1);
  si5351.output_enable(SI5351_CLK1, 1);   //RX on
  TX_State = 0;
  digitalWrite(RX, HIGH);
  FSKtx = 0;


}
//*********************[ END OF MAIN LOOP FUNCTION ]*************************

//********************************************************************************
//******************************** [ FUNCTIONS ] *********************************
//********************************************************************************


//************************************[ MODE Assign ]**********************************

void Mode_assign() {

  addr = 40;
  EEPROM.get(addr, mode);


  if ( mode == 1) {
    freq1 = F_WSPR;
    digitalWrite(WSPR, HIGH);
    digitalWrite(JS8, LOW);
    digitalWrite(FT4, LOW);
    digitalWrite(FT8, LOW);

  }

  if ( mode == 2) {
    freq1 = F_JS8;
    digitalWrite(WSPR, LOW);
    digitalWrite(JS8, HIGH);
    digitalWrite(FT4, LOW);
    digitalWrite(FT8, LOW);



  }

  if ( mode == 3) {
    freq1 = F_FT4;

    digitalWrite(WSPR, LOW);
    digitalWrite(JS8, LOW);
    digitalWrite(FT4, HIGH);
    digitalWrite(FT8, LOW);


  }
  if ( mode == 4) {
    freq1 = F_FT8;

    digitalWrite(WSPR, LOW);
    digitalWrite(JS8, LOW);
    digitalWrite(FT4, LOW);
    digitalWrite(FT8, HIGH);


  }
  freq = freq1;
  //freq = freq1 - 1000;

}

//********************************[ END OF MODE ASSIGN ]*******************************

//*********************[ Band dependent Frequency Assign Function ]********************
void Freq_assign() {


  //---------- 80m/3.5Mhz
  if (Band == 80) {

    F_FT8 = 3573000;
    F_FT4 = 3575000;
    F_JS8 = 3578000;
    F_WSPR = 3568600;
  }

  //---------- 40m/7 Mhz
  if (Band == 40) {

    F_FT8 = 7074000;
    F_FT4 = 7047500;
    F_JS8 = 7078000;
    F_WSPR = 7038600;
  }


  //---------- 30m/10 Mhz
  if (Band == 30) {

    F_FT8 = 10136000;
    F_FT4 = 10140000;
    F_JS8 = 10130000;
    F_WSPR = 10138700;
  }


  //---------- 20m/14 Mhz
  if (Band == 20) {

    F_FT8 = 14074000;
    F_FT4 = 14080000;
    F_JS8 = 14078000;
    F_WSPR = 14095600;
  }


  //---------- 17m/18 Mhz
  if (Band == 17) {

    F_FT8 = 18100000;
    F_FT4 = 18104000;
    F_JS8 = 18104000;
    F_WSPR = 18104600;
  }

  //---------- 15m/ 21Mhz
  if (Band == 15) {

    F_FT8 = 21074000;
    F_FT4 = 21140000;
    F_JS8 = 21078000;
    F_WSPR = 21094600;
  }

}
//************************[ End of Frequency assign function ]*************************

//******************************[ Band  Assign Function ]******************************

void Band_assign() {
  digitalWrite(WSPR, LOW);
  digitalWrite(JS8, LOW);
  digitalWrite(FT4, LOW);
  digitalWrite(FT8, LOW);


  addr = 50;
  EEPROM.get(addr, Band_slot);

  if (Band_slot == 1) {
    Band = Band1;

    digitalWrite(WSPR, HIGH);
    delay(Bdly);
    digitalWrite(WSPR, LOW);
    delay(Bdly);
    digitalWrite(WSPR, HIGH);
    delay(Bdly);
    digitalWrite(WSPR, LOW);
    delay(Bdly);
    digitalWrite(WSPR, HIGH);
    delay(Bdly);
    digitalWrite(WSPR, LOW);
    delay(Bdly);
  }

  if (Band_slot == 2) {
    Band = Band2;

    digitalWrite(JS8, HIGH);
    delay(Bdly);
    digitalWrite(JS8, LOW);
    delay(Bdly);
    digitalWrite(JS8, HIGH);
    delay(Bdly);
    digitalWrite(JS8, LOW);
    delay(Bdly);
    digitalWrite(JS8, HIGH);
    delay(Bdly);
    digitalWrite(JS8, LOW);
    delay(Bdly);
  }

  if (Band_slot == 3) {
    Band = Band3;

    digitalWrite(FT4, HIGH);
    delay(Bdly);
    digitalWrite(FT4, LOW);
    delay(Bdly);
    digitalWrite(FT4, HIGH);
    delay(Bdly);
    digitalWrite(FT4, LOW);
    delay(Bdly);
    digitalWrite(FT4, HIGH);
    delay(Bdly);
    digitalWrite(FT4, LOW);
    delay(Bdly);
  }

  if (Band_slot == 4) {
    Band = Band4;

    digitalWrite(FT8, HIGH);
    delay(Bdly);
    digitalWrite(FT8, LOW);
    delay(Bdly);
    digitalWrite(FT8, HIGH);
    delay(Bdly);
    digitalWrite(FT8, LOW);
    delay(Bdly);
    digitalWrite(FT8, HIGH);
    delay(Bdly);
    digitalWrite(FT8, LOW);
    delay(Bdly);
  }


  delay(1000);

  Freq_assign();

  Mode_assign();


}
//***************************[ End of Band assign function ]***************************


//*******************************[ Manual TX FUNCTION ]********************************
void ManualTX() {

  digitalWrite(RX, LOW);
  si5351.output_enable(SI5351_CLK1, 0);   //RX off


TXON:

  TXSW_State = digitalRead(TXSW);


  digitalWrite(TX, 1);
  si5351.set_freq(freq1 * 100ULL, SI5351_CLK0);
  si5351.output_enable(SI5351_CLK0, 1);   //TX on
  TX_State = 1;

  if (TXSW_State == HIGH) {
    goto EXIT_TX;

  }
  goto TXON;




EXIT_TX:
  digitalWrite(TX, 0);
  si5351.output_enable(SI5351_CLK0, 0);   //TX off
  TX_State = 0;

}

//********************************[ END OF Manual TX ]*********************************

//******************************[ BAND SELECT Function]********************************
void Band_Select() {

  digitalWrite(TX, 1);
  addr = 50;
  EEPROM.get(addr, Band_slot);

  digitalWrite(WSPR, LOW);
  digitalWrite(JS8, LOW);
  digitalWrite(FT4, LOW);
  digitalWrite(FT8, LOW);


  if (Band_slot == 1) {


    digitalWrite(WSPR, HIGH);
    delay(Bdly);
    digitalWrite(WSPR, LOW);
    delay(Bdly);
    digitalWrite(WSPR, HIGH);
    delay(Bdly);
    digitalWrite(WSPR, LOW);
    delay(Bdly);
    digitalWrite(WSPR, HIGH);
    delay(Bdly);
    digitalWrite(WSPR, LOW);
    delay(Bdly);
  }

  if (Band_slot == 2) {

    digitalWrite(JS8, HIGH);
    delay(Bdly);
    digitalWrite(JS8, LOW);
    delay(Bdly);
    digitalWrite(JS8, HIGH);
    delay(Bdly);
    digitalWrite(JS8, LOW);
    delay(Bdly);
    digitalWrite(JS8, HIGH);
    delay(Bdly);
    digitalWrite(JS8, LOW);
    delay(Bdly);
  }

  if (Band_slot == 3) {

    digitalWrite(FT4, HIGH);
    delay(Bdly);
    digitalWrite(FT4, LOW);
    delay(Bdly);
    digitalWrite(FT4, HIGH);
    delay(Bdly);
    digitalWrite(FT4, LOW);
    delay(Bdly);
    digitalWrite(FT4, HIGH);
    delay(Bdly);
    digitalWrite(FT4, LOW);
    delay(Bdly);
  }

  if (Band_slot == 4) {

    digitalWrite(FT8, HIGH);
    delay(Bdly);
    digitalWrite(FT8, LOW);
    delay(Bdly);
    digitalWrite(FT8, HIGH);
    delay(Bdly);
    digitalWrite(FT8, LOW);
    delay(Bdly);
    digitalWrite(FT8, HIGH);
    delay(Bdly);
    digitalWrite(FT8, LOW);
    delay(Bdly);
  }

Band_cont:

  if (Band_slot == 1) {


    digitalWrite(WSPR, HIGH);
    digitalWrite(JS8, LOW);
    digitalWrite(FT4, LOW);
    digitalWrite(FT8, LOW);
  }

  if (Band_slot == 2) {


    digitalWrite(JS8, HIGH);
    digitalWrite(WSPR, LOW);
    digitalWrite(FT4, LOW);
    digitalWrite(FT8, LOW);

  }

  if (Band_slot == 3) {
    digitalWrite(FT4, HIGH);
    digitalWrite(WSPR, LOW);
    digitalWrite(JS8, LOW);
    digitalWrite(FT8, LOW);



  }

  if (Band_slot == 4) {
    digitalWrite(JS8, LOW);
    digitalWrite(WSPR, LOW);
    digitalWrite(FT4, LOW);
    digitalWrite(FT8, HIGH);

  }


  UP_State = digitalRead(UP);
  DOWN_State = digitalRead(DOWN);

  if ((UP_State == LOW) && (DOWN_State == HIGH)) {
    delay(100);

    UP_State = digitalRead(UP);
    if ((UP_State == LOW) && (DOWN_State == HIGH)) {
      Band_slot = Band_slot - 1;

      if (Band_slot < 1) {
        Band_slot = 4;
      }
    }
  }

  if ((UP_State == HIGH) && (DOWN_State == LOW)) {
    delay(100);

    DOWN_State = digitalRead(DOWN);
    if ((UP_State == HIGH) && (DOWN_State == LOW)) {
      Band_slot = Band_slot + 1;

      if (Band_slot > 4) {
        Band_slot = 1;
      }
    }
  }


  TX_State = digitalRead(TXSW);

  if (TX_State == LOW) {
    delay(100);

    TX_State = digitalRead(TXSW);
    if (TX_State == LOW) {

      digitalWrite(TX, 0);

      goto Band_exit;

    }
  }

  goto Band_cont;

Band_exit:

  addr = 50;
  EEPROM.put(addr, Band_slot);


  Band_assign();


}

//*********************************[ END OF BAND SELECT ]*****************************




//************************** [SI5351 VFO Calibration Function] ************************

void Calibration() {

  digitalWrite(FT8, LOW);
  digitalWrite(FT4, LOW);
  digitalWrite(JS8, LOW);
  digitalWrite(WSPR, LOW);

  digitalWrite(WSPR, HIGH);
  digitalWrite(FT8, HIGH);
  delay(100);

  digitalWrite(WSPR, LOW);
  digitalWrite(FT8, LOW);
  delay(100);


  digitalWrite(WSPR, HIGH);
  digitalWrite(FT8, HIGH);
  delay(100);

  digitalWrite(WSPR, LOW);
  digitalWrite(FT8, LOW);
  delay(100);

  digitalWrite(WSPR, HIGH);
  digitalWrite(FT8, HIGH);
  delay(100);

  digitalWrite(WSPR, LOW);
  digitalWrite(FT8, LOW);
  delay(100);

  digitalWrite(WSPR, HIGH);
  digitalWrite(FT8, HIGH);
  delay(100);

  digitalWrite(WSPR, LOW);
  digitalWrite(FT8, LOW);
  delay(100);

  digitalWrite(WSPR, HIGH);
  digitalWrite(FT8, HIGH);

  addr = 10;
  EEPROM.get(addr, cal_factor);
  //Serial.print("cal factor= ");

Calibrate:

  UP_State = digitalRead(UP);

  if (UP_State == LOW) {
    delay(50);

    UP_State = digitalRead(UP);
    if (UP_State == LOW) {

      cal_factor = cal_factor - 100;

      EEPROM.put(addr, cal_factor);

      si5351.set_correction(cal_factor, SI5351_PLL_INPUT_XO);


      // Set CLK2 output
      si5351.set_freq(Cal_freq * 100, SI5351_CLK2);
      si5351.drive_strength(SI5351_CLK2, SI5351_DRIVE_2MA); // Set for lower power for calibration
      si5351.set_clock_pwr(SI5351_CLK2, 1); // Enable the clock for calibration


    }
  }

  DOWN_State = digitalRead(DOWN);

  if (DOWN_State == LOW) {
    delay(50);

    DOWN_State = digitalRead(DOWN);
    if (DOWN_State == LOW) {

      cal_factor = cal_factor + 100;
      EEPROM.put(addr, cal_factor);

      si5351.set_correction(cal_factor, SI5351_PLL_INPUT_XO);

      // Set CLK2 output
      si5351.set_freq(Cal_freq * 100, SI5351_CLK2);
      si5351.drive_strength(SI5351_CLK2, SI5351_DRIVE_2MA); // Set for lower power for Calibration
      si5351.set_clock_pwr(SI5351_CLK2, 1); // Enable clock2

    }
  }

  goto Calibrate;
}

//****************************** [ End Of Calibration Function ]****************************************

//*********************************[ INITIALIZATION FUNCTION ]******************************************
void INIT() {

  addr = 30;
  EEPROM.get(addr, temp);

  if (temp != 100) {

    addr = 10;
    cal_factor = 100000;
    EEPROM.put(addr, cal_factor);

    addr = 40;
    temp = 4;
    EEPROM.put(addr, temp);

    addr = 30;
    temp = 100;
    EEPROM.put(addr, temp);

    addr = 50;
    temp = 1;
    EEPROM.put(addr, temp);

  }

  else

  {
    //--------------- EEPROM INIT VALUES
    addr = 30;
    EEPROM.get(addr, temp);

    addr = 10;
    EEPROM.get(addr, cal_factor);

    addr = 40;
    EEPROM.get(addr, mode);

    addr = 50;
    EEPROM.get(addr, Band_slot);


  }

  Band_assign();

  Freq_assign();

  Mode_assign();

  si5351.set_clock_pwr(SI5351_CLK2, 0); // Turn off Calibration Clock

}
//********************************[ END OF INITIALIZATION FUNCTION ]*************************************

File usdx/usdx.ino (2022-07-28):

//  QCX-SSB.ino - https://github.com/threeme3/QCX-SSB
//
//  Copyright 2019, 2020, 2021   Guido PE1NNZ <pe1nnz@amsat.org>
//
//  Permission is hereby granted, free of charge, to any person obtaining a copy of this software and associated documentation files (the "Software"), to deal in the Software without restriction, including without limitation the rights to use, copy, modify, merge, publish, distribute, sublicense, and/or sell copies of the Software, and to permit persons to whom the Software is furnished to do so, subject to the following conditions: The above copyright notice and this permission notice shall be included in all copies or substantial portions of the Software. THE SOFTWARE IS PROVIDED "AS IS", WITHOUT WARRANTY OF ANY KIND, EXPRESS OR IMPLIED, INCLUDING BUT NOT LIMITED TO THE WARRANTIES OF MERCHANTABILITY, FITNESS FOR A PARTICULAR PURPOSE AND NONINFRINGEMENT. IN NO EVENT SHALL THE AUTHORS OR COPYRIGHT HOLDERS BE LIABLE FOR ANY CLAIM, DAMAGES OR OTHER LIABILITY, WHETHER IN AN ACTION OF CONTRACT, TORT OR OTHERWISE, ARISING FROM, OUT OF OR IN CONNECTION WITH THE SOFTWARE OR THE USE OR OTHER DEALINGS IN THE SOFTWARE.

#define VERSION   "1.02w"

// Configuration switches; remove/add a double-slash at line-start to enable/disable a feature; to save space disable e.g. CAT, DIAG, KEYER
//#define DIAG             0   // Hardware diagnostics on startup (only disable when your rig is working)
//#define KEYER            1   // CW keyer
#define CAT              1   // CAT-interface
// #define F_XTAL    27005000   // 27MHz SI5351 crystal
//#define F_XTAL  25004000   // 25MHz SI5351 crystal  (enable for WB2CBA-uSDX, SI5351 break-out board or uSDXDuO)
#define F_XTAL  25000000   // 25MHz SI5351 crystal  (enable for 25MHz TCXO)
//#define SWAP_ROTARY    1   // Swap rotary direction (enable for WB2CBA-uSDX)
//#define QCX            1   // Supports older (non-SDR) QCX HW modifications (QCX, QCX-SSB, QCX-DSP with I/Q alignment-feature)
#define OLED_SSD1306   1   // OLED display (SSD1306 128x32 or 128x64), connect SDA (PD2), SCL (PD3)
//#define OLED_SH1106    1   // OLED display (SH1106 1.3" inch display), connect SDA (PD2), SCL (PD3), NOTE that this display is pretty slow
//#define LCD_I2C        1   // LCD with I2C (PCF8574 module          ), connect SDA (PD2), SCL (PD3), NOTE that this display is pretty slow
//#define LPF_SWITCHING_DL2MAN_USDX_REV3           1   // Enable 8-band filter bank switching:     latching relays wired to a TCA/PCA9555 GPIO extender on the PC4/PC5 I2C bus; relays are using IO0.0 as common (ground), IO1.0..7 used by the individual latches K0-7 switching respectively LPFs for 10m, 15m, 17m, 20m, 30m, 40m, 60m, 80m
//#define LPF_SWITCHING_DL2MAN_USDX_REV3_NOLATCH 1   // Enable 8-band filter bank switching: non-latching relays wired to a TCA/PCA9555 GPIO extender on the PC4/PC5 I2C bus; relays are using IO0.0 as common (ground), IO1.0..7 used by the individual latches K0-7 switching respectively LPFs for 10m, 15m, 17m, 20m, 30m, 40m, 60m, 80m. Enable this if you are using 8-band non-latching version for the relays, the radio will draw extra 15mA current but will work ity any relay (Tnx OH2UDS/TA7W Baris)
//#define LPF_SWITCHING_DL2MAN_USDX_REV2         1   // Enable 5-band filter bank switching:     latching relays wired to a TCA/PCA9555 GPIO extender on the PC4/PC5 I2C bus; relays are using IO0.1 as common (ground), IO0.3, IO0.5, IO0.7, IO1.1, IO1.3 used by the individual latches K1-5 switching respectively LPFs for 20m, 30m, 40m, 60m, 80m
//#define LPF_SWITCHING_DL2MAN_USDX_REV2_BETA    1   // Enable 5-band filter bank switching:     latching relays wired to a PCA9539PW   GPIO extender on the PC4/PC5 I2C bus; relays are using IO0.1 as common (ground), IO0.3, IO0.5, IO0.7, IO1.1, IO1.3 used by the individual latches K1-5 switching respectively LPFs for 20m, 30m, 40m, 60m, 80m
//#define LPF_SWITCHING_DL2MAN_USDX_REV1         1   // Enable 3-band filter bank switching:     latching relays wired to a PCA9536D    GPIO extender on the PC4/PC5 I2C bus; relays are using IO0 as common (ground), IO1-IO3 used by the individual latches K1-3 switching respectively LPFs for 20m, 40m, 80m
//#define LPF_SWITCHING_WB2CBA_USDX_OCTOBAND     1   // Enable 8-band filter bank switching: non-latching relays wired to a MCP23008    GPIO extender on the PC4/PC5 I2C bus; relays are using GND as common (ground), GP0..7 used by the individual latches K1-8 switching respectively LPFs for 80m, 60m, 40m, 30m, 20m, 17m, 15m, 10m
//#define LPF_SWITCHING_PE1DDA_USDXDUO           14  // Enable 2-band filter bank switching: non-latching relay  wired to pin PD5 (pin 11); specify as value the frequency in MHz for which (and above) the relay should be altered (e.g. put 14 to enable the relay at 14MHz and above to use the 20m LPF).
#define SI5351_ADDR   0x60   // SI5351A I2C address: 0x60 for SI5351A-B-GT, Si5351A-B04771-GT, MS5351M; 0x62 for SI5351A-B-04486-GT; 0x6F for SI5351A-B02075-GT; see here for other variants: https://www.silabs.com/TimingUtility/timing-download-document.aspx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
//#define F_MCU   16000000   // 16MHz ATMEGA328P crystal (enable for unmodified Arduino Uno/Nano boards with 16MHz crystal). You may change this value to any other crystal frequency (up to 28MHz may work)
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

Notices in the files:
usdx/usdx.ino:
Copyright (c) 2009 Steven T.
